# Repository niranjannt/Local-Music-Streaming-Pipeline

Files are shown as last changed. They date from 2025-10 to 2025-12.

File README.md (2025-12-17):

# Local Music Streaming Pipeline (ECE 445L Final Project)

This repository contains the final project for **Embedded Design Laboratory (ECE 445L)** at **UT Austin**, developed by Niranjan Telkikar, Ashton Knecht, Thompson Truong, and Nathan DeLaRosa. The project implements a music-streaming pipeline using local WAV files, combining frontend/backend software with embedded hardware.

## Project Overview

Our system streams music from a web interface to an **ESP32-Devkit-V1** and outputs audio through a **12-bit SPI DAC** connected to a headphone jack. The pipeline includes both **analog and digital filters** controlled in real-time by circular potentiometers, allowing adjustment of treble, mid, bass, and digital effects such as flanger, distortion, and reverb.

### Pipeline Flow

1. **Web Interface**: Streams WAV files via Java Serial library to the ESP32 through a USB-UART converter.  
2. **ESP32**: Receives serial data and sends it to the SPI DAC (mono channel). It also handles digital filter adjustments.  
3. **DAC**: Outputs analog audio to headphones.  
4. **TM4C123GH6PM**: Reads potentiometer inputs for analog filters and adjusts MOSFET gain circuits for treble, mid, and bass channels in real-time.  
5. **Visualizer**: Displays right-bass changes in real-time using ADC input from the TM4C.

---

## Team Contributions

- **Ashton Knecht**:  
  - Designed and soldered the PCB with ESP32-Devkit-V1.  
  - Implemented MOSFET gain circuits for analog filters.  
  - Carefully routed PCB to minimize trace length.

- **Thompson Truong**:  
  - Designed the enclosure and circular potentiometers for analog and digital filter control.  
  - Developed ESP-IDF code for digital filters on the ESP32 and analog filters on the TM4C.

- **Nathan DeLaRosa**:  
  - Implemented audio playback and backend/frontend for the web interface.  
  - Wrote ESP-IDF code for streaming audio.

- **Niranjan Telkikar**:  
  - Wrote and tested the **mono DAC_Out function** for the ESP32 (Arduino IDE/ESP-IDF).  
  - Developed a basic visualizer for real-time bass monitoring.  
  - Assisted with hardware debugging and ESP-IDF integration.

---

## Hardware Components

- ESP32-Devkit-V1  
- TM4C123GH6PM microcontroller  
- 12-bit SPI DAC (mono)  
- MOSFET-based analog gain circuits  
- Circular potentiometers for analog and digital filters  
- Headphone jack for output audio

---

## Software Components

- Arduino IDE / ESP-IDF framework for microcontroller programming  
- Java Serial library for web-to-ESP32 streaming  
- Frontend/backend web interface for music streaming  
- Real-time visualizer reading ADC inputs from TM4C

---

## Usage

1. Connect the ESP32 and TM4C to your computer via USB.  
2. Launch the web interface to stream WAV files.  
3. Adjust analog and digital filters using the circular potentiometers.  
4. Observe audio output through headphones and visualizer display.

---

## [Download a demo video of the project here!](Embedded-Lab-Final-Project-Demo.mp4)

## Acknowledgements

This project was completed as part of **ECE 445L: Embedded Design Laboratory** at **UT Austin**.

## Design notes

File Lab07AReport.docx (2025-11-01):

Name: __Nathan DeLaRosa, Ashton Knecht, Thompson Truong, Niranjan Telkikar

EID: __nad2333, atk836, TT27224, NNT479_____

Semester: Fall 2025

Course: ECE445L

All team members have reviewed and approved team skills contract (https://users.ece.utexas.edu/~valvano/EE445L/ebook/Chapter3_HumanInterfaces.htm) (Yes/No):

https://docs.google.com/document/d/1b0H_l2s_C3Buwb_I0p0ZEJCIzjKjUqObAgL3oR6PWzI/edit?usp=sharing

Deliverable 1: I have pushed my updated Requirements document to GitHub (Yes/No):

Yes

Deliverable 2: I have pushed my KiCad preliminary schematic to GitHub (Yes/No):

Yes

Deliverable 3: I have pushed my updated BOM to GitHub (Yes/No):

Yes

Deliverable 4: List the needed supply voltages and estimated current for each voltage (show how these were determined).

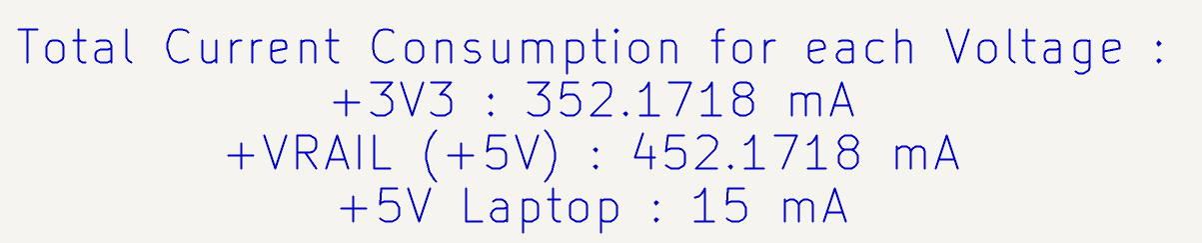
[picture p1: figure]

How estimated currents were determined (On the Schematic)

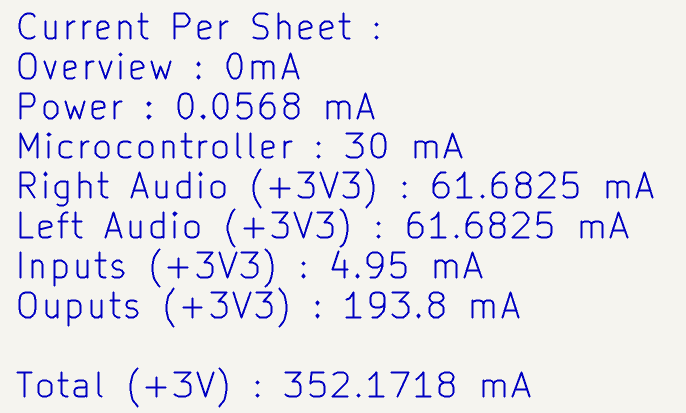
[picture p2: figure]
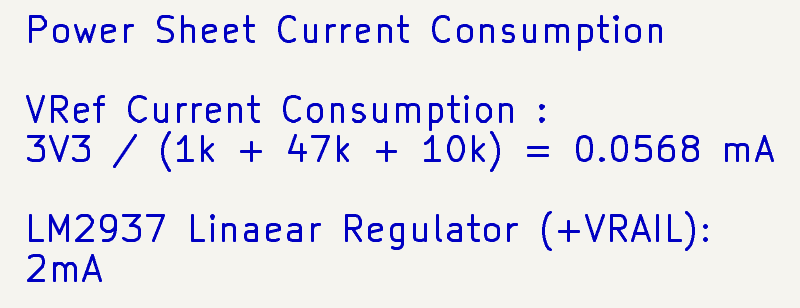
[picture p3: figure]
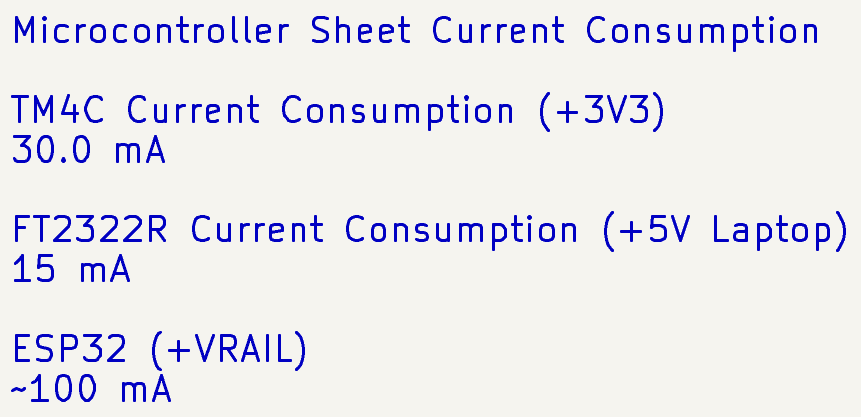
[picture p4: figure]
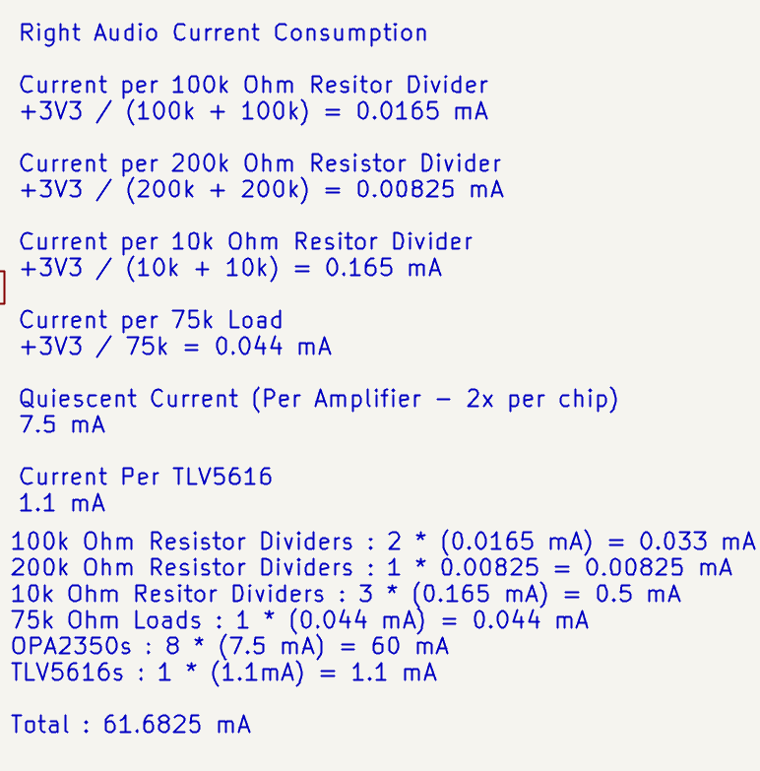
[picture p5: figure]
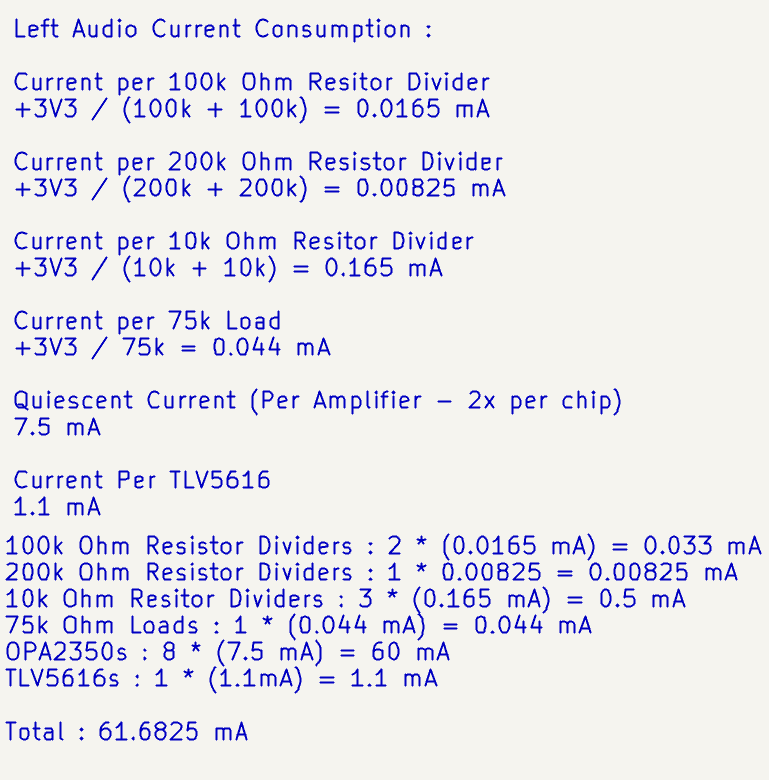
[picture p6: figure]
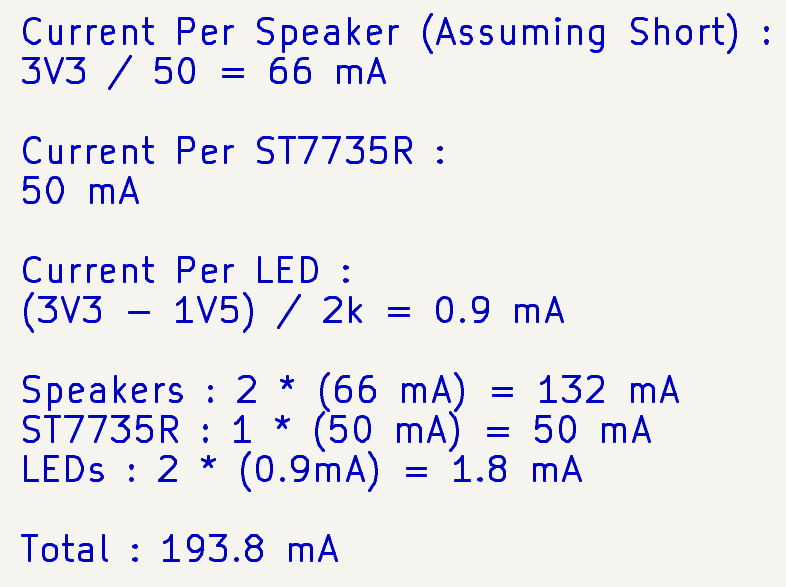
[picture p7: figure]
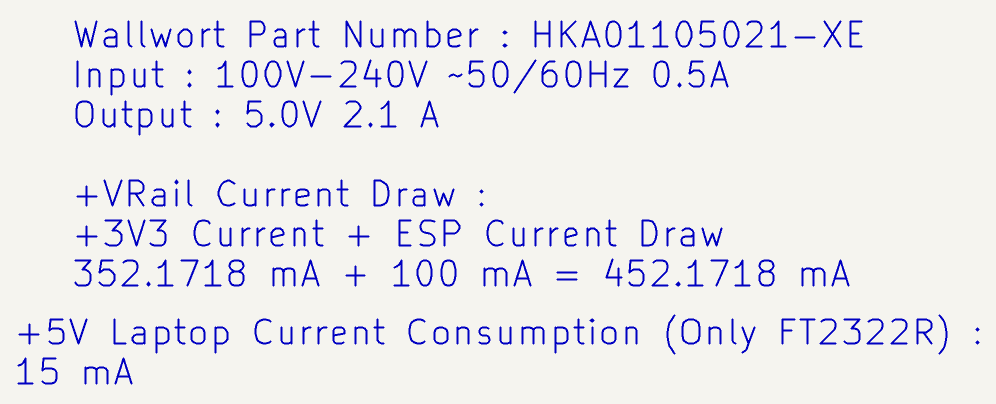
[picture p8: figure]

Deliverable 5: I have pushed my low-level header, code, and unit test files to GitHub (Yes/No):

Yes

Deliverable 6: Include results of unit testing.

Testing of bass channel with increasing frequency

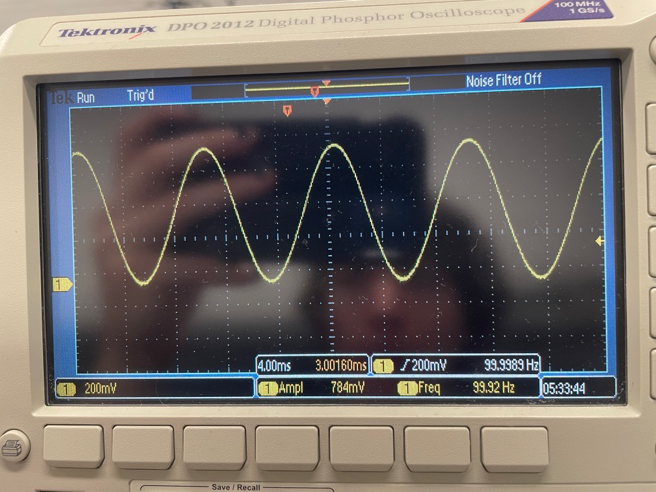
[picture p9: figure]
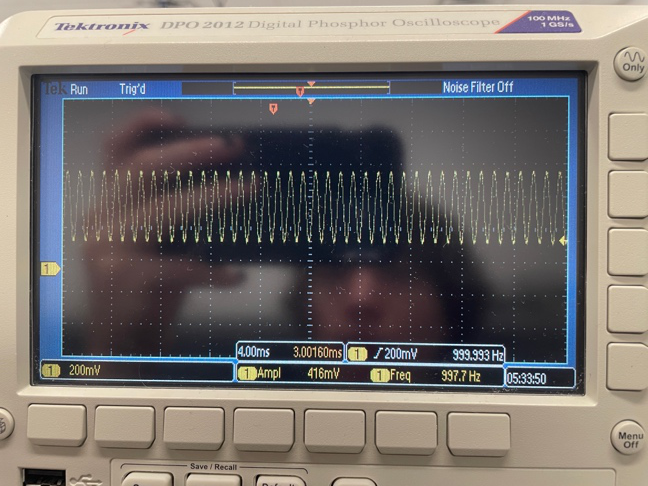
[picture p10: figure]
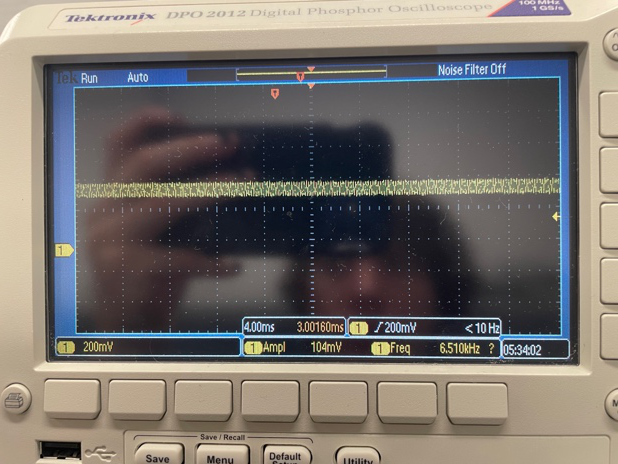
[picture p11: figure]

Testing of mid channel with increasing frequency

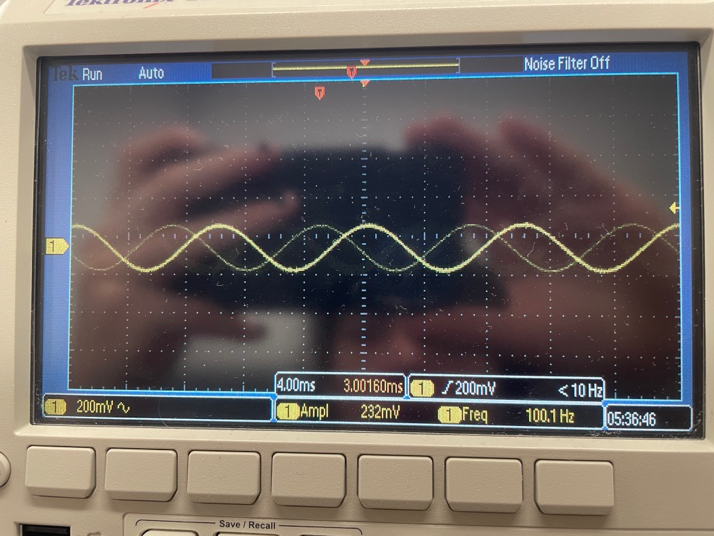
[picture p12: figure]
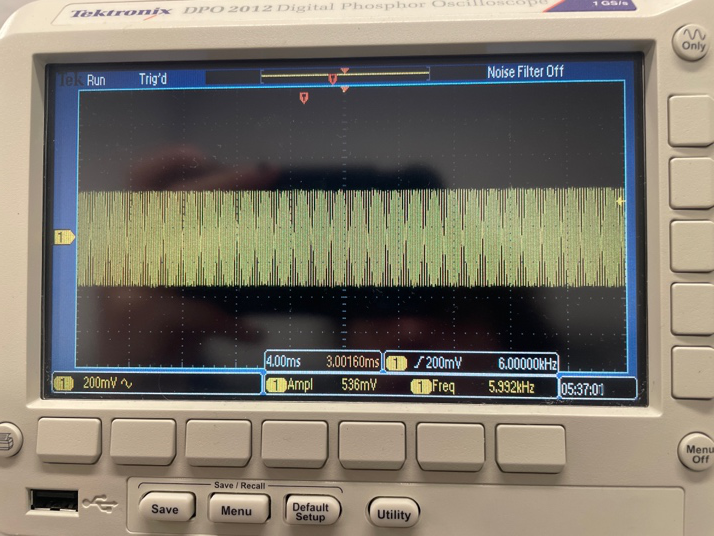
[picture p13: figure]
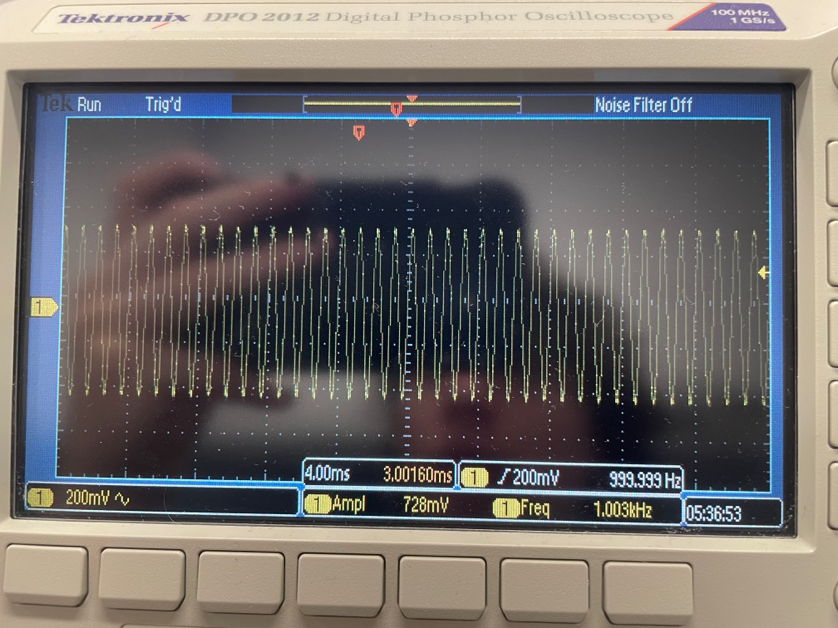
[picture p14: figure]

Testing of the treble channel with increasing frequency

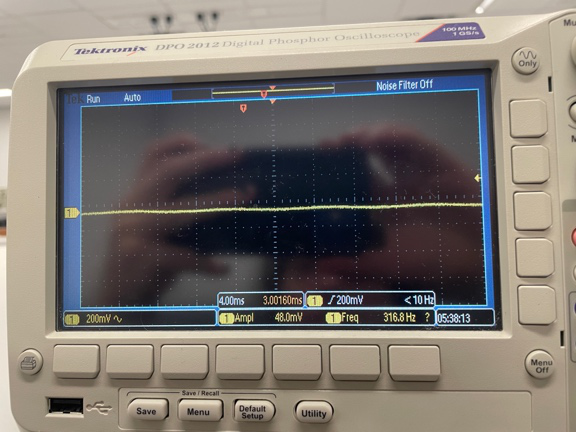
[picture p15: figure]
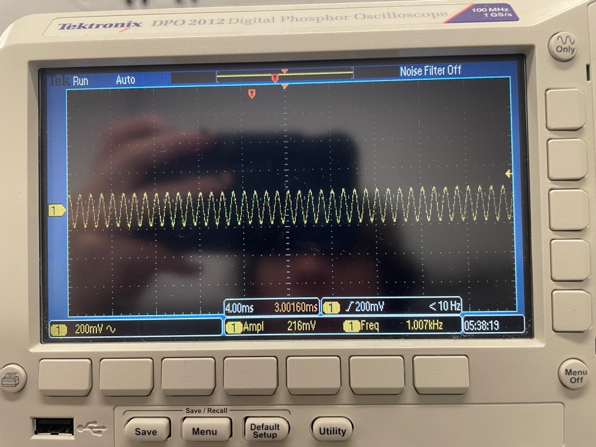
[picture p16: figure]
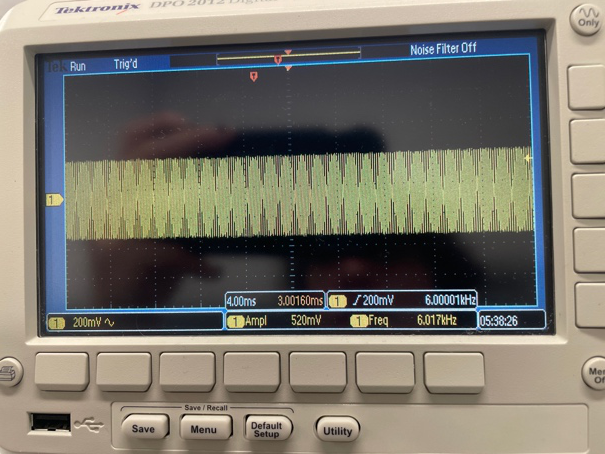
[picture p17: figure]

Testing with summed channels with increasing frequency (Intentionally attenuated)

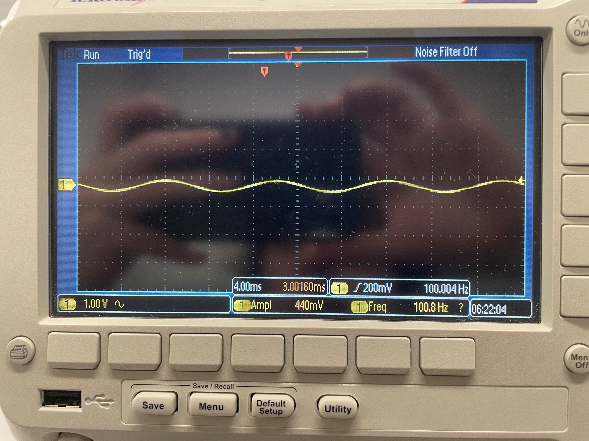
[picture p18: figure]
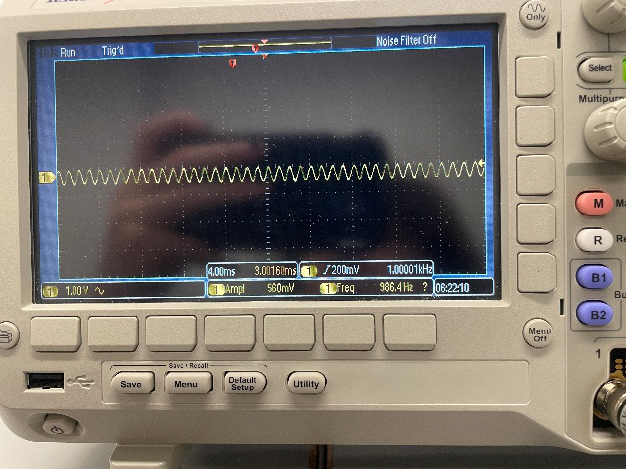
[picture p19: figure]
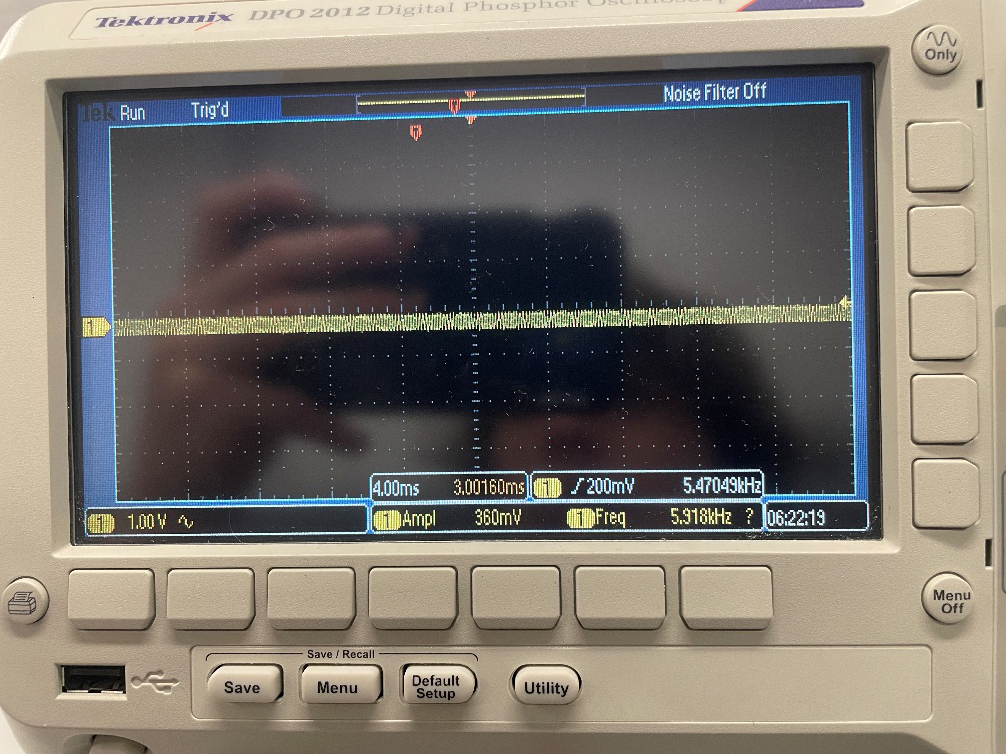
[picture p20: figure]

Testing 1 and 2 channel output from DAC

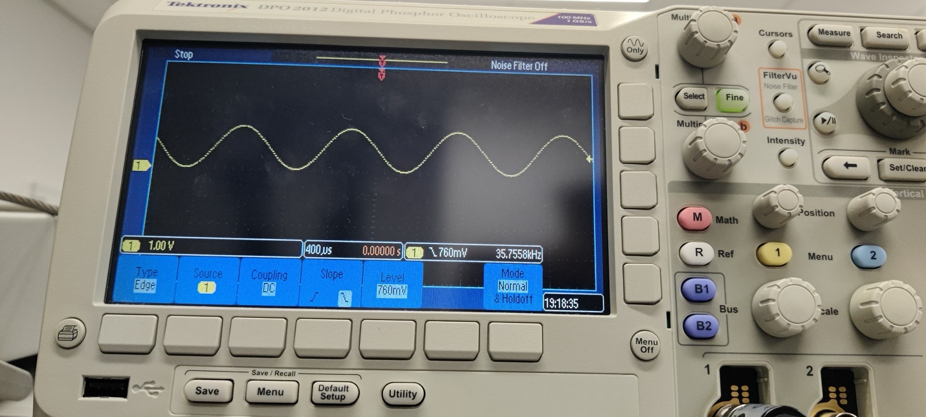
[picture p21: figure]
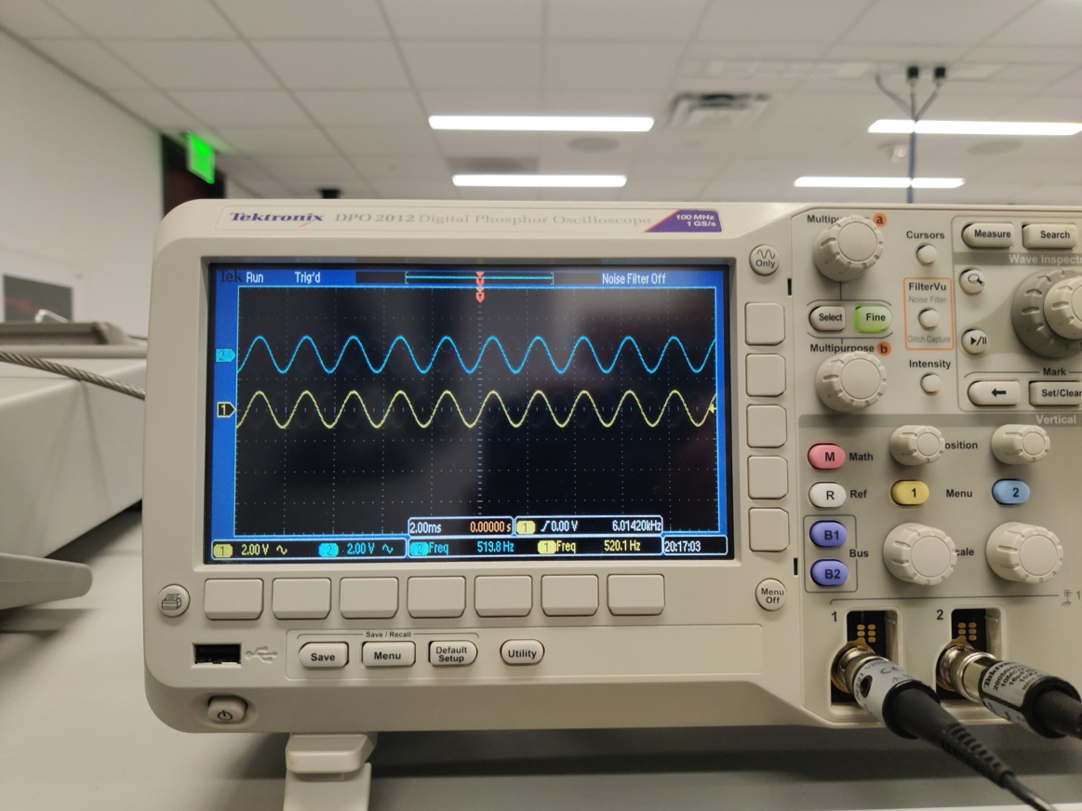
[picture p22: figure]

Testing of getting audio format from WAV file

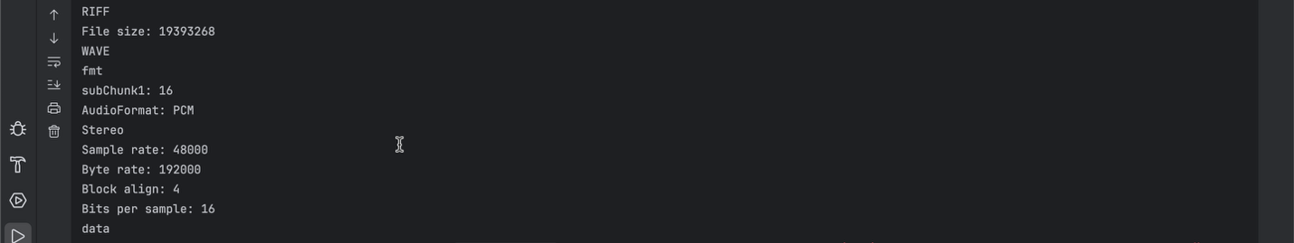
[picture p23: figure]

Deliverable 7 (5pt EC): Show dated proof of TIW Training (due at the time of Lab7A report)

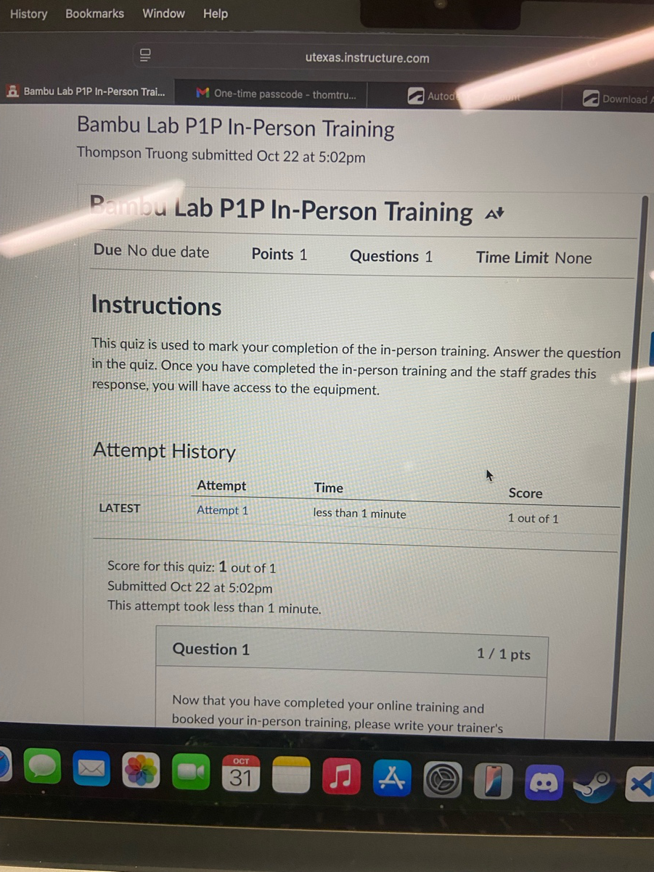
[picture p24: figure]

Deliverable 8 (10pt EC): single chip (points given in Lab 10 if the single chip works)

We have the tm4c chip in the schematic/layout but are planning to remove it for board space.

Analysis and Discussion Questions:

1. List the debugging techniques you used to do unit testing? How intrusive were they?

To make sure we were getting correct data when parsing the WAV file, we used simple print statements to make sure they are coherent. Although printing is typically very intrusive, the statements wouldn’t interrupt any time-sensitive process.

To verify data was being sent over correctly from the laptop to the ESP, we printed data from the serial port. This was very intrusive and gave the illusion of garbage values since the processor couldn’t keep up with the rate at which the serial port wanted to print. Slowing down the print showed correct values.

We used the oscilloscope to test DAC output and the output from the analog circuit, which was non-intrusive.

2. What are the differences between unit testing, integration testing, and functional testing?

Unit testing tests the function of a single part of the system. Unit testing typically isolates a single module to ensure its functionality.

Integration testing tests how different parts of the system interact with each other, such as if the software and hardware are sending each other the correct signals, data being sent through UART, and data moving correctly through the data flow.

Functional testing tests the functionality of the whole system, and simulates of a user would interact with the system.

Lab 7A report ECE445L

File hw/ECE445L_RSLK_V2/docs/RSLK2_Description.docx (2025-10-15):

RSLK-2.02 July 2024

Major components

- Either TM4C123 or MSPM0G3507 LaunchPad
- Romi chassis, 2 motors, 2 tachometers
- 3 analog connectors for GP2Y0A21YK0F or GP2Y0A41SK0F
- 4 bump sensors on front
- TOF TF-Luna UART
- ESP8266
- SSD1306 OLED
- Solderless breadboard as a spoiler

Components to go on spoiler.

- LCD (SPI)
- LEDs
- Anything I2C


Pololu Parts needed

1 - Romi Chassis Kit 3500 to 3509

4 - KW11-2 Bump switch 1404

2 - Romi motors 3675

Construction plan

LaunchPad from TI

Parts from Pololu

Parts from Mouser

Parts from Amazon

JLCPCB with assembly of surface mount parts

Hand solder through hole parts

Power configurations with TM4C123 LaunchPad

When debugging with USB cable connected

LaunchPad jumper inserted

LaunchPad switch to DEBUG

LaunchPad LP3.3V jumper removed

LaunchPad LP 5V jumper removed

6 Ni-MH batteries inserted

7.2V power switch on or off as needed (motors, tach, ESP, OLED, IR, TFluna)

When running stand alone (USB not connected or USB switch in DEVICE)

LaunchPad jumper inserted (debugger needs power even if not debugging)

LaunchPad LP 3.3V jumper removed

LaunchPad LP 5V jumper removed

6 Ni-MH batteries inserted

7.2V power switch on

When debugging with USB cable connected just sensors and ESP8266, no tach, no motors

LaunchPad jumper inserted

LaunchPad switch to DEBUG

LaunchPad LP 3.3V jumper inserted

LaunchPad LP 5V jumper inserted

NO Ni-MH batteries

7.2V power switch on or off does not matter because no batteries


// Bump switches

// TM4C MSPM0

// PA5 PA27 Left, Bump 0,

// PF0 PB15 Center Left, Bump 1,

// PB3 PA28 Center Right, Bump 2

// PC4 PA31 Right, Bump 3

// Motor

// TM4C MSPM0

// PF2 PB4 Motor_PWML, ML+, IN3, PWM M1PWM6

// PF3 PB1 Motor_PWMR, MR+, IN1, PWM M1PWM7

// PA3 PB0 Motor_DIR_L,ML-, IN4, GPIO 0 means forward, 1 means back

// PA2 PB16 Motor_DIR_R,MR-, IN2, GPIO 0 means forward, 1 means back

// tachometer

// TM4C MSPM0

// PB7 PB8 ELA T0CCP1

// PB2 PB12 ERA T3CCP0

// ERB and ELB not connected

// SSD1306 I2C OLED

// TM4C MSPM0

// PA6 PB2 SCL I2C clock

// PA7 PB3 SDA I2C data

// IR analog distance sensors

// TM4C MSPM0

// PE4 PA26 Right Ain9

// PE5 PB24 Center Ain8

// PE1 PA24 Left Ain2

// TF Luna TOF distance sensor

// TM4C MSPM0

// PB1 PA8 TxD microcontroller sensor RxD pin 2

// PB0 PA9 RxD microcontroller sensor TxD pin 3

// LaunchPad pins

// PF4 S2 negative logic switch

// PF0 S1 negative logic switch (shared with Bump 1)

/* Vcc should be connected to RSLK 3.3V (not debugger)

/------------------------------\

| chip 1 8 |

| Ant 2 7 |

| enna processor 3 6 |

| 4 5 |

Set #define for UART2 (PD) and Reset PB5

ESP8266 TM4C123 MSPM0 (UART selected by jumper)

1 URxD PD7 PB17 UART out of TM4C123, 115200 baud

2 GPIO0 +3.3V for normal operation (ground to flash)

3 GPIO2 PB4 PB9

4 GND Gnd Gnd GND (70mA)

5 UTxD PD6 PB18 UART out of ESP8266, 115200 baud

6 Ch_PD chip select, 10k resistor to 3.3V

7 Reset PB5 PA25 Software can issue output low to cause hardware reset

8 Vcc regulated 3.3V supply with at least 70mA

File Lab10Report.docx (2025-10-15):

Name: __Replace with your name(s)____

EID: __Replace with your EID(s)_____

Semester: Fall 2025

Course: ECE445L

A) Objectives:

1. In a few sentences, describe the purpose of the lab and the features of your alarm clock.

B) Hardware Design Deliverables:

1. N/A

C) Software Design Deliverables:

1. I have pushed my project to GitHub for grading (Yes/No):
2. Deliverable 1: System design diagram of the modules created.

D) General Deliverables:

1. Deliverable 2: Software Tests
2. Deliverable 3: Hardware Tests
3. Deliverable 4: Power consumption
4. Deliverable 5 (10pt EC): Characterization of the system

E) Analysis and Discussion Questions:

1. N/A

Lab 10 report ECE445L

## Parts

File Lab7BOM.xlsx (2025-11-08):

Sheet: BOM_NEW_2
Bill of Materials |  |  | 2025-11-07 |  |  |  |  |  | "not free" means you have to buy it |  | "free sample" means you have to order it
ECE445L Spring 2025 |  |  | EE445L pays for the PCB |  |  |  |  |  | "Cabinet means in one of the six black cabinets in professsor's office (bring a print out of your SCH")
 |  |  |  |  |  |  |  |  | "Professor" means ask your professor quantity and style will vary (bring a print out of your SCH circuit)
Qty Note | REF DES Note (http://projects.ece.utexas.edu/valvano/wiki/doku.php?id=pcbartist:schematics) |  |  |  |  |  |  |  | "Box means in box in your professor's office (bring a print out of your SCH circuit)
Quantity | REF DES | Type | Value | Description | Footprint | Tolerance | Power Raiting | Type/Dielectric | Manufacturer | Mfg. P/N | Distributor | P/N | Unit cost | Cost | Where to get it? | Inventory
19 | C1, C3, C9, C10, C11, C12, C13, C15, C21, C22, C23, C24, C25, C27,C28, C29, C30, C31, C32, C33, C34 | CAP | 0.1u | CAP CER 0.1UF 50V X7R 0603 | 0603 | 10% | 50V | X7R | Samsung Electro-Mechanics | CL10B104KB8NFNC | Mouser | 187-CL10B104KB8NFNC | 0.013 | 0.247 | Mouser | https://www.samsungsem.com/resources/file/global/support/product_catalog/MLCC.pdf
3 | C2, C14, C26 | CAP | 10u | CAP CER 10UF 10V X7R 0805 | 0805 | 10% | 10V | X7R | Samsung Electro-Mechanics | CL21B106KPQNNNE | Mouser | 187-CL21B106KPQNNNE | 0.023 | 0.069 | Mouser | https://mm.digikey.com/Volume0/opasdata/d220001/medias/docus/993/CL21B106KPQNNNE_Spec.pdf
4 | C4, C6, C16, C18 | CAP | 1.2n | CAP CER 1200PF 50V C0G/NP0 0603 | 0603 | 5% | 50V | C0G/NP0 | Murata | GRM1885C1H122JA01D | Mouser | 81-GRM1885C1H122JA01 | 0.027 | 0.108 | Mouser | https://search.murata.co.jp/Ceramy/image/img/A01X/G101/ENG/GRM1885C1H122JA01-01.pdf
4 | C5, C7, C17, C19 | CAP | 30n | CAP CER 3000PF 50V C0G/NP0 0603 | 0603 | 5% | 50V | C0G/NP0 | Murata | GCM1885C1H302JA16D | Mouser | 81-GCM1885C1H302JA6D | 0.032 | 0.128 |  | https://mm.digikey.com/Volume0/opasdata/d220001/medias/docus/4832/RMC_Style_DS.pdf
2 | C8, C20 | CAP | 0.01u | CAP CER 10000PF 50V C0G/NP0 0603 | 0603 | 5% | 50V | C0G/NP0 | Murata | GRM1885C1H103JA01J | Mouser | 81-GRM1885C1H103JA1J | 0.051 | 0.102 | Mouser | https://search.murata.co.jp/Ceramy/image/img/A01X/G101/ENG/GRM1885C1H103JA01-01.pdf
2 | C9, C21 | CAP | 3.6n | CAP CER 3600PF 50V C0G/NP0 0603 | 0603 | 5% | 50V | C0G/NP0 | Murata | GRM1885C1H362JA01D | Mouser | 81-GRM1885C1H362JA1D | 0.04 | 0.08 | Mouser | https://search.murata.co.jp/Ceramy/image/img/A01X/G101/ENG/GRM1885C1H362JA01-01A.pdf
3 | D1, D2, D5 | Diode | 1.6V | LED RED DIFFUSED T-1 3/4 T/H | TH | n/a | 20mA | LED | Broadcom Limited | HLMP-D150 | Digikey | 516-1323-ND | $0.40 | 0 | Checkout Window | https://users.ece.utexas.edu/%7Evalvano/Datasheets/LEDHLMP-D150.pdf
2 | D3, D4 | Diode | 1.2V | DIODE STANDARD 75V 200MA DO204AH | TH | n/a | 200mA | Standard | Onsemi | 1N914 | Mouser | 512-1N914 | $0.04 | 0 | Checkout Window | https://users.ece.utexas.edu/%7Evalvano/Datasheets/1N914.pdf
1 | J1 | CONN | n/a | USB-C CHARGE ONLY RECEPTACLE,6 P | TH | n/a | 3A | n/a | TE Connectivity Linx | 2479774-1 | Mouser | 571-2479774-1 | $0.61 | 0.61 | Mouser | https://www.te.com/commerce/DocumentDelivery/DDEController?Action=showdoc
1 | J2 | CONN | 5POS | CONN HEADER VERT 36000POS 2.54MM | TH | n/a | n/a | n/a | Amphenol ICC (FCI) | 77311-418-00LF | DigiKey | 609-77311-418-00LFCT-ND | $0.10 | 0 | Checkout | https://cdn.amphenol-cs.com/media/wysiwyg/files/documentation/datasheet/boardwiretoboard/bwb_bergstik.pdf
1 | J3 | CONN | n/a | CONN JACK STEREO 3.5MM TH R/A | TH | n/a | 16V | n/a | Kycon, Inc. | STX-3000 | Mouser | 806-STX-3000 | $0.79 | 0.79 | Mouser | https://www.kycon.com/Pub_Eng_Draw/STX-3000.pdf
16 | Q1, Q2, Q3, Q4, Q5, Q6, Q7, Q8, Q9, Q10, Q11, Q12, Q13, Q14, Q15, Q16 | FET | n/a | N-Channel 60 V 500mA (Ta) 300mW (Ta) Surface Mount SOT-23-3 | SOT-23-3 | n/a | 500mA | n-type | Onsemi | MMBF-170 | Mouser | 512-MMBF170 | $0.16 | 2.528 | Mouser | https://www.onsemi.com/pdf/datasheet/mmbf170-d.pdf
2 | R1, R2 | RES | 5K1 | RES SMD 5.1K OHM 1% 1/10W 0603 | 0603 | 1% | 1/10W | Thin Film | YAGEO | RT0603FRD075K1L | Mouser | 603-RT0603FRD075K1L | 0.031 | 0.062 | Mouser | https://www.mouser.com/datasheet/3/508/1/PYu-RT_1-to-0.01_RoHS_L_15.pdf
1 | R3 | RES | 1k | RES 1K OHM 0.5% 1/10W 0603 | 0603 | 0.50% | 1/10W | Thin Film | KOA Speer Electronics, Inc. | RN73R1JTTD1001D25 | Mouser | 660-RN73R1JTD1001D25 | 0.055 | 0.055 | Mouser | https://www.koaspeer.com/pdfs/RN73R.pdf
1 | R4 | RES | 47k | RES 47K OHM 1% 1/10W 0603 | 0603 | 1% | 1/10W | Thick Film | YAGEO | AC0603FR-1047KL | Mouser | 603-AC0603FR-1047KL | 0.06 | 0.06 | Mouser | https://www.yageogroup.com/content/datasheet/asset/file/PYU-AC_51_ROHS_L
19 | R5, R9, R10, R12, R20, R21, R31, R33, R35, R36, R42, R43, R46, R53, R54, R62, R64, R65, R67 | RES | 10k | RES 10K OHM 1% 1/8W 0603 | 0603 | 1% | 1/8W | Thin Film | Stackpole Electronics Inc | RNCP0603FTD10K0 | Mouser | 708-RNCP0603FTD10K0 | 0.009 | 0.171 | Mouser | https://www.seielect.com/catalog/SEI-RNCP.pdf
5 | R6, R7, R8, R27, R29 | RES | 0R | RES 0 OHM JUMPER 0603 | 0603 | n/a | 1/16W | Thick Film | Kamaya | RMC1/16JPTP | Mouser | 791-RMC1/16JPTP | 0.027 | 0.135 | Mouser | https://www.mouser.com/catalog/specsheets/Kamaya_RMC_series_8_2022.pdf
18 | R11, R13, R22, R23, R24, R32, R44, R45, R56, R57, R63, R103, R104, R105, R109, R110, R111 | RES | 2k | 2 kOhms ±1% 0.125W, 1/8W Chip Resistor 0603 (1608 Metric) Anti-Sulfur Thin Film | 0603 | 1% | 1/8W | Thin Film | Stackpole Electronics Inc | RNCP0603FTD2K00 | Mouser | 708-RNCP0603FTD2K00 | 0.01 | 0.18 | Mouser | https://www.seielect.com/catalog/SEI-RNCP.pdf
4 | R14, R25, R47, R58 | RES | 184k | RES 184K OHM 0.5% 1/10W 0603 | 0603 | 0.50% | 1/10W | Thin Film | Yageo | RT0603DRE07184KL | Mouser | 603-RT0603DRE07184KL | 0.018 | 0.072 | Mouser | https://www.yageogroup.com/browse/products?search=pyu-rt_1-to-0.01_rohs_l.pdf
4 | R15, R26, R48, R59 | RES | 68.8k | RES SMD 68.1KOHM 0.1% 1/10W 0603 | 0603 | 0.10% | 1/10W | Thin Film | Panasonic | ERA-3AEB6812V | Mouser | 667-ERA-3AEB6812V | 0.054 | 0.216 | Mouser | https://industrial.panasonic.com/cdbs/www-data/pdf/RDM0000/AOA0000C307.pdf
8 | R16, R17, R28, R37, R49, R50, R60, R68 | RES | 40k | RES 40K OHM 0.1% 1/10W 0603 | 0603 | 0.10% | 1/10W | Thin Film | YAGEO | RT0603BRD0740KL | Mouser | 603-RT0603BRD0740KL | 0.049 | 0.392 | Mouser | https://www.mouser.com/datasheet/3/508/1/PYu-RT_1-to-0.01_RoHS_L_15.pdf
6 | R18, R19, R30, R51, R52, R61 | RES | 30k | RES SMD 30K OHM 1% 1/10W 0603 | 0603 | 1% | 1/10W | Thin Film | YAGEO | RT0603FRE0730KL | Mouser | 603-RT0603FRE0730KL | 0.015 | 0.09 | Mouser | https://www.mouser.com/datasheet/3/508/1/PYu-RT_1-to-0.01_RoHS_L_15.pdf
2 | R34, R66 | RES | 7.5k | RES 7.5K OHM 1% 1/8W 0603 | 0603 | 1% | 1/8W | Thick Film | Stackpole Electronics Inc | RNCP0603FTD7K50 | Mouser | 708-RNCP0603FTD7K50 | 0.011 | 0.022 | Mouser | https://www.mouser.com/datasheet/3/1099/1/SEI-RNCP.pdf
2 | R38, R69 | RES | 3.3k | RES 3.3K OHM 5% 1/10W 0603 | 0603 | 5% | 1/10W | Thick Film | Stackpole Electronics Inc | RMCF0603JT3K30 | Mouser | 708-RMCF0603JT3K30 | 0.007 | 0.014 | Mouser | https://www.mouser.com/datasheet/3/1099/1/SEI_RMCF_RMCP.pdf
4 | R39, R40, R70, R71 | RES | 200k | RES 200K OHM 0.5% 1/10W 0603 | 0603 | 0.50% | 1/10W | Thick Film | YAGEO | RC0603DR-07200KL | Mouser | 603-RC0603DR-07200KL | 0.015 | 0.06 | Mouser | https://www.yageogroup.com/content/datasheet/asset/file/PYU-RC_GROUP_51_ROHS_L
2 | R51, R72 | RES | 50k | RES SMD 49.9KOHM 0.5% 1/10W 0603 | 0603 | 0.50% | 1/10W | Thin Film | YAGEO | RT0603DRD0749K9L | Mouser | 603-RT0603DRD0749K9L | 0.05 | 0.1 | Mouser | https://www.mouser.com/datasheet/3/508/1/PYu-RT_1-to-0.01_RoHS_L_15.pdf
7 | R73, R75, R77, R79, R81, R84, R88 | RES | 100k | RES SMD 100K OHM 0.5% 1/6W 0603 | 0603 | 0.50% | 1/6W | Thin FIlm | Stackpole Electronics Inc | RNCF0603DTE100K | Mouser | 708-RNCF0603DTE100K | 0.02 | 0.14 | Mouser | https://www.seielect.com/catalog/SEI-RNCF.pdf
8 | R74, R76, R78, R80, R85, R89, R101, R107 | RES | 100R | RES 100 OHM 0.5% 1/4W 0603 | 0603 | 0.50% | 1/4W | Thin Film | Vishay | MCT0603PD1000DP500 | Mouser | 594-MCT0603PD1000DP5 | 0.094 | 0.752 | Mouser | https://www.vishay.com/docs/28916/mcxhp.pdf
8 | R83, R86, R87, R90, R91, R92, R93, R94 | POT | 10k | POT 10K OHM 1/20W PLASTIC LINEAR | TH | n/a | 1/20W | Linear | TT Electrtonics/BI | P120PK-Y25BR10K | Mouser | 858-P120PKY25BR10K | 1.017 | 8.136 | Mouser | https://mm.digikey.com/Volume0/opasdata/d220001/medias/docus/569/P120_Series_DS.pdf
3 | R95, R98, R99 | RES | 1.5k | RES 1.5K OHM 1% 1/10W 0603 | 0603 | 1% | 1/10W | Thin Film | YAGEO | RT0603FRE101K5L | Mouser | 603-RT0603FRE101K5L | 0.016 | 0.048 | Mouser | https://www.yageogroup.com/browse/products?search=pyu-rt_1-to-0.01_rohs_l.pdf
2 | R96, R97 | RES | 50R | RES SMD 51 OHM 5% 1/4W 0805 | 0603 | 5% | 1/4W | Thick FIlm | KOA Speer Electronics, Inc. | RK73B2ATTDD510J | Mouser | 660-RK73B2ATTDD510J | 0.026 | 0.052 | Mouser | https://www.koaspeer.com/pdfs/RK73B.pdf
2 | R100, R106 | RES | 176R | RES 176 OHM 0.5% 1/10W 0603 | 0603 | 0.50% | 1/8W | Thin Film | KOA Speer Electronics, Inc. | RN73H1JTTD1760D25 | Mouser | 660-RN73H1JTD1760D25 | 0.09 | 0.18 | Mouser | https://www.mouser.com/catalog/specsheets/KOA_Speer_RN73H_8_21_24.pdf
2 | R102, R108 | RES | 75R | RES SMD 75 OHM 0.1% 1/6W 0603 | 603 | 0.1% | 1/6W | Thin Film | TE Connectivity / Holsworthy | RP73PF1J75RBTDF | Mouser | 279-RP73PF1J75RBTDF | 0.215 | 0.43 | Mouser | https://www.te.com/commerce/DocumentDelivery/DDEController?Action=showdoc
1 | SW1 | SW | n/a | SWITCH TOGGLE SPST 3A 125V | TH | n/a | 3A/125V | n/a | Adam Tech | SW-T3-1A-A-A3-S1 | Mouser | 737-SW-T3-1A-A-A3-S1 | $0.98 | 0.98 | Mouser | https://www.mouser.com/datasheet/3/6015/1/sw-t3-1a-a-a3-s1-data-sheet.pdf
7 | SW2, SW3, SW4, SW5, SW6, SW7, SW8 | SW | n/a | SWITCH TACTILE SPST-NO 0.05A 24V | TH | n/a | 5ma | n/a | Omron Electronics Inc-EMC Div | B3F-1000 | Digikey | SW400-ND | $0.00 | 0 | Checkout | https://users.ece.utexas.edu/%7Evalvano/Datasheets/B3F-1059.pdf
1 | U1 | IC | n/a | IC REG LINEAR 3.3V 500MA TO220-3 | TO220-3 | n/a | 500mA | LDO | TI | LM2937ET-3.3/NOPB | Mouser | 926-LM2937ET-3.3NOPB | $1.45 | 0 | Cabinet | https://www.ti.com/lit/ds/symlink/lm2937.pdf
1 | U2 | IC | n/a | LM4041CILPR shunt diode reference | TO92-3 | n/a | n/a | n/a | TI | LM4041CILPR | TI | LM4041CILPR | $0.90 | 0 | Cabinet | https://www.ti.com/general/docs/suppproductinfo.tsp?distId=10
1 | U3 | CPU | n/a | IC RF TXRX+MCU BLE 48QFN | 48QFN | n/a | n/a | n/a | Espressif Systems | ESP32-D0WD-V3 | DigiKey | 1904-ESP32-D0WD-V3 | $1.68 | 0 | Already Owned | https://documentation.espressif.com/esp32_datasheet_en.pdf
1 | U4 | IC | n/a | FT232R FTDI Interface Arduino Platform Evaluation Expansion Board |  | n/a | n/a | n/a | SparkFun Electronics | 12935 | Digikey | 1568-12935-ND | N/A | 0 | McDurmot | https://mm.digikey.com/Volume0/opasdata/d220001/medias/docus/2289/FTDI_SmartBasic_Hookup_Guide.pdf
8 | U5, U6, U7, U8, U10, U11, U12, U13 | IC | n/a | OPA2350 dual op amp | 8-DIP | n/a | n/a | n/a | TI | OPA2350PA | TI | OPA2350PA | $3.91 | 0 | Checkout Window | https://www.ti.com/lit/ds/symlink/opa350.pdf?HQS=dis-dk-null-digikeymode-dsf-pf-null-wwe&ts=1761536704713
2 | U9, U14 | IC | n/a | TLV5616 12-bit DAC | 8DIP | n/a | n/a | n/a | TI | TLV5616 | TI | TLV5616CP | $11.06 | 0 | Cabinet | https://www.ti.com/general/docs/suppproductinfo.tsp?distId=10
1 | U15 | LCD | n/a | DISPL GRAPHIC 1.8 CLR TFT SHIELD | n/a | n/a | n/a | n/a | Adafruit Industries LLC | ST7735R | Digikey | 1528-1352-ND | $34.95 | 0 | Inventory | https://cdn-shop.adafruit.com/datasheets/ST7735R_V0.2.pdf
 |  |  |  |  |  |  |  |  |  |  |  |  |  | $17.01

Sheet: BOM_NEW
Bill of Materials |  |  | 2025-01-07 |  |  |  |  |  | "not free" means you have to buy it |  | "free sample" means you have to order it
ECE445L Spring 2025 |  |  | EE445L pays for the PCB |  |  |  |  |  | "Cabinet means in one of the six black cabinets in professsor's office (bring a print out of your SCH")
 |  |  |  |  |  |  |  |  | "Professor" means ask your professor quantity and style will vary (bring a print out of your SCH circuit)
Qty Note | REF DES Note (http://projects.ece.utexas.edu/valvano/wiki/doku.php?id=pcbartist:schematics) |  |  |  |  |  |  |  | "Box means in box in your professor's office (bring a print out of your SCH circuit)
Quantity | REF DES | Type | Value | Description | Footprint | Tolerance | Power Raiting | Type/Dielectric | Manufacturer | Mfg. P/N | Distributor | P/N | Unit cost | Cost | Where to get it? | Inventory
18 | C1, C3, C5, C8, C9, C10, C21, C22, C23, C24, C26, C33, C34, C35, C36, C38, C39, C40 | CAP | 0.1u | CAP CER 0.1UF 50V X7R 0603 | 0603 | 10% | 50V | X7R | Samsung Electro-Mechanics | CL10B104KB8NFNC | Mouser | 187-CL10B104KB8NFNC | 0.013 | 0.234 | Mouser | https://www.samsungsem.com/resources/file/global/support/product_catalog/MLCC.pdf
3 | C2, C25, C37 | CAP | 10u | CAP CER 10UF 10V X7R 0805 | 0805 | 10% | 10V | X7R | Samsung Electro-Mechanics | CL21B106KPQNNNE | Mouser | 187-CL21B106KPQNNNE | 0.023 | 0.069 | Mouser | https://mm.digikey.com/Volume0/opasdata/d220001/medias/docus/993/CL21B106KPQNNNE_Spec.pdf
2 | C4, C11 | CAP | 0.01u | CAP CER 10000PF 50V C0G/NP0 0603 | 0603 | 5% | 50V | C0G/NP0 | Murata | GRM1885C1H103JA01J | Mouser | 81-GRM1885C1H103JA1J | 0.051 | 0.102 | Mouser | https://search.murata.co.jp/Ceramy/image/img/A01X/G101/ENG/GRM1885C1H103JA01-01.pdf
2 | C6, C14 | CAP | 1.0u | CAP CER 1UF 10V X7R 0603 | 0603 | 10% | 25V | X7R | Taiyo Yuden | MSAST168SB7105KTNA01 | Mouser | 963-MSAST168SB7105KT | 0.036 | 0.072 | Mouser | https://mm.digikey.com/Volume0/opasdata/d220001/medias/docus/4819/TMK107B7105KA-T_SS.pdf
1 | C7 | CAP | 2.2u | CAP TANT 2.2UF 10% 25V 1206 | 1206 | 10% | 25V | Tant | KYOCERA AVX | F931E225KAA | Mouser | 647-F931E225KAA | 2.08 | 2.08 | Mouser | https://datasheets.kyocera-avx.com/F93.pdf
2 | C12, C13 | CAP | 10p | CAP CER 10PF 50V C0G/NP0 0603 | 0603 | 1% | 50V | C0G/NP0 | Walsin Technology Corporation | 0603N100F500CT | Mouser | 791-0603N100F500CT | 0.025 | 0.05 | Mouser | https://www.passivecomponent.com/wp-content/uploads/datasheet/WTC_MLCC_General_Purpose.pdf
4 | C15, C17, C27, C29 | CAP | 1.2n | CAP CER 1200PF 50V C0G/NP0 0603 | 0603 | 5% | 50V | C0G/NP0 | Murata | GRM1885C1H122JA01D | Mouser | 81-GRM1885C1H122JA01 | 0.027 | 0.108 | Mouser | https://search.murata.co.jp/Ceramy/image/img/A01X/G101/ENG/GRM1885C1H122JA01-01.pdf
4 | C16, C18, C28, C30 | CAP | 30n | CAP CER 3000PF 50V C0G/NP0 0603 | 0603 | 5% | 50V | C0G/NP0 | Murata | GCM1885C1H302JA16D | Mouser | 81-GCM1885C1H302JA6D | 0.032 | 0.128 |  | https://mm.digikey.com/Volume0/opasdata/d220001/medias/docus/4832/RMC_Style_DS.pdf
2 | C19, C31 | CAP | 3.6n | CAP CER 3600PF 50V C0G/NP0 0603 | 0603 | 5% | 50V | C0G/NP0 | Murata | GRM1885C1H362JA01D | Mouser | 81-GRM1885C1H362JA1D | 0.04 | 0.08 | Mouser | https://search.murata.co.jp/Ceramy/image/img/A01X/G101/ENG/GRM1885C1H362JA01-01A.pdf
2 | D1, D2 | Diode | 1.6V | LED RED DIFFUSED T-1 3/4 T/H | TH | n/a | 20mA | LED | Broadcom Limited | HLMP-D150 | Digikey | 516-1323-ND | $0.40 | 0.804 | Checkout Window | https://users.ece.utexas.edu/%7Evalvano/Datasheets/LEDHLMP-D150.pdf
2 | D3, D4 | Diode | 1.2V | DIODE STANDARD 75V 200MA DO204AH | TH | n/a | 200mA | Standard | Onsemi | 1N914 | Mouser | 512-1N914 | $0.04 | 0.08 | Checkout Window | https://users.ece.utexas.edu/%7Evalvano/Datasheets/1N914.pdf
1 | J1 | CONN | n/a | USB-C CHARGE ONLY RECEPTACLE,6 P | TH | n/a | 3A | n/a | TE Connectivity Linx | 2479774-1 | Mouser | 571-2479774-1 | $0.61 | 0.61 | Mouser | https://www.te.com/commerce/DocumentDelivery/DDEController?Action=showdoc
1 | J2 | CONN | n/a | CONN JACK STEREO 3.5MM TH R/A | TH | n/a | 16V | n/a | Kycon, Inc. | STX-3000 | Mouser | 806-STX-3000 | $0.79 | 0.79 | Mouser | https://www.kycon.com/Pub_Eng_Draw/STX-3000.pdf
1 | J3 | CONN | 5POS | CONN HEADER VERT 36000POS 2.54MM | TH | n/a | n/a | n/a | Amphenol ICC (FCI) | 77311-418-00LF | DigiKey | 609-77311-418-00LFCT-ND | $0.10 | 0.1 | Checkout | https://cdn.amphenol-cs.com/media/wysiwyg/files/documentation/datasheet/boardwiretoboard/bwb_bergstik.pdf
16 | Q1, Q2, Q3, Q4, Q5, Q6, Q7, Q8, Q9, Q10, Q11, Q12, Q13, Q14, Q15, Q16 | FET | n/a | TRANS NPN 40V 0.6A SOT23-3 | SOT23-3 | n/a | n/a | npn | Onsemi | MMBT2222ALT1G | Mouser | 863-MMBT2222ALT1G | $0.09 | 1.408 | Mouser | https://www.mouser.com/datasheet/3/101/1/MMBT2222LT1-D.PDF
2 | R1, R2 | RES | 5K1 | RES SMD 5.1K OHM 1% 1/10W 0603 | 0603 | 1% | 1/10W | Thin Film | YAGEO | RT0603FRD075K1L | Mouser | 603-RT0603FRD075K1L | 0.031 | 0.062 | Mouser | https://www.mouser.com/datasheet/3/508/1/PYu-RT_1-to-0.01_RoHS_L_15.pdf
1 | R3 | RES | 1k | RES 1K OHM 0.5% 1/10W 0603 | 0603 | 0.50% | 1/10W | Thin Film | KOA Speer Electronics, Inc. | RN73R1JTTD1001D25 | Mouser | 660-RN73R1JTD1001D25 | 0.055 | 0.055 | Mouser | https://www.koaspeer.com/pdfs/RN73R.pdf
1 | R4 | RES | 47k | RES 47K OHM 1% 1/10W 0603 | 0603 | 1% | 1/10W | Thick Film | YAGEO | AC0603FR-1047KL | Mouser | 603-AC0603FR-1047KL | 0.06 | 0.06 | Mouser | https://www.yageogroup.com/content/datasheet/asset/file/PYU-AC_51_ROHS_L
32 | R5, R7, R8, R9, R14, R15, R16, R17, R21, R22, R24, R26, R27, R39, R40, R41, R46, R47, R48, R49, R53, R54, R55, R57, R58, R70, R71, R72, R73, R74, R75, R76 | RES | 10k | RES 10K OHM 1% 1/8W 0603 | 0603 | 1% | 1/8W | Thin Film | Stackpole Electronics Inc | RNCP0603FTD10K0 | Mouser | 708-RNCP0603FTD10K0 | 0.009 | 0.288 | Mouser | https://www.seielect.com/catalog/SEI-RNCP.pdf
1 | R6 | RES | 1M | RES 1M OHM 5% 1/10W 0603 | 0603 | 5% | 1/10W | Thick Film | YAGEO | RC0603JR-071MP | Mouser | 603-RC0603JR-071MP | 0.01 | 0.01 | Mouser | https://www.yageogroup.com/content/datasheet/asset/file/PYU-RC_51_ROHS_P
20 | R10, R11, R18, R19, R32, R33, R34, R35, R36, R38, R42, R43, R50 , R51, R63, R64, R65, R66, R67, R69 | RES | 100k | RES SMD 100K OHM 0.5% 1/6W 0603 | 0603 | 0.50% | 1/6W | Thin FIlm | Stackpole Electronics Inc | RNCF0603DTE100K | Mouser | 708-RNCF0603DTE100K | 0.02 | 0.4 | Mouser | https://www.seielect.com/catalog/SEI-RNCF.pdf
6 | R12, R13, R20, R44, R45, R52 | RES | 20k | RES 20K OHM 1% 1/8W 0603 | 0603 | 1% | 1/8W | Thin Film | Stackpole Electronics Inc | RNCP0603FTD20K0 | Mouser | 708-RNCP0603FTD20K0 | 0.011 | 0.066 | Mouser | https://www.seielect.com/catalog/SEI-RNCP.pdf
1 | R23 | RES | 0R | RES 0 OHM JUMPER 0603 | 0603 | n/a | 1/16W | Thick Film | Kamaya | RMC1/16JPTP | Mouser | 791-RMC1/16JPTP | 0.027 | 0.027 | Mouser | https://www.mouser.com/catalog/specsheets/Kamaya_RMC_series_8_2022.pdf
2 | R25, R56 | RES | 7.5k | RES 7.5K OHM 1% 1/8W 0603 | 0603 | 1% | 1/8W | Thick Film | Stackpole Electronics Inc | RNCP0603FTD7K50 | Mouser | 708-RNCP0603FTD7K50 | 0.011 | 0.022 | Mouser | https://www.mouser.com/datasheet/3/1099/1/SEI-RNCP.pdf
2 | R28, R59 | RES | 40k | RES 40K OHM 0.1% 1/10W 0603 | 0603 | 0.10% | 1/10W | Thin Film | YAGEO | RT0603BRD0740KL | Mouser | 603-RT0603BRD0740KL | 0.049 | 0.098 | Mouser | https://www.mouser.com/datasheet/3/508/1/PYu-RT_1-to-0.01_RoHS_L_15.pdf
2 | R29, R60 | RES | 3.3k | RES 3.3K OHM 5% 1/10W 0603 | 0603 | 5% | 1/10W | Thick Film | Stackpole Electronics Inc | RMCF0603JT3K30 | Mouser | 708-RMCF0603JT3K30 | 0.007 | 0.014 | Mouser | https://www.mouser.com/datasheet/3/1099/1/SEI_RMCF_RMCP.pdf
4 | R30, R31, R61, R62 | RES | 200k | RES 200K OHM 0.5% 1/10W 0603 | 0603 | 0.50% | 1/10W | Thick Film | YAGEO | RC0603DR-07200KL | Mouser | 603-RC0603DR-07200KL | 0.015 | 0.06 | Mouser | https://www.yageogroup.com/content/datasheet/asset/file/PYU-RC_GROUP_51_ROHS_L
2 | R37, R68 | RES | 75k | RES SMD 75K OHM 1% 1/10W 0603 | 0603 | 1% | 1/10W | Thick Film | YAGEO | AF0603FR-0775KL | Mouser | 603-AF0603FR-0775KL | 0.013 | 0.026 | Mouser | https://www.yageogroup.com/content/Resource%20Library/Datasheet/PYU-AF_51_ROHS_L.pdf
8 | R77, R78, R79, R80, R81, R82, R83, R84 | POT | 10k | POT 10K OHM 1/20W PLASTIC LINEAR | TH | n/a | 1/20W | Linear | TT Electrtonics/BI | P120PK-Y25BR10K | Mouser | 858-P120PKY25BR10K | 1.017 | 8.136 | Mouser | https://mm.digikey.com/Volume0/opasdata/d220001/medias/docus/569/P120_Series_DS.pdf
2 | R85, R88 | RES | 2k | 2 kOhms ±1% 0.125W, 1/8W Chip Resistor 0603 (1608 Metric) Anti-Sulfur Thin Film | 0603 | 1% | 1/8W | Thin Film | Stackpole Electronics Inc | RNCP0603FTD2K00 | Mouser | 708-RNCP0603FTD2K00 | 0.01 | 0.02 | Mouser | https://www.seielect.com/catalog/SEI-RNCP.pdf
2 | R86, R87 | RES | 50R | RES SMD 51 OHM 5% 1/4W 0805 | 0603 | 5% | 1/4W | Thick FIlm | KOA Speer Electronics, Inc. | RK73B2ATTDD510J | Mouser | 660-RK73B2ATTDD510J | 0.026 | 0.052 | Mouser | https://www.koaspeer.com/pdfs/RK73B.pdf
1 | SW1 | SW | n/a | SWITCH TOGGLE SPST 3A 125V | TH | n/a | 3A/125V | n/a | Adam Tech | SW-T3-1A-A-A3-S1 | Mouser | 737-SW-T3-1A-A-A3-S1 | $0.98 | 0.98 | Mouser | https://www.mouser.com/datasheet/3/6015/1/sw-t3-1a-a-a3-s1-data-sheet.pdf
7 | SW2, SW3, SW4, SW5, SW6, SW7, SW8 | SW | n/a | SWITCH TACTILE SPST-NO 0.05A 24V | TH | n/a | 5ma | n/a | Omron Electronics Inc-EMC Div | B3F-1000 | Digikey | SW400-ND | $0.00 | $0.00 | Checkout | https://users.ece.utexas.edu/%7Evalvano/Datasheets/B3F-1059.pdf
1 | U1 | IC | n/a | IC REG LINEAR 3.3V 500MA TO220-3 | TO220-3 | n/a | 500mA | LDO | TI | LM2937ET-3.3/NOPB | Mouser | 926-LM2937ET-3.3NOPB | $1.45 | $0.00 | Cabinet | https://www.ti.com/lit/ds/symlink/lm2937.pdf
1 | U2 | IC | n/a | LM4041CILPR shunt diode reference | TO92-3 | n/a | n/a | n/a | TI | LM4041CILPR | TI | LM4041CILPR | $0.90 | $0.00 | Cabinet | https://www.ti.com/general/docs/suppproductinfo.tsp?distId=10
1 | U3 | CPU | n/a | IC RF TXRX+MCU BLE 48QFN | 48QFN | n/a | n/a | n/a | Espressif Systems | ESP32-D0WD-V3 | DigiKey | 1904-ESP32-D0WD-V3 | $1.68 | $0.00 | Already Owned | https://documentation.espressif.com/esp32_datasheet_en.pdf
1 | U4 | IC | n/a | FT232R FTDI Interface Arduino Platform Evaluation Expansion Board |  | n/a | n/a | n/a | SparkFun Electronics | 12935 | Digikey | 1568-12935-ND | N/A | $0.00 | McDurmot | https://mm.digikey.com/Volume0/opasdata/d220001/medias/docus/2289/FTDI_SmartBasic_Hookup_Guide.pdf
1 | U5 | CPU | n/a | TM4C123GH6PM 64-pin LQFP |  | n/a | n/a | n/a | TI | TM4C123GH6PMI | Mouser | 595-TM4C123GH6PMI | $11.55 | $0.00 | Cabinet | https://www.ti.com/lit/ds/symlink/tm4c123gh6pm.pdf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
8 | U6, U7, U8, U9, U11, U12, U13, U14 | IC | n/a | OPA2350 dual op amp | 8-DIP | n/a | n/a | n/a | TI | OPA2350PA | TI | OPA2350PA | $3.91 | $0.00 | Checkout Window | https://www.ti.com/lit/ds/symlink/opa350.pdf?HQS=dis-dk-null-digikeymode-dsf-pf-null-wwe&ts=1761536704713
2 | U10, U15 | IC | n/a | TLV5616 12-bit DAC | 8DIP | n/a | n/a | n/a | TI | TLV5616 | TI | TLV5616CP | $11.06 | $0.00 | Cabinet | https://www.ti.com/general/docs/suppproductinfo.tsp?distId=10
1 | U16 | LCD | n/a | DISPL GRAPHIC 1.8 CLR TFT SHIELD | n/a | n/a | n/a | n/a | Adafruit Industries LLC | ST7735R | Digikey | 1528-1352-ND | $34.95 | $0.00 | Inventory | https://cdn-shop.adafruit.com/datasheets/ST7735R_V0.2.pdf
1 | Y1 | CRY | 16.000MHZ | CRYSTAL 16.0000MHZ 18PF SMD | SMD | n/a | n/a | n/a | Abracon LLC | ABM3-16.000MHZ-B2-T | Digikey | 535-9103-1-ND | 0.831 | $0.00 | McDurmot | https://abracon.com/Resonators/ABM3.pdf
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

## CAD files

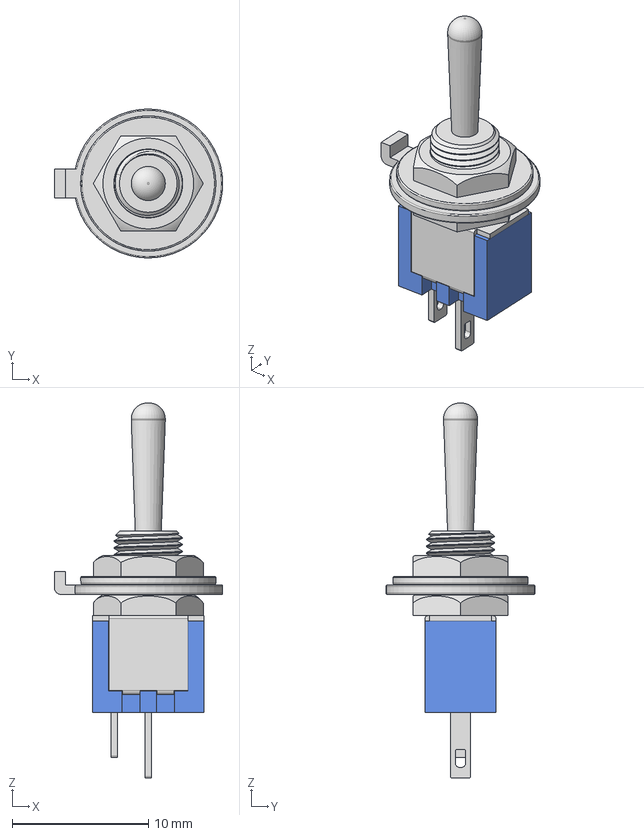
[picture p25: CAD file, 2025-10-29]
hw/ECE445L_Lab7/Part Libraries/models/SW-T3-1A-A-A3-S1.stp
12.4 x 10.9 x 27.5 mm

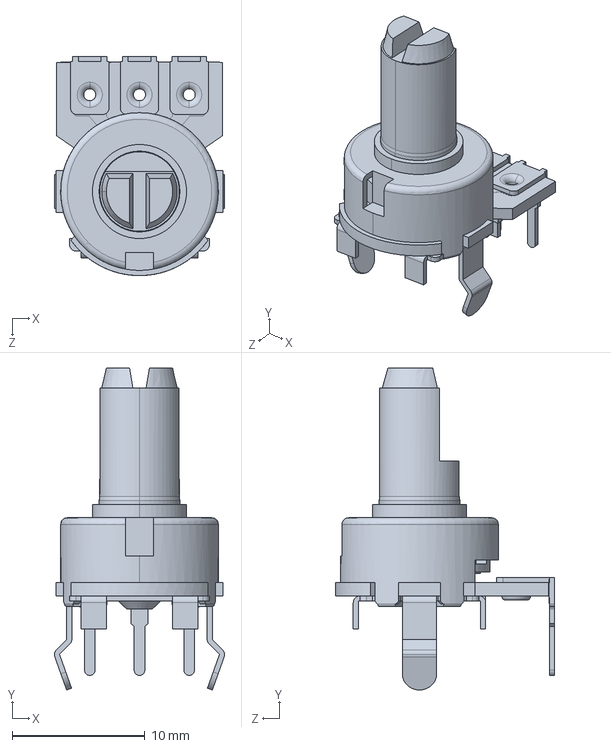
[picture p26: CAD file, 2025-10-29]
hw/ECE445L_Lab7/Part Libraries/models/P120PK-Y25BR10K.stp
12.8 x 24.3 x 16.6 mm

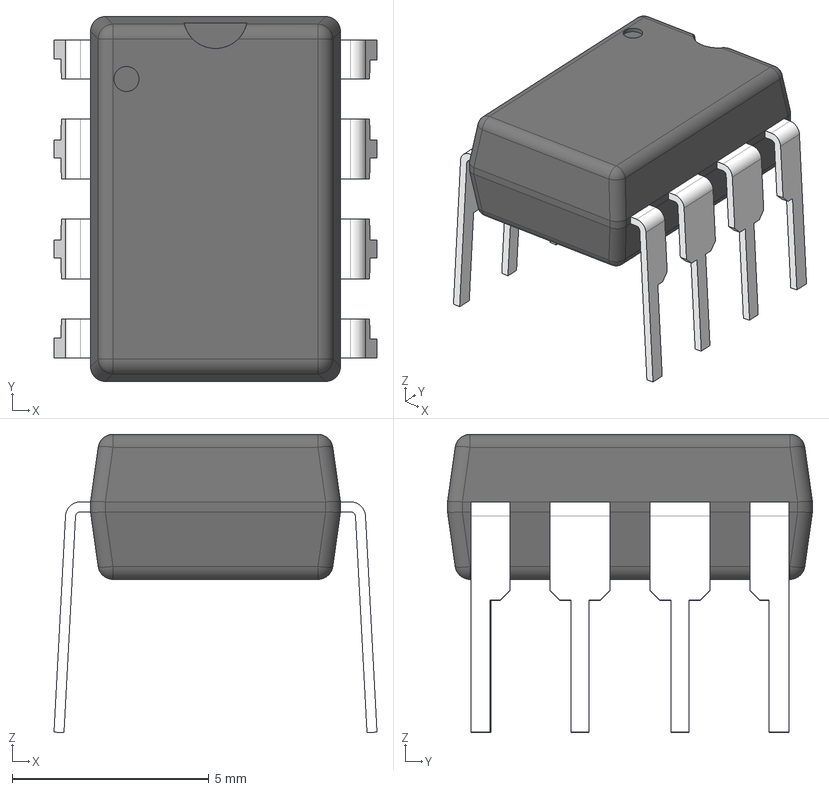
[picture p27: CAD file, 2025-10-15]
hw/ECE445L_Lab7/Part Libraries/models/ti_TLV5618AIP.stp
8.20 x 9.27 x 7.58 mm
BODY_P0008A
LEAD_P0008A x 4
LD_LHALF_P0008A x 2
LD_RHALF_P0008A x 2

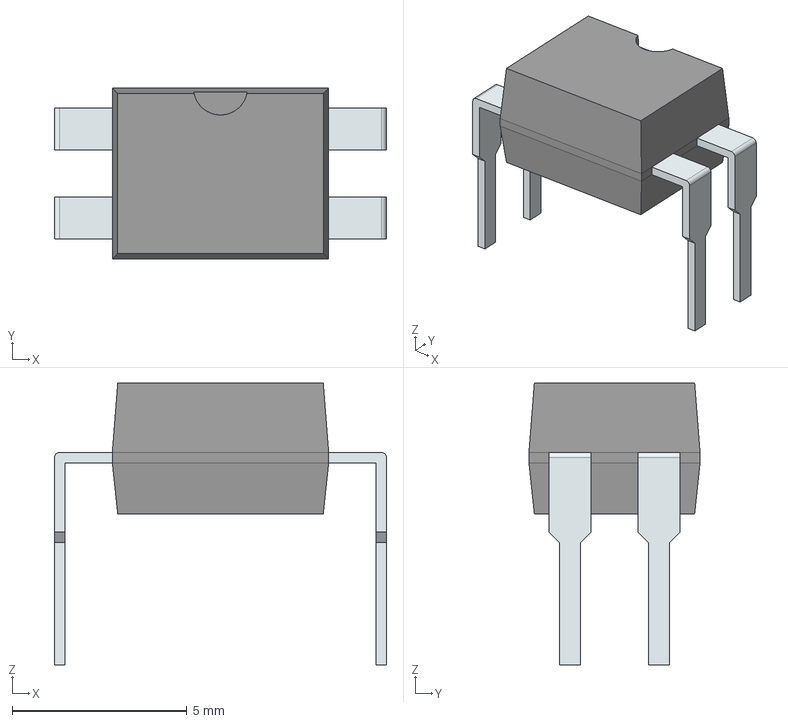
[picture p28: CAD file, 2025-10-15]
hw/ECE445L_Lab7/Part Libraries/models/vishay_IRLD024PBF.stp
9.51 x 4.90 x 8.07 mm
PinsArrayLR

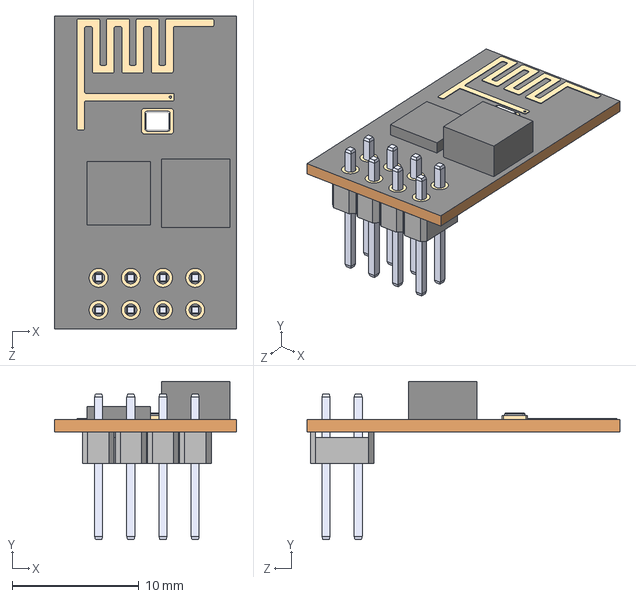
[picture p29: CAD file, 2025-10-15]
hw/ECE445L_Lab7/Part Libraries/models/ai_thinker_ESP8266-01.step
14.4 x 12.5 x 24.7 mm

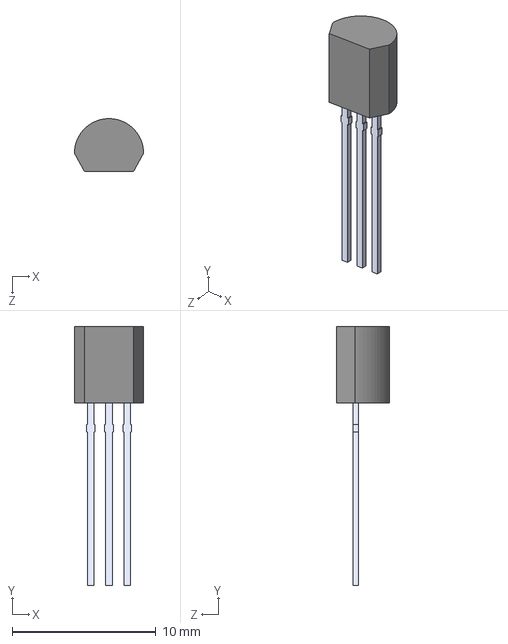
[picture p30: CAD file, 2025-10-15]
hw/ECE445L_Lab7/Part Libraries/models/ti_LM4041CILPR.step
4.82 x 18.0 x 3.68 mm

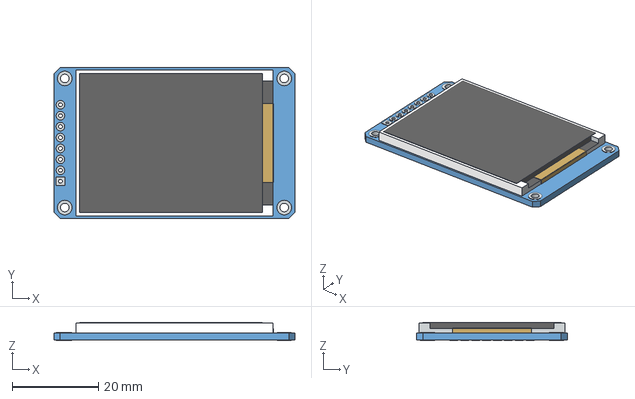
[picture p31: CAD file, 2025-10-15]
hw/ECE445L_Lab7/Part Libraries/models/adafruit_st7735r.stp
56.0 x 35.0 x 4.25 mm

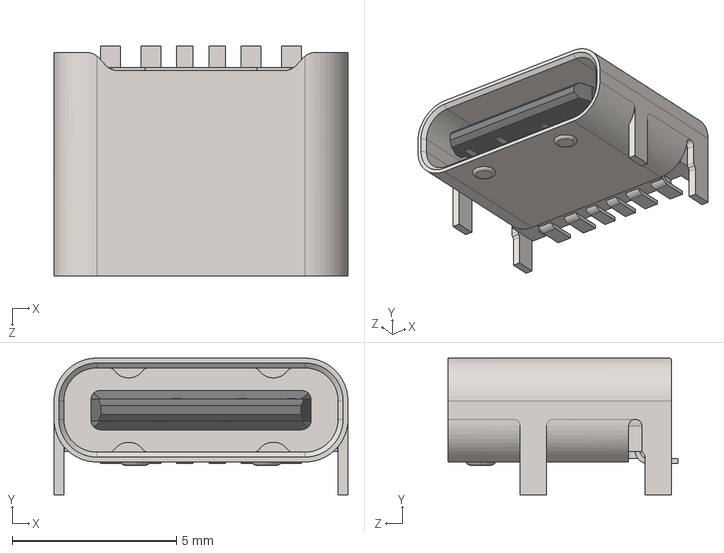
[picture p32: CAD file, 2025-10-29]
hw/ECE445L_Lab7/Part Libraries/models/2479774-1.stp
8.94 x 4.16 x 7.00 mm

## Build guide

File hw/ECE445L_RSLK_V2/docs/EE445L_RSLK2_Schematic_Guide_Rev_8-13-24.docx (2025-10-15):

PORT | SIGNAL | NOTES
Port-A[2] | Right Motor direction, IN2, MR-
Port-A[3] | Left Motor Direction, IN4, ML-
Port-A[4] | GPIO
Port-A[5] | Left Bump 0
Port-A[6] | SCL I2C clock | SSD1306 I2C OLED
Port-A[7] | SDA I2C data

PORT | SIGNAL | NOTES
Port-B[0] | U1Rx MCU sensor TxD pin 3 | Luna TOF distance sensor
Port-B[1] | U1Tx MCU sensor RxD pin 2
Port-B[2] | ERA (insert J18) T3CCP0 Timer3 | Motor Tachometer
Port-B[3] | Center Right, Bump 2
Port-B[4] | 8266_GPIO_2 Status pin for MQTT | To the TM4C
Port-B[5] | ESP8266 Reset
Port-B[6] | GPIO
Port-B[7] | ELA (insert J17) T0CCP1 Timer0B | Motor Tachometer

PORT | SIGNAL | NOTES
Port-C[4] | Right, Bump 3
Port-C[5] | GPIO
Port-C[6] | GPIO | ST7735_DC
Port-C[7] | GPIO | ST7735_RST

PORT | SIGNAL | NOTES
Port-D[0] | GPIO or SSI1/3 for ST7735 or DAC | SSI1_SCK
Port-D[1] | GPIO or SSI1/3 for ST7735 or DAC | SSI1_FS
Port-D[2] | GPIO or SSI1/3 for ST7735 or DAC | SSI1_MISO
Port-D[3] | GPIO or SSI1/3 for ST7735 or DAC | SSI1_MOSI
Port-D[6] | U2Rx (J14), ESP8266=out,TM4C123=in | 115200 Baud
Port-D[7] | U2Tx (J10), TM4C123=out,ESP8266=in

PORT | SIGNAL | NOTES
Port-E[0] | GPIO or AIN
Port-E[1] | Left Ain2 | IR analog distance sensors
Port-E[2] | GPIO or AIN
Port-E[3] | GPIO or AIN
Port-E[4] | Right Ain9 | IR analog distance sensors
Port-E[5] | Center Ain8

PORT | SIGNAL NAME | NOTES
Port-F[0] | Center Left, Bump 1 | Also LAUNCHPAD_SW2
Port-F[1] | GPIO, PWM, T0CCP1 | Also RED_LED
Port-F[2] | Motor_PWML, ML+, IN3, PWM M1PWM6 | Also BLUE_LED
Port-F[3] | Motor_PWMR, MR+, IN1, PWM M1PWM7 | Also GREEN_LED
Port-F[4] | GPIO | Also LAUNCHPAD_SW1

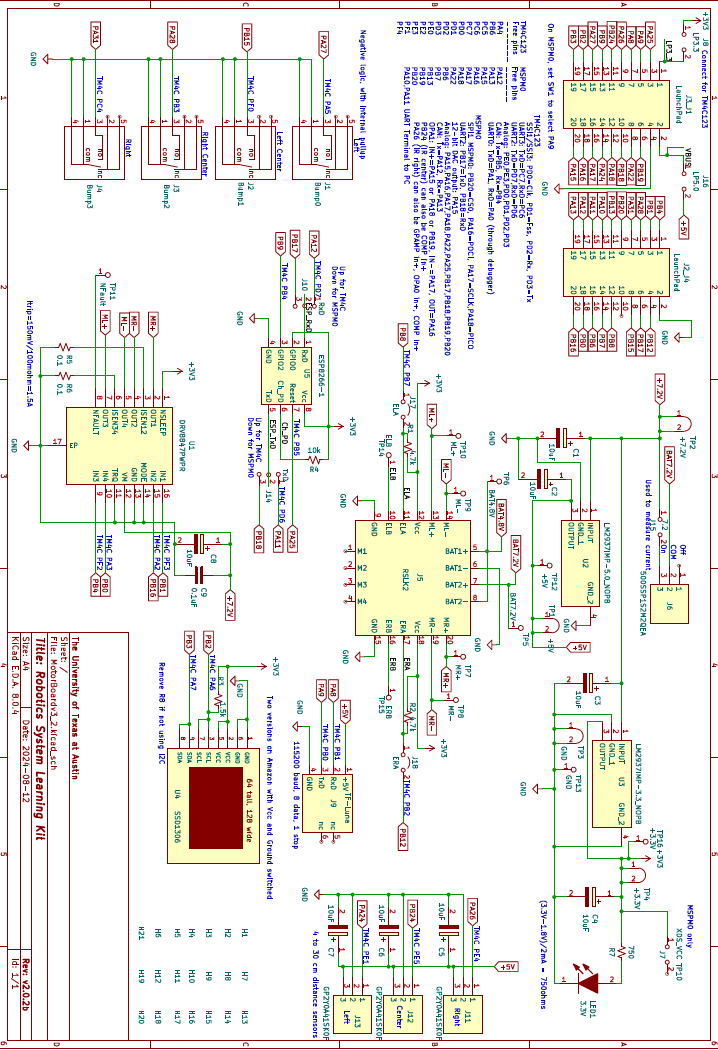
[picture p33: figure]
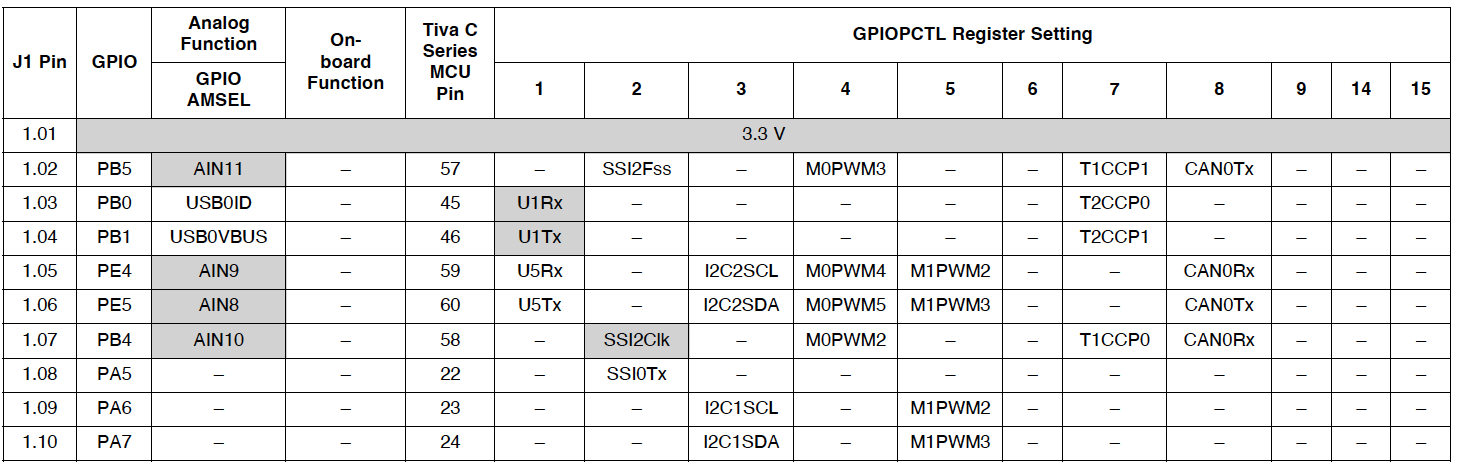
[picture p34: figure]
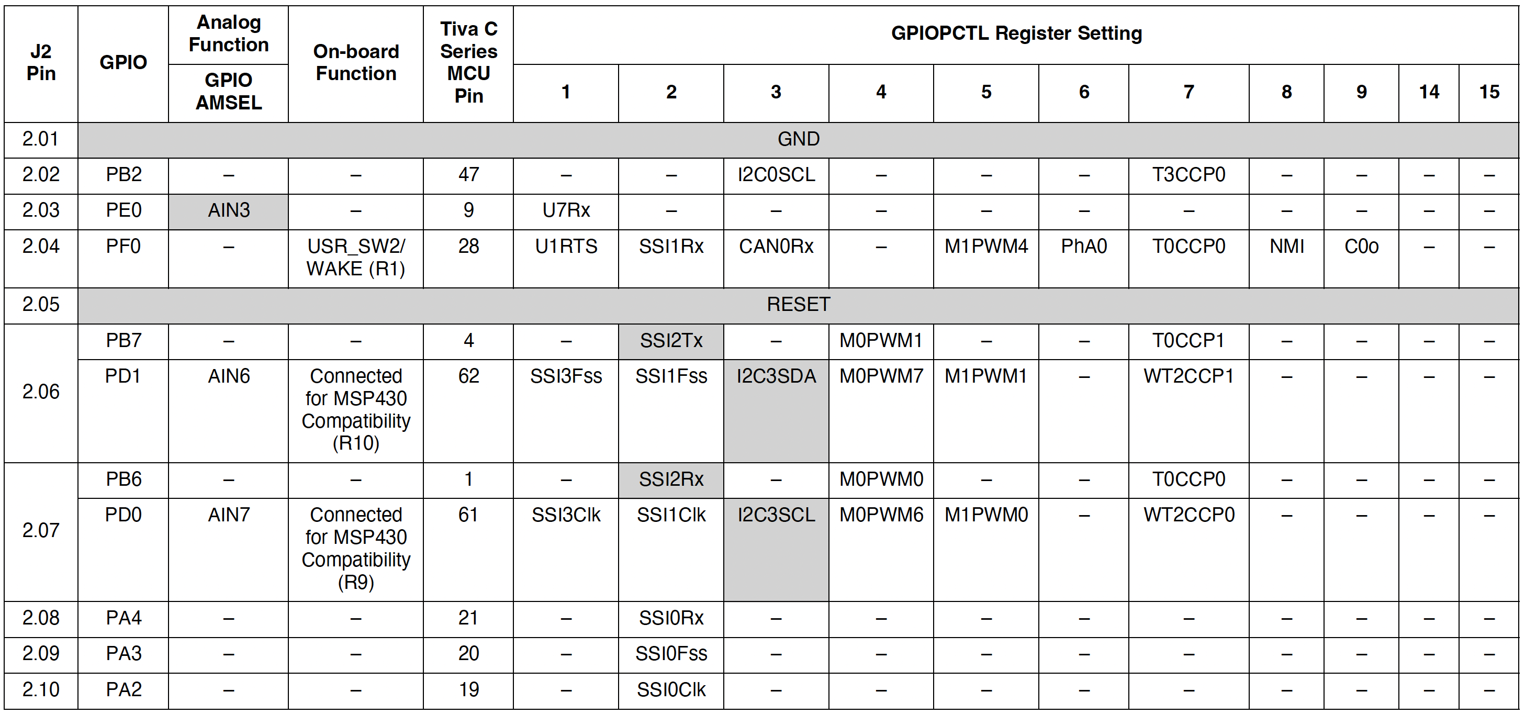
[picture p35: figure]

J3 Pin | GPIO | Analog Function | On-board Function | Tiva C Series MCU Pin | GPIOPCTL Register Setting
| | GPIO AMSEL | | | 1 | 2 | 3 | 4 | 5 | 6 | 7 | 8 | 9 | 14 | 15
3.01 | 5.0 V
3.02 | GND
3.03 | PD0 | AIN7 | – | 61 | SSI3Clk | SSI1Clk | I2C3SCL | M0PWM6 | M1PWM0 | – | WT2CCP0 | – | – | – | –
| PB6 | – | Connected for MSP430 Compatibilit y (R9) | 1 | – | SSI2Rx | – | M0PWM0 | | – | T0CCP0 | – | – | – | –
3.04 | PD1 | AIN6 | – | 92 | SSI3Fss | SSI1Fss | I2C3SDA | M0PWM7 | M1PWM1 | – | WT2CCP1 | – | – | – | –
| PB7 | – | Connected for MSP430 Compatibilit y (R10) | 4 | – | SSI2Tx | – | M0PWM1 | – | – | T0CCP1 | – | – | – | –
3.05 | PD2 | AIN5 | | 63 | SSI3Rx | SSI1Rx | – | M0FAULT0 | – | – | WT3CCP0 | USB0EPE N
3.06 | PD3 | AIN4 | – | 64 | SSI3Tx | SSI1Tx | – | – | – | – | WT3CCP1 | USB0PFLT | – | – | –
3.07 | PE1 | AIN2 | – | 8 | U7Tx | – | – | – | – | – | | – | – | – | –
3.08 | PE2 | AIN1 | – | 7 | – | – | – | – | – | – | – | – | – | – | –
3.09 | PE3 | AIN0 | – | 6 | – | – | – | – | – | – | – | – | – | – | –
3.10 | PF1 | – | – | 29 | U1CTS | SSI1Tx | – | – | M1PWM5 | – | T0CCP1 | – | C1o | TRD1 | –

J4 Pin | GPIO | Analog Function | On- board Function | Tiva C Series MCU Pin | GPIOPCTL Register Setting
| | GPIO AMSEL | | | 1 | 2 | 3 | 4 | 5 | 6 | 7 | 8 | 9 | 14 | 15
4.01 | PF2 | – | Blue LED (R11) | 30 | – | SSI1Clk | – | M0FAULT0 | M1PWM6 | – | T1CCP0 | – | – | – | TRD0
4.02 | PF3 | – | Green LED (R12) | 31 | – | SSI1Fss | CAN0Tx | – | M1PWM7 | – | T1CCP1 | – | – | – | TRCLK
4.03 | PB3 | – | – | 48 | – | – | I2C0SDA | – | – | – | T3CCP1 | – | – | – | –
4.04 | PC4 | C1– | – | 16 | U4Rx | U1Rx | – | M0PWM6 | – | IDX1 | WT0CCP0 | U1RTS | – | – | –
4.05 | PC5 | C1+ | – | 15 | U4Tx | U1Tx | – | M0PWM7 | – | PhA1 | WT0CCP1 | U1CTS | – | – | –
4.06 | PC6 | C0+ | – | 14 | U3Rx | – | – | – | – | PhB1 | WT1CCP0 | USB0EPE N | – | – | –
4.07 | PC7 | C0– | – | 13 | U3Tx | – | – | – | – | – | WT1CCP1 | USB0PFLT | – | – | –
4.08 | PD6 | – | – | 53 | U2Rx | – | – | – | – | PhA0 | WT5CCP0 | – | – | – | –
4.09 | PD7 | – | – | 10 | U2Tx | – | – | – | – | PhB0 | WT5CCP1 | NMI | – | – | –
4.10 | PF4 | – | USR_SW 1 (R13) | 5 | – | – | – | – | M1FAULT0 | IDX0 | T2CCP0 | USB0EPE N | – | – | –

McDermott & Valvano

ECE445L – Fall 2024 RSLK Schematic Guide: Rev 8-13-2024 Page

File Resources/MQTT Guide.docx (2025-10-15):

# Background

Wi-Fi is the name given to devices that communicate wirelessly employing the IEEE 802.11 standard. They typically operate in the 2.4 GHz Industrial-Scientific-Medical (ISM) unlicensed band that is shared with ZigBee (IEEE 802.15.4) and Bluetooth (IEEE 802.15.1) communications. The IEEE 802.11 standard describes how information is represented via radio frequency signals, i.e., the physical or PHY layer, and how communications are formatted and controlled, i.e., the media access control or MAC layer. Communication requirements beyond the PHY and MAC, e.g., flow control, error recovery, and routing, are handled at higher levels of the internet stack.

# Key Aspects of MQTT

MQTT (which originally stood for nothing (https://www.oasis-open.org/committees/download.php/49028/OASIS_MQTT_TC_minutes_25042013.pdf), but was backronymed to mean Message Queuing Telemetry Transport) is message passing mechanism that uses a centralized broker (server) to receive published data and send the data to any number of subscribers as shown below.

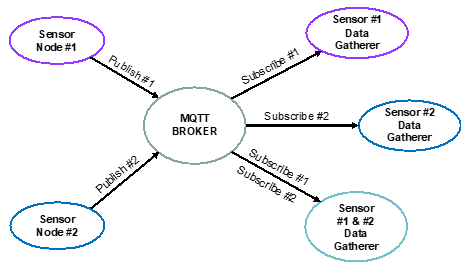
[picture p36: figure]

Figure 1: MQTT Publish-Subscribe Model

MQTT is a lightweight messaging protocol designed for low-bandwidth, high-latency, and unreliable networks. Developed in 1999 by IBM, MQTT is now a widely used open standard. MQTT is useful as it:

- Organizes data at the protocol level
- Coordinates actions between IOT devices
- Allows easy centralization of data to user-facing dashboards
- Sends connected clients only the data they need
- Can ensure a Quality Of Service (QOS) of data sent by clients
- Allows all clients to publish (broadcast) and subscribe (receive).
- Does not have the overhead of have addresses for clients like in email systems; since messages are not sent directly to clients, the client can be simplified.

Some key points about MQTT are:

- Clients become subscribers to “topic(s)” to get messages published to the broker about the “topic”
- Messages are published to a broker about a particular “topic”. In this Lab all topics MUST begin with your EID. A topic example is rg7677/b2w/hour where rg7677 is the student EID and b2w is a subtopic indicating that the message is from the LaunchPad board to the Web Application and the hour is a sub-subtopic that is current hour on the board.
- The job of an MQTT broker is to collect and sort messages based on the “topic”, so that the broker can distribute messages to subscribers of the “topic”.
- There is no direct connection between a publisher and subscriber.
- MQTT brokers do NOT normally store messages. All messages are sent via TCP which guarantees delivery (vs UDP).
- The publisher dictates the data format. The subscriber must know the format to decipher the data.

MQTT topology and the Publish/Subscribe Model:

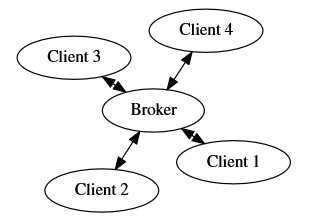
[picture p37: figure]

Figure 2 MQTT Client-Broker topology

MQTT includes ONLY broker to client/client to broker communications. MQTT networks have one broker which facilitates communication between many clients.

MQTT uses a Publish/Subscribe Model. In this model, data movement is controlled by topics. Clients decide what data they receive by deciding what topics they subscribe to. Clients can influence where data is sent by choosing what topic they attach to the data they publish. The messages sent and received always consist of a topic & data.

Although the broker is responsible for relaying data, it has no discretion to decide where data goes. The broker will relay a published message from any client to all clients that are subscribed to the topic of the message.

# Topic Naming scheme:

An MQTT topic is a hierarchical string identifier that categorizes messages being published/subscribed to within the MQTT system. Topics are represented as strings and are organized hierarchically using forward slashes (‘/’). For example, a topic could be

"sensors/temperature/EER/floor1/embeddedlab."

or

"EER/floor1/embeddedlab/temperature"

How topics are defined are up to you. As long as they follow the typical hierarchical format.

# Example of MQTT Communication

Here is an example of a typical MQTT communication between clients and how

the broker routes it.

1. An MQTT client publishes a message to a specific topic on the MQTT broker.
2. The MQTT broker receives the published message and examines the topic.
3. The broker checks its subscription database to determine which MQTT client have subscribed to that topic.
4. The broker forwards the message to all subscribed clients
5. Subscribed MQTT clients receive the message and can take action based on its content.

Now lets imagine a scenario where we have a IoT setup in the EER. We have three sensors which are their very own internet conected devices located in the EER. We have a temperature sensor in the 445L lab room, a thermostat located in the 319K room (let’s imagine the thermostat controls the A.C for the entirety of floor 1), and a faculty member has a mobile app that allows him to control the thermostat or see the readings from the sensors.

Here we have three clients:

- 445L Temperature Sensor
  - Can read temperature in the 445L room
- 319K Lab Thermostat
  - Connected via wire to the A.C, can control the A.C for the entirety of floor 1.
  - Has its own temperature sensor that allows it to read the temperature in the room it is in (the 319K lab in this case)
  - Has a temperature the thermostat can be set too. If the temperature
- in any of the rooms dip/rise above this temperature. The A.C is enabled to heat/cool
  - Has a mode for the A.C. The A.C can either be off, set to cool, or set to heat.
  - Can interface with external temperature sensors (such as the 445L temperature sensor)
  - This closely resembles popular IoT thermostats such as the Nest or Ecobee
- Mobile App
  - Allows you to control the thermostat (mode, set temperature)
  - Read the temperature readings across all temperature sensors

All of these clients are connected to one central server (The MQTT Broker) to facilitate communication. This server could be for examples McDermott MQTT server in his office, or a public/cloud based MQTT Server.

Figure 3 Client-Broker setup of the Example

Now lets try to analyze what information each client provides, and what information each client would want from another client.

- 445L Temperature Sensor
  - Reads the 445l lab room temperature, publishes it.
- 319K Lab Thermostat
  - Reads the temperature in the 319K room, can act on this reading (enable the A.C for floor 1). Can also publish it (for the mobile app)
  - Is interested in the temperature in the 445L room, can act on this reading (enable the A.C for floor 1)
  - Has a temperature that can be set to enable cooling/heat (acting on this data) It can publish this temperature (for the mobile app), and it can also have this changed externally (from the mobile app)
  - Has a A.C mode (off/cool/heat). It acts on this mode (enable the A.C for cool/hot if the outside temperature changes). It can publish this data (so the mobile app knows the current A.C mode), it can also have this changed externally (from the mobile app)
- Mobile App
  - Can set the A.C mode from the mobile app. Changes to this can be made from app or thermostat
  - Can set the thermostat temperature. Changes can be made from app or thermostat.
  - Can read all temperature sensor readings.

From this lets define the following topics, and these publishers and subscribers

- /EER/floor1/445Lab/temperature
  - Publishers:
    - 445L Temperature Sensor
  - Subscribers:
    - 319K Thermostat
    - Mobile App
- /EER/floor1/319KLab/temperature
  - Publishers:
    - 319K Thermostat
  - Subscribers:
    - Mobile App
- /EER/floor1/thermostat/set_temp
  - Publishers:
    - 319K Thermostat
    - Mobile App
  - Subscribers:
    - 319K Thermostat
    - Mobile App
- /EER/floor1/thermostat/mode
  - Publishers:
    - 319K Thermostat
    - Mobile App
  - Subscribers:
    - 319K Thermostat
    - Mobile App

# The scenario where 445L Lab Temp Changes

If the 445L lab room temperature changes. The sensor publishes to its topic.

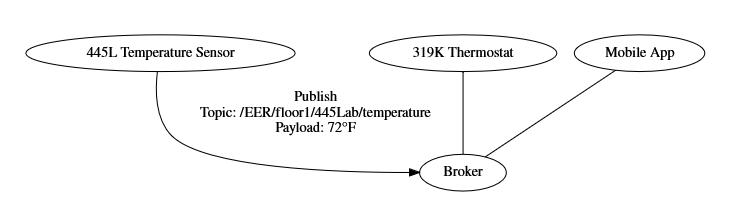
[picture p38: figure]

Figure 4: 445L Temperature Sensor publishes change

The thermostat and mobile app are subscribers, thus the broker forwards the message.

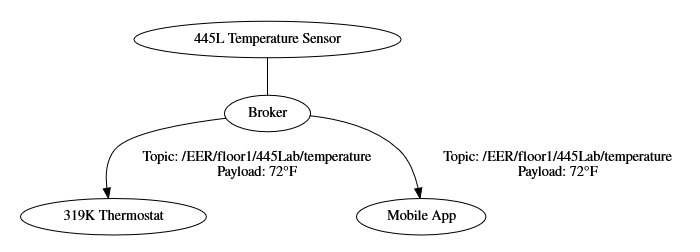
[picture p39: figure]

Figure 5: Subscribers are notified

# How to approach Lab 4

From the perspective of the lab we have a single broker and two clients:

- Your Alarm Clock
- The web dashboard

From the perspective of the free broker service however, it has your alarm clock and web dashboard as a client. As well as the alarm clock and web dashboard of everyone else in the class (and anyone else using the service). So when you define your topics make sure the topic string is unique. For example if everyone used the same topic, lets say “alarm/current_time”, you would be able to change the time of everyone’s alarm clock. So to make unique topic names, your topic should start with your eid, ex. “eid123/alarm/current_time”.

Here is how we reccomend approaching this lab to avoid stress and headaches. First things first, don’t try integrating lab3 right away, instead get topics working. Using the starter code, do the following:

1. ESP Bring up, the ESP8266 should be able to connect to a network and to the broker. This should be done in prep. Come to your TA’s if you were unable to do this.
2. Define your topics, and the subscriber/publisher relationships.
3. Have both of you open the web dashboard. Have one person subscribe to a topic, and have the other publish to the topic. The subscriber should be able to receive a message when this happens.
4. Modify your TM4C starter code so you can communicate with the ESP. The TM4C communicates with the ESP over UART. You can observe what is being sent to the ESP via USB-Serial between your PC and the TM4C using a serial terminal.
5. Test, can you publish to a topic from the TM4C, do you see this change reflected on the web dashboard?
6. Test, can you publish to a topic from the web dashboard, do you see this change reflected on the TM4C?
7. Now that you can publish/subscribe to topics. Now integrate your Lab 3 Code.

If you need any help, please email us or come to our office hours.

# Useful MQTT tutorials and projects:

- http://www.steves-internet-guide.com/mqtt-works/
- http://www.steves-internet-guide.com/download/mqtt-study-guide/
- http://www.steves-internet-guide.com/mqtt-protocol-messages-overview/
- http://www.steves-internet-guide.com/into-mqtt-python-client/
- http://www.steves-internet-guide.com/mqtt-websockets/
- http://www.steves-internet-guide.com/using-javascript-mqtt-client-websockets/
- http://www.steves-internet-guide.com/mosquitto-broker/
- http://www.steves-internet-guide.com/install-mosquitto-broker/
- http://www.steves-internet-guide.com/mqtt-broker-testing/
- http://www.steves-internet-guide.com/monitoring-mqtt-brokers/

2 MQTT Primer

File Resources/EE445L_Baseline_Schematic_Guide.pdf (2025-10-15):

# EE445L – Fall 2021

Lab Baseline Schematic Guide: Rev 10-1-2021 | Page 1

### McDermott & Valvano

This semester we have decided to standardize the I/O Pin assignment to make remote debugging a little

### bit easier for the TAs. The standardized Signal and Port assignments are listed below:

PORT | SIGNAL NAME | TM4C PORT ASSIGNMENT | NOTES
Port-A[2] | ST7735_SCK | SSI0_SCK | SSI interface to the ST7735 LCD
Port-A[3] | ST7735_TFT_CS | SSI0_SS
Port-A[4] | ST7735_MISO | SSI0_MISO
Port-A[5] | ST7735_MOSI | SSI0_MOSI
Port-A[6] | ST7735_DC | GPIO
Port-A[7] | ST7735_RST | GPIO
PORT | SIGNAL NAME | TM4C PORT ASSIGNMENT | NOTES
Port-B[0] | ST7735_CARD_CS | GPIO | ST7735 SDCARD Chip Select
Port-B[1] | PB1 | GPIO | Used for simple speaker
Port-B[2] | PB2 | GPIO/I2C0_SCK | Primarily GPIO, can be used for I2C
Port-B[3] | PB3 | GPIO/I2C0_SDA
Port-B[4] | TACH2 | T1_CCP0 | Tach Input for Lab-10
Port-B[5] | PB5 | GPIO/AIN_11 | GPIO or Analog input
Port-B[6] | PWM | M0_PWM0 | PWM control for Lab-10
Port-B[7] | PB7 | GPIO/PWM1
PORT | SIGNAL NAME | TM4C PORT ASSIGNMENT | NOTES
Port-C[4] | UP | GPIO | Used for switches in Lab 3
Port-C[5] | RIGHT | GPIO
Port-C[6] | LEFT | GPIO
Port-C[7] | DOWN | GPIO
PORT | SIGNAL NAME | TM4C PORT ASSIGNMENT | NOTES
Port-D[0] | SSI1_SCK | SSI1_SCK | SCK to TLV5616 DAC
Port-D[1] | SSI1_FS | SSI1_FS | SS/FS to TLV5616 DAC
Port-D[2] | PD2 | AIN_5 | Used to monitor DAC_OUT
Port-D[3] | SSI1_MOSI | SSI1_MOSI | MOSI to TLV5616 DAC
Port-D[6] | PD6 | GPIO | Can be used as alternate UART Port
Port-D[7] | PD7 | GPIO
PORT | SIGNAL NAME | TM4C PORT ASSIGNMENT | NOTES
Port-E[0] | 8266_GPIO_2 | GPIO | Status signal 8266 WiFi
Port-E[1] | RSTB_8266 | GPIO | Reset signal to 8266 WiFi
Port-E[2] | AIN_1 | AIN1 | Used for Audio Input Lab-9
Port-E[3] | GPIO | GPIO
Port-E[4] | 8266_TX 8266_RX | U5_RX U5_TX | UART TXD/RXD to 8266 WiFi Port-E[5]
PORT | SIGNAL NAME | TM4C PORT ASSIGNMENT | NOTES
Port-F[0] | LAUNCHPAD_SW2 | RESERVED for Launchpad | Mode Switch
Port-F[1] | RED_LED | | Red LED on LaunchPad
Port-F[2] | BLUE_LED | | Blue LED on LaunchPad
Port-F[3] | GREEN_LED | | Green LED on LaunchPad
Port-F[4] | LAUNCHPAD_SW1 | | Mode Switch
The baseline schematic printout is shown on the next two pages. Use this as the starting point for Eagle

### Schematics

Lab Baseline Schematic Guide: Rev 10-1-2021 | Page 2

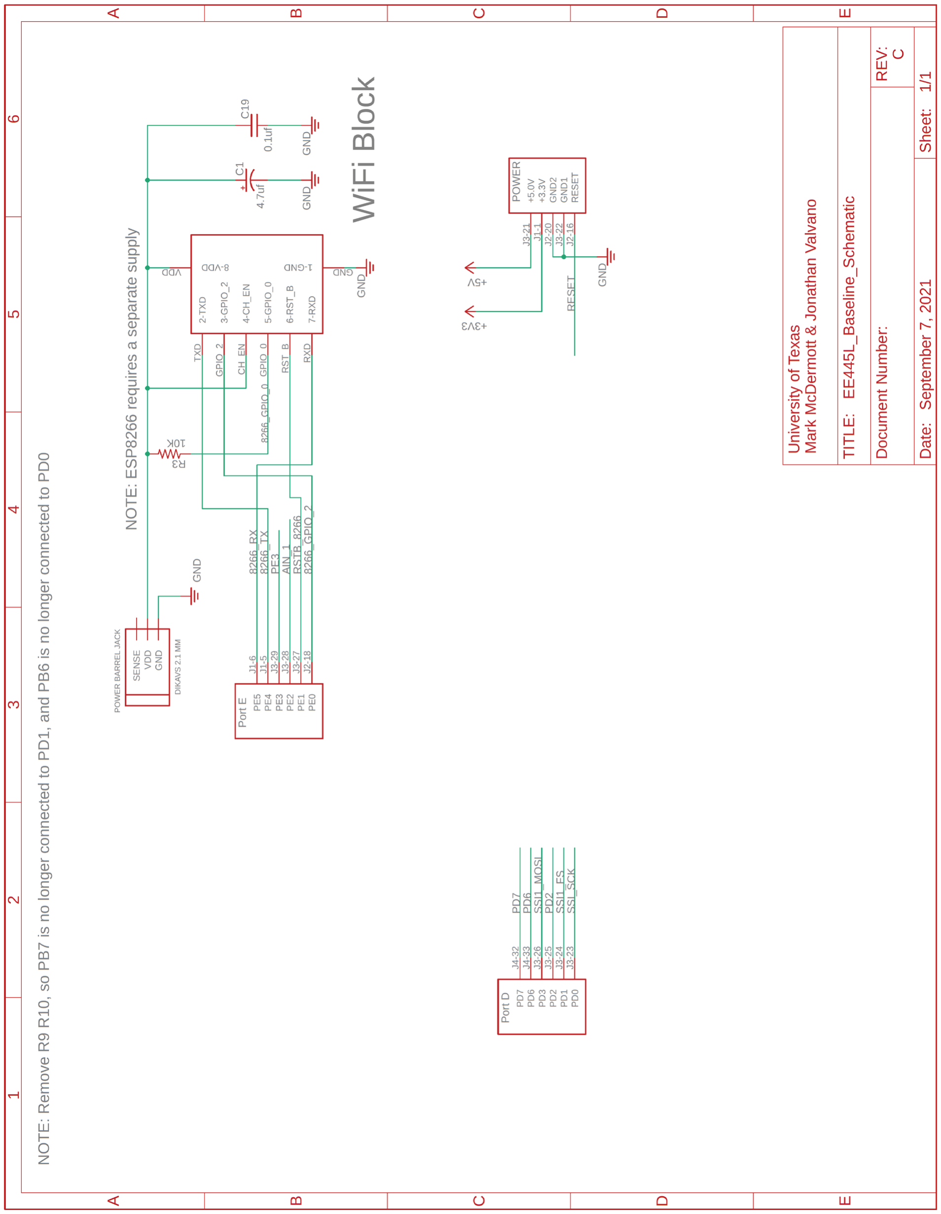
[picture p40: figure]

Lab Baseline Schematic Guide: Rev 10-1-2021 | Page 3

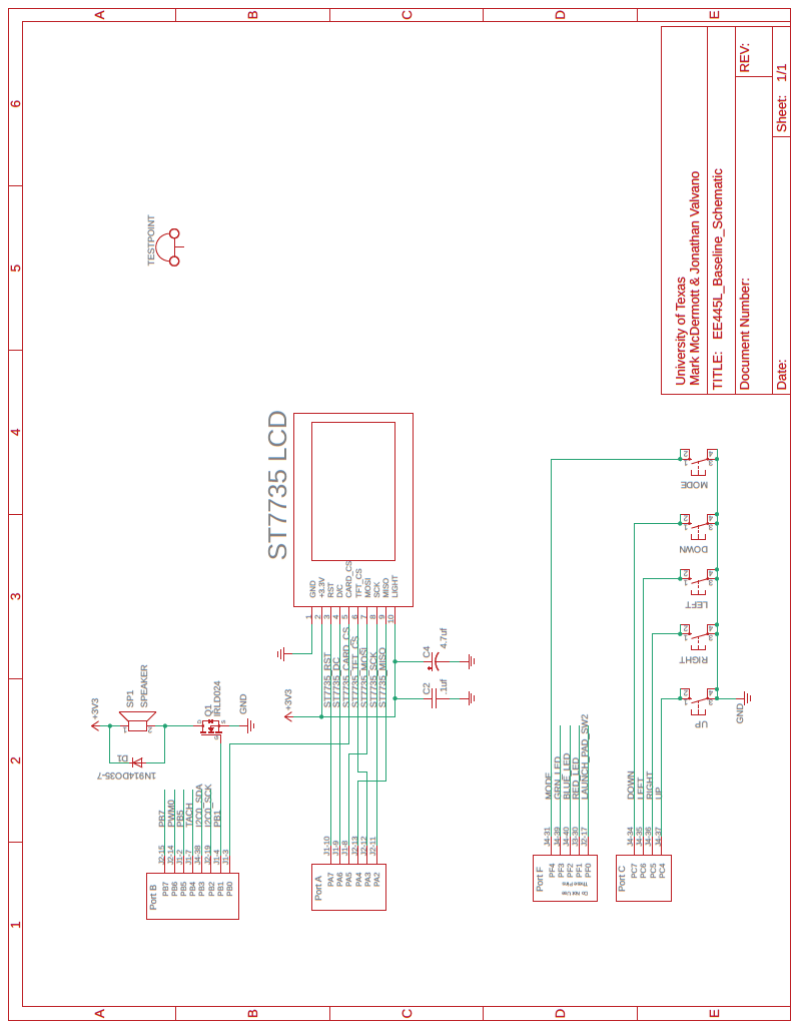
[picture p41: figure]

Lab Baseline Schematic Guide: Rev 10-1-2021 | Page 4

### PORT Initialization

Do not use this code without confirming that it does what you need it to do.

// ---------------------------------------------------------------------------//
// File name: Unified_Port_Init.c
//
// Author: | Mark McDermott
// Orig gen date: July 12, 2020
// Last update: August 17, 2020
//
// Description: This is the unified Port initialization routine 445L Labs
//
// Usage: | Call Lab_Brd_Port_Init () if you want to initialize all ports (preferred)
// | Call the individual port inits as needed.
//
// ---------------------------------------------------------------------------

#include "inc/tm4c123gh6pm.h"

#include "inc/Lab_Brd_Port_Init.h"

// --------------------------- | Port_Init | ------------------------------

void Lab_Brd_Port_Init(void){
Port_A_Init();
Port_B_Init();
Port_C_Init();
Port_D_Init();
Port_E_Init();
Port_F_Init();
}

// ----------------------------------------------------------------------------
// ---------------- | PORT A Initialization | --------------------------------
// ----------------------------------------------------------------------------//
// Port A drives the ST7735 LCD
//
// Backlight (pin 10) connected to +3.3 V
// MISO | (pin 9) connected to PA4
// SCK | (pin 8) connected to PA2 (SSI0Clk)
// MOSI | (pin 7) connected to PA5 (SSI0Tx)
// TFT_CS | (pin 6) connected to PA3 (SSI0Fss)
// CARD_CS | (pin 5) connected to PB0 (GPIO)
// Data/CMD (pin 4) connected to PA6 (GPIO)
// RESET | (pin 3) connected to PA7 (GPIO)
// VCC | (pin 2) connected to +3.3 V
// Gnd | (pin 1) connected to ground
//

void Port_A_Init(void){

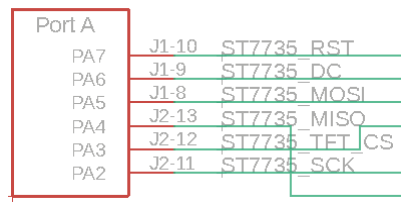
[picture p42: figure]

SYSCTL_RCGCSSI_R | |= 0x01; | // Activate SSI0
SYSCTL_RCGCGPIO_R | |= 0x01; | // Activate port A
while((SYSCTL_PRGPIO_R & 0x01)==0){}; | // allow time for clock to start
GPIO_PORTA_DIR_R | |= 0xC8; | // make PA3,6,7 out
GPIO_PORTA_AFSEL_R | &= ~0xC8; | // disable alt funct on PA3,6,7

Lab Baseline Schematic Guide: Rev 10-1-2021 | Page 5
GPIO_PORTA_DEN_R | |= 0xC8; | // enable digital I/O on PA3,6,7

// configure PA3,6,7 as GPIO
GPIO_PORTA_PCTL_R | = (GPIO_PORTA_PCTL_R
| & 0x00FF0FFF)
| + 0x00000000;
GPIO_PORTA_AMSEL_R | &= ~0xC8; | // disable analog functionality on PA3,6,7

// initialize SSI0
GPIO_PORTA_AFSEL_R | |= 0x2C; | // enable alt funct on PA2,3,5
GPIO_PORTA_DEN_R | |= 0x2C; | // enable digital I/O on PA2,3,5

// configure PA2,3,5 as SSI
GPIO_PORTA_PCTL_R | = (GPIO_PORTA_PCTL_R
| & 0xFF0F00FF)
| + 0x00202200;
GPIO_PORTA_AMSEL_R | &= ~0x2C; | // disable analog functionality on PA2,3,5
SSI0_CR1_R | &= ~SSI_CR1_SSE; | // disable SSI
SSI0_CR1_R | &= ~SSI_CR1_MS; | // master mode

// configure for system clock/PLL baud clock source
SSI0_CC_R | = (SSI0_CC_R&~SSI_CC_CS_M)
| + SSI_CC_CS_SYSPLL;

// clock divider for 8 MHz SSIClk (80 MHz PLL/24) // SysClk/(CPSDVSR*(1+SCR))
// 80/(10*(1+0)) = 8 MHz (slower than 4 MHz)
SSI0_CPSR_R | = (SSI0_CPSR_R
&~SSI_CPSR_CPSDVSR_M)
| + 10; | // must be even number

// SCR = 0 (8 Mbps data rate)
// SPH = 0
// SPO = 0
SSI0_CR0_R | &= ~(SSI_CR0_SCR_M
| | SSI_CR0_SPH
| | SSI_CR0_SPO);

// FRF = Freescale format
SSI0_CR0_R | = (SSI0_CR0_R
| &~SSI_CR0_FRF_M)
| + SSI_CR0_FRF_MOTO;

// DSS = 8-bit data
SSI0_CR0_R | = (SSI0_CR0_R
| &~SSI_CR0_DSS_M)
| + SSI_CR0_DSS_8;
// enable SSI
SSI0_CR1_R | |= SSI_CR1_SSE;

}

Lab Baseline Schematic Guide: Rev 10-1-2021 | Page 6

// ----------------------------------------------------------------------------
// ---------------- | PORT B Initialization | --------------------------------
// ----------------------------------------------------------------------------
//
// PB7 = GPIO/M0PWM1
// PB6 = PWM Output to Motor (M0PWM0)
// PB5 = GPIO/AIN11
// PB4 = Timer Capture input (TACH) // PB3 = GPIO/I2C_SDA
// PB2 = GPIO/I2C0_SCL
// PB1 = GPIO
// PB0 = ST7735 Card CS

void Port_B_Init(void){

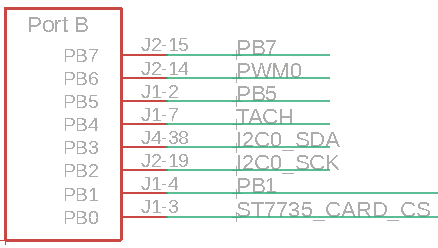
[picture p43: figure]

SYSCTL_RCGCPWM_R | |= 0x01; | // activate PWM0
SYSCTL_RCGCGPIO_R | |= 0x02; | // activate port B
while((SYSCTL_PRGPIO_R & 0x02) == 0){}; | // Wait

// --------------- Initialize PB7 as M0PWM1 -----------------------

GPIO_PORTB_AFSEL_R | |= 0x80; | // enable alt funct on PB7
GPIO_PORTB_PCTL_R | &= ~0xF0000000; | // configure PB7 as M0PWM1
GPIO_PORTB_PCTL_R | |= 0x40000000;
GPIO_PORTB_AMSEL_R | &= ~0x80; | // disable analog functionality on PB7
GPIO_PORTB_DEN_R | |= 0x80; | // enable digital I/O on PB7

// --------------- Initialize PB6 as M0PWM0 -----------------------
GPIO_PORTB_AFSEL_R | |= 0x40; | // enable alt funct on PB6
GPIO_PORTB_PCTL_R | &= ~0x0F000000; | // configure PB6 as PWM0
GPIO_PORTB_PCTL_R | |= 0x04000000;
GPIO_PORTB_AMSEL_R | &= ~0x40; | // disable analog functionality on PB6
GPIO_PORTB_DEN_R | |= 0x40; | // enable digital I/O on PB6

// --------------- Initialize PB5 as AIN11 -----------------------
GPIO_PORTB_DIR_R | &= ~0x20; | // make PB5 input
GPIO_PORTB_AFSEL_R | |= 0x20; | // enable alternate function on PB5
GPIO_PORTB_DEN_R | &= ~0x20; | // disable digital I/O on PB5
GPIO_PORTB_AMSEL_R | |= 0x20; | // enable analog functionality on PB5

// ----------------- Initialize PB4 as Timer Capture input (T1CCP0) ---------
GPIO_PORTB_DIR_R | &= ~0x10; | // make PB4 input
GPIO_PORTB_AFSEL_R | |= 0x10; | // enable alt funct on PB4
GPIO_PORTB_DEN_R | |= 0x10; | // enable digital I/O on PB4
| | // configure PB4 (T1CCP0)
GPIO_PORTB_PCTL_R | = (GPIO_PORTB_PCTL_R
| & 0xFFF0FFFF)
| + 0x00070000;
GPIO_PORTB_AMSEL_R | &= ~0x10; | // disable analog functionality on PB4

// ----------------- Initialize PB3-0 as GPIO ---------
GPIO_PORTB_PCTL_R | &= ~0x0000FFFF; | // GPIO
GPIO_PORTB_DIR_R | |= 0x0F; | // make PB3-0 out
GPIO_PORTB_AFSEL_R | &= ~0x0F; | // regular port function
GPIO_PORTB_DEN_R | |= 0x0F; | // enable digital I/O on PB3-0
GPIO_PORTB_AMSEL_R | &= ~0x0F; | // disable analog functionality on PB3-0
}

Lab Baseline Schematic Guide: Rev 10-1-2021 | Page 7

// ----------------------------------------------------------------------------
// ---------------- | PORT C Initialization | --------------------------------
// ----------------------------------------------------------------------------
//
// PC4 = UP switch
// PC5 = RIGHT switch
// PC6 = LEFT switch
// PC7 = DOWN switch
//

void Port_C_Init(void){

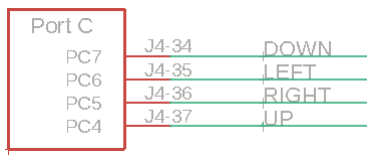
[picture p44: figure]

SYSCTL_RCGCGPIO_R | |= 0x04; | // Activate clock for Port C
while((SYSCTL_PRGPIO_R & 0x04) != 0x04){}; // Allow time for clock to start
GPIO_PORTC_PCTL_R | &= ~0xFFFF0000; | // regular GPIO
GPIO_PORTC_AMSEL_R | &= ~0xF0; | // disable analog function
GPIO_PORTC_DIR_R | &= ~0xF0; | // inputs on PC7-PC4
GPIO_PORTC_AFSEL_R | &= ~0xF0; | // regular port function
GPIO_PORTC_DEN_R | |= 0xF0; | // enable digital port
}

Lab Baseline Schematic Guide: Rev 10-1-2021 | Page 8

// ----------------------------------------------------------------------------
// ---------------- | PORT D Initialization | --------------------------------
// ----------------------------------------------------------------------------
//
// PD7 = GPIO/U2TX
// PD6 = GPIO/U2RX
// PD5 = Reserved for LaunchPad // PD4 = Reserved for Launchpad // PD3 = SSI1_MOSI (to TLV5616) // PD2 = AIN5
// PD1 = SSI1_FS/CS (to TLV5616) // PD0 = SSI1_SCK (to TLV5616)

void Port_D_Init(void){

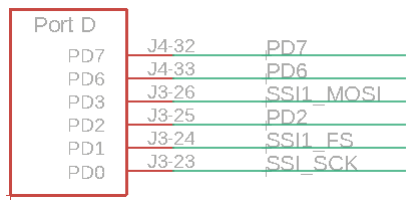
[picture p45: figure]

SYSCTL_RCGCGPIO_R | |= 0x08; | // activate port D
while((SYSCTL_PRGPIO_R & 0x08)==0){}; | // allow time for clock to stabilize

// --------------- Initialize PB7 as U2TX, PB6 as U2RX -----------------------

GPIO_PORTD_LOCK_R | = 0x4C4F434B; | // unlock REQUIRED for PD7
GPIO_PORTD_CR_R | |= 0xC0; | // commit PD6, PD7
GPIO_PORTD_AMSEL_R | &= ~0xC0; | // disable analog functionality on PD6, PD7
GPIO_PORTD_AFSEL_R | |= 0xC0; | // enable alternate function on PD6, PD7
GPIO_PORTD_DEN_R | |= 0xC0; | // enable digital on PD6, PD7 (PD6 is U2RX, PD7 is
U2TX)
GPIO_PORTD_PCTL_R =(GPIO_PORTD_PCTL_R
& 0x00FFFFFF)
| 0x11000000; // configure PD6, PD7 as UART

// --------------- Initialize PD2 as AIN5 ----------------------------------

GPIO_PORTD_DIR_R | &= ~0x04; | // make PD2 input
GPIO_PORTD_AFSEL_R | |= 0x04; | // enable alternate function on PD2
GPIO_PORTD_DEN_R | &= ~0x04; | // disable digital I/O on PD2
GPIO_PORTD_AMSEL_R | |= 0x04; | // enable analog functionality on PD2
// --------------- Initialize PD3,1,0 as SSI1 MOSI, FS & SCK ----------------
GPIO_PORTD_AMSEL_R | &= ~0x0B; | // disable analog functionality on PD
GPIO_PORTD_AFSEL_R | |= 0x0B; | // enable alt funct on PD3,1,0
GPIO_PORTD_DEN_R | |= 0x0B; | // enable digital I/O on PD3,1,0
GPIO_PORTD_PCTL_R | = (GPIO_PORTD_PCTL_R
& 0xFFFF0F00)
+ 0x00002022;
}

Lab Baseline Schematic Guide: Rev 10-1-2021 | Page 9

// ----------------------------------------------------------------------------
// ---------------- | PORT E Initialization | --------------------------------
// ----------------------------------------------------------------------------
//
// PE5 = 8266_RX (U5TX)
// PE4 = 8266_TX (U5RX)
// PE3 = GPIO
// PE2 = AIN_1 (Audio Input) // PE1 = 8266_8266
// PE0 = 8266_ GPIO_2

void Port_E_Init(void){

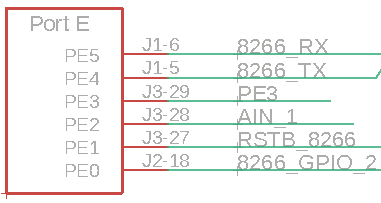
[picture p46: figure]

SYSCTL_RCGCGPIO_R | |= 0x10; | // activate port E
while((SYSCTL_PRGPIO_R & 0x10)==0){};

// --------------- Initialize PE5 as U5TX, PE4 as U5RX -----------------------

GPIO_PORTE_AFSEL_R | |= 0x30; | // enable alt funct on PE5-4
GPIO_PORTE_DEN_R | |= 0x30; | // enable digital I/O on PE5-4
| | // configure PE5-4 as UART
GPIO_PORTE_PCTL_R | = (GPIO_PORTE_PCTL_R
| & 0xFF00FFFF)
| + 0x00110000;
GPIO_PORTE_AMSEL_R | &= ~0x30; | // disable analog functionality on PE
// --------------- Initialize PE3,1,0 as GPIO ---------------------------------
GPIO_PORTE_DIR_R | |= 0x0A; | // output digital I/O on PE3,1
GPIO_PORTE_DIR_R | &= ~0x01; | // input digital I/O on PE0
GPIO_PORTE_AMSEL_R | &= ~0x0B; | // disable analog functionality on PE3,1,0
GPIO_PORTE_AFSEL_R | &= ~0x0B; | // disable alt funct on PE3,1,0
GPIO_PORTE_DEN_R | |= 0x0B; | // enable digital I/O on PE3,1,0
GPIO_PORTE_PCTL_R | = (GPIO_PORTE_PCTL_R
| & 0xFFFF0F00);
// --------------- Initialize PE2 as AIN1 ---------------------------------
GPIO_PORTE_DIR_R | &= ~0x04; | // make PE2 input
GPIO_PORTE_AFSEL_R | |= 0x04; | // enable alternate function on PE2
GPIO_PORTE_DEN_R | &= ~0x04; | // disable digital I/O on PE2
GPIO_PORTE_AMSEL_R | |= 0x04; | // enable analog functionality on PE2
}

Lab Baseline Schematic Guide: Rev 10-1-2021 | Page 10

// ----------------------------------------------------------------------------
// ---------------- | PORT F Initialization | --------------------------------
// ----------------------------------------------------------------------------//
// LaunchPad Pin Assignments
// PF4 = SW1
// PF3 = GREEN_LED
// PF2 = BLUE_LED
// PF1 = RED_LED
// PF0 = SW2

void Port_F_Init(void){

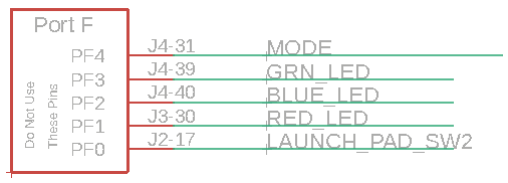
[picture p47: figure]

SYSCTL_RCGCGPIO_R | |= 0x00000020; | // activate clock for Port F
while((SYSCTL_PRGPIO_R & 0x20)==0){}; | // allow time for clock to stabilize
GPIO_PORTF_LOCK_R | = 0x4C4F434B; | // unlock GPIO Port F
GPIO_PORTF_CR_R | = 0x1F; | // allow changes to PF4-0
GPIO_PORTF_AMSEL_R | = 0x00; | // disable analog on PF
GPIO_PORTF_PCTL_R | = 0x00000000; | // PCTL GPIO on PF4-0
GPIO_PORTF_DIR_R | = 0x0E; | // PF4,PF0 in, PF3-1 out
GPIO_PORTF_AFSEL_R | = 0x00; | // disable alt function on PF7-0
GPIO_PORTF_PUR_R | = 0x11; | // enable pull-up on PF0 and PF4
GPIO_PORTF_DEN_R | = 0x1F; | // enable digital I/O on PF4-0
}

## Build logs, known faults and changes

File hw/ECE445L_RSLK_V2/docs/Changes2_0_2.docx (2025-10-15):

Ability to measure 7.2 current easily

Fix positions of spoiler drill holes (move OLED up)

Socket for ESP8266-1
/* Hardware connections

Vcc should be connected to RSLK 3.3V (not debugger)

/------------------------------\

| chip 1 8 |

| Ant 2 7 |

| enna processor 3 6 |

| 4 5 |

\------------------------------/

Set #define for UART2 (PD) and Reset PB5

ESP8266 TM4C123

1 URxD PD7 UART out of TM4C123, 115200 baud

2 GPIO0 +3.3V for normal operation (ground to flash)

3 GPIO2 PB4

4 GND Gnd GND (70mA)

5 UTxD PD6 UART out of ESP8266, 115200 baud

6 Ch_PD chip select, 10k resistor to 3.3V

7 Reset PB5 TM4C123 can issue output low to cause hardware reset

8 Vcc regulated 3.3V supply with at least 70mA

*/

Mostly through-hole parts

4.7k pullup on tachometer

No Diode for 3.3V to LaunchPad, leave jumper

Add +5V to VBUS jumper (allow LaunchPad to power IR distance)

Move test points for motor pins to make it easier to test

Add a power pin for 3.3V (like 5 7.2 gnd)

Test IR distance sensors to check angles, works well with 2 by 4 walls

TFluna build holder, TF-Luna works

ERB/ELB disconnect

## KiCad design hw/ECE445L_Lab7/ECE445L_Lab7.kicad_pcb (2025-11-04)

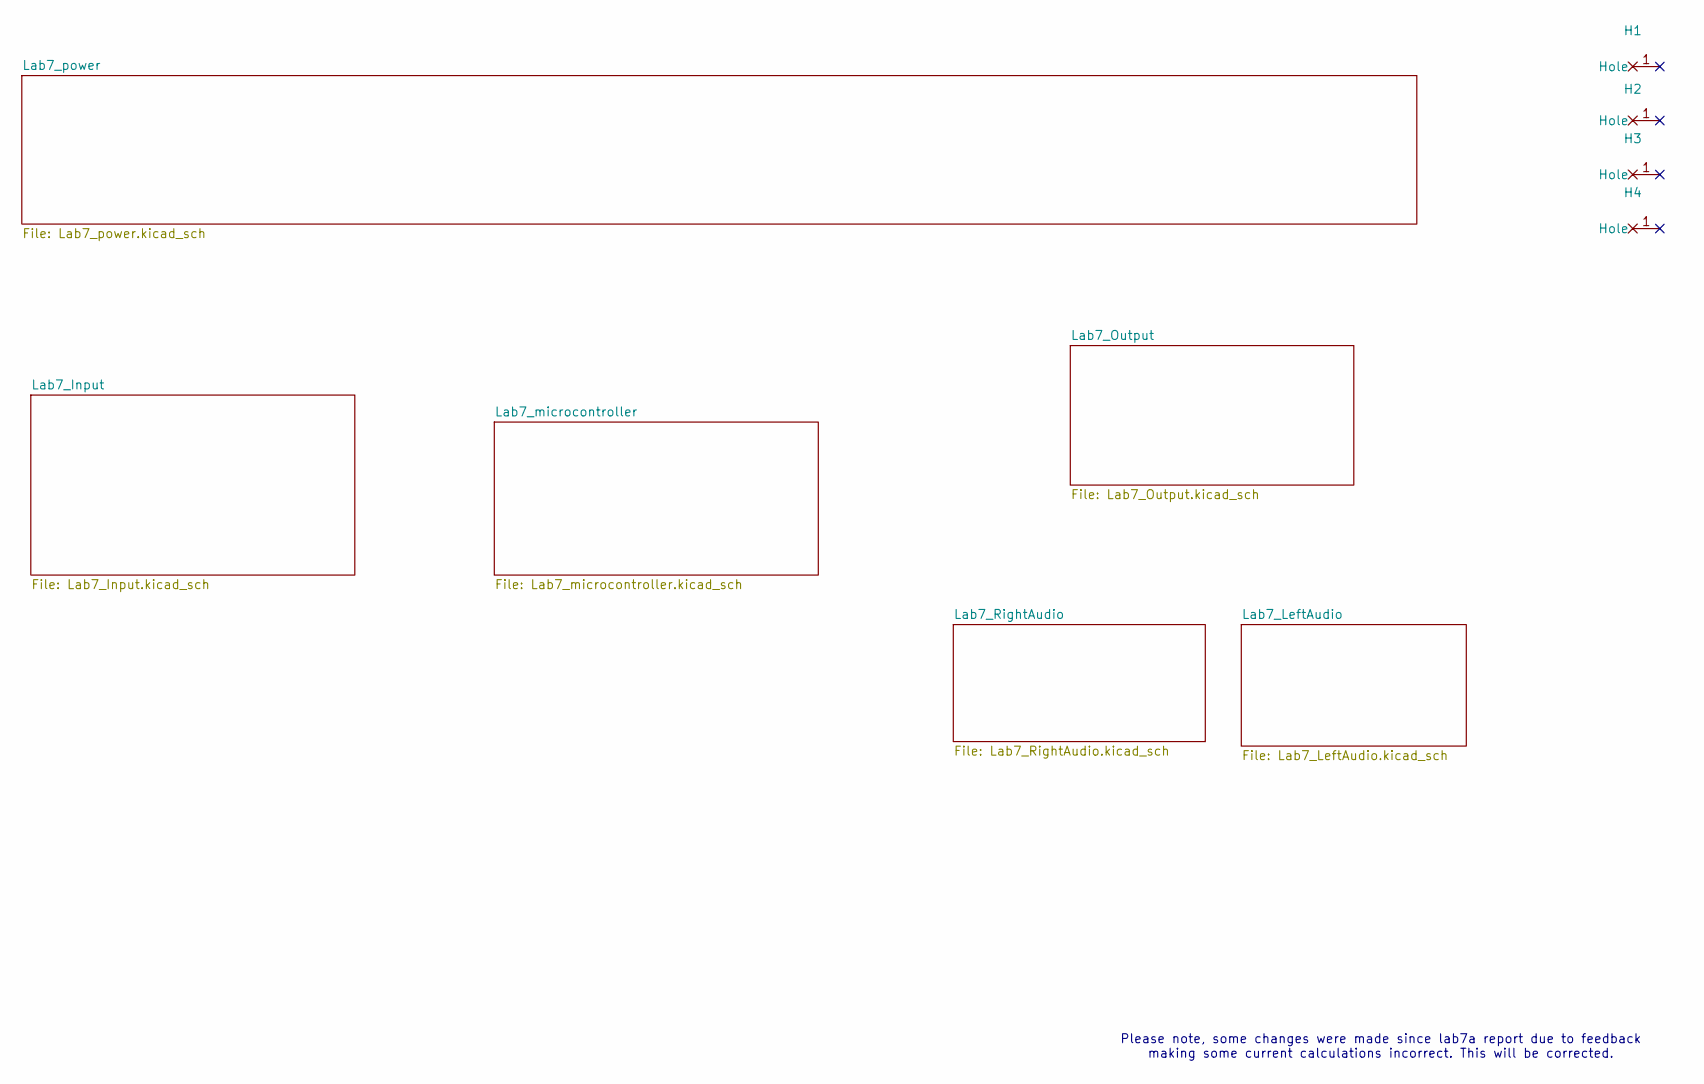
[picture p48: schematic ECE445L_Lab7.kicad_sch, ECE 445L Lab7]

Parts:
H1, H2, H3, H4: MountingHole_4_40

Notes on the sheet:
Please note, some changes were made since lab7a report due to feedback making some current calculations incorrect. This will be corrected.

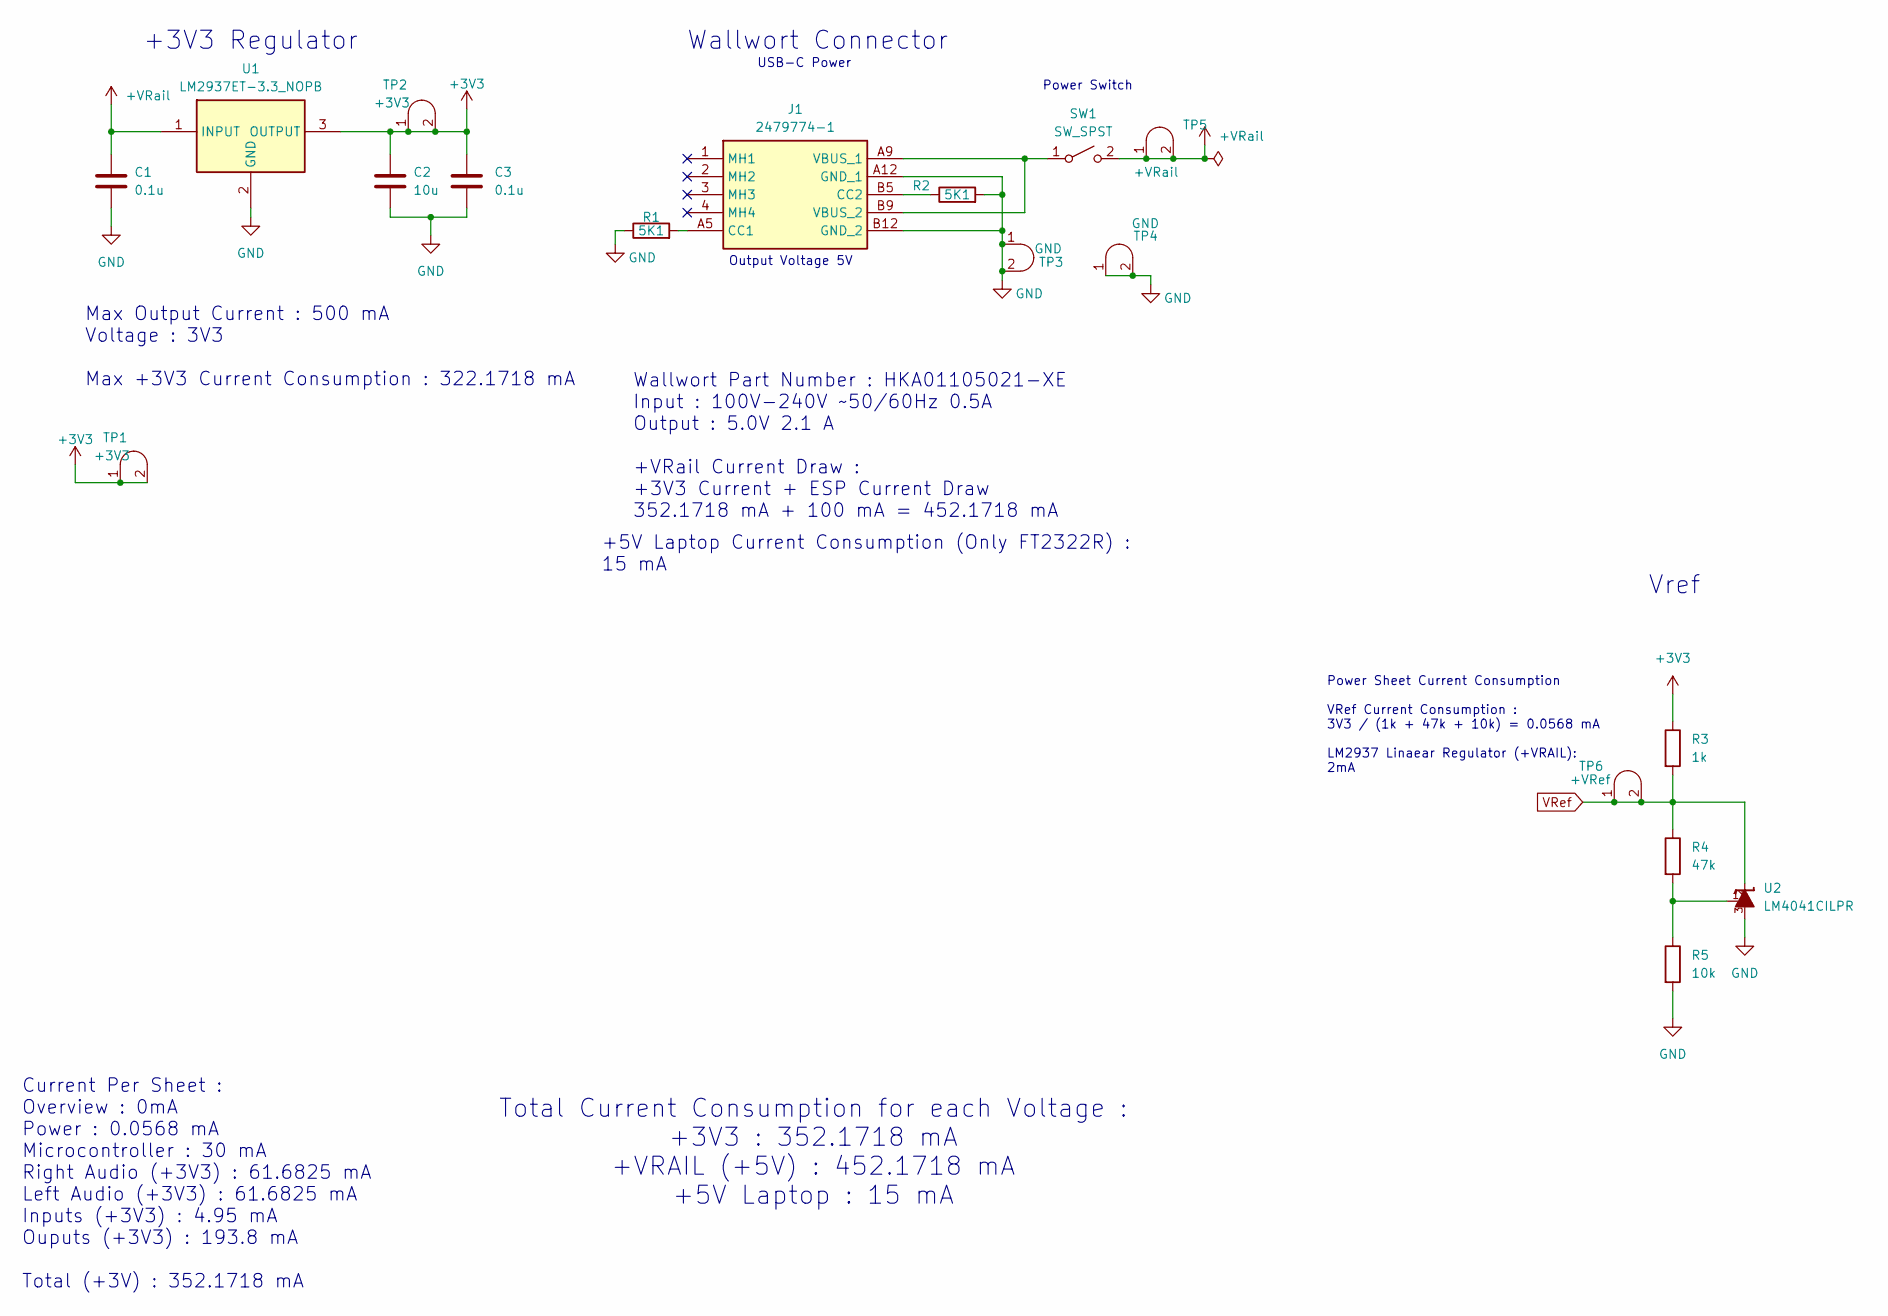
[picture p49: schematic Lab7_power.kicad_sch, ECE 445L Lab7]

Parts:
C1, C3: 0.1u; C_0603_1608Metric_Pad1.08x0.95mm_HandSolder
C2: 10u; C_0805_2012Metric_Pad1.18x1.45mm_HandSolder
J1: 2479774-1; 24797741; Manufacturer_Part_Number 2479774-1; Mouser Part Number 571-2479774-1
R1, R2: 5K1; R_0603_1608Metric_Pad0.98x0.95mm_HandSolder
R3: 1k; R_0603_1608Metric_Pad0.98x0.95mm_HandSolder
R4: 47k; R_0603_1608Metric_Pad0.98x0.95mm_HandSolder
R5: 10k; R_0603_1608Metric_Pad0.98x0.95mm_HandSolder
SW1: SW_SPST; SW-T3-1A-A-A3-S1
TP1, TP2: +3V3; Testpoint_1x02_P2.54mm
TP3, TP4: GND; Testpoint_1x02_P2.54mm
TP5: +VRail; Testpoint_1x02_P2.54mm
TP6: +VRef; Testpoint_1x02_P2.54mm
U1: LM2937ET-3.3_NOPB; TO254P470X1028X1955-3P; Mouser Part Number 926-LM2937ET-3.3NOPB
U2: LM4041CILPR; ti_LM4041CILPR

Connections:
+3V3: C2.1, C3.1, R3.1, TP1.1 (A), TP1.2 (B), TP2.1 (A), TP2.2 (B), U1.3 (OUTPUT); also elsewhere on the board
+VRail: C1.1, SW1.2 (B), TP5.1 (A), TP5.2 (B), U1.1 (INPUT); also elsewhere on the board
GND: C1.2, C2.2, C3.2, J1.A12 (GND_1), J1.B12 (GND_2), R1.1, R2.2, R5.2, TP3.1 (A), TP3.2 (B), TP4.1 (A), TP4.2 (B), U1.2 (GND), U2.3; also elsewhere on the board
unnamed: J1.A5 (CC1), R1.2
unnamed: J1.B5 (CC2), R2.1
unnamed: J1.A9 (VBUS_1), J1.B9 (VBUS_2), SW1.1 (A)
unnamed: R4.2, R5.1, U2.1
VRef: R3.2, R4.1, TP6.1 (A), TP6.2 (B), U2.2; also elsewhere on the board

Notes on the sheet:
Max Output Current : 500 mA Voltage : 3V3 Max +3V3 Current Consumption : 322.1718 mA
Wallwort Part Number : HKA01105021-XE Input : 100V-240V ~50/60Hz 0.5A Output : 5.0V 2.1 A +VRail Current Draw : +3V3 Current + ESP Current Draw 352.1718 mA + 100 mA = 452.1718 mA
Power Sheet Current Consumption VRef Current Consumption : 3V3 / (1k + 47k + 10k) = 0.0568 mA LM2937 Linaear Regulator (+VRAIL): 2mA
+3V3 Regulator
Power Switch
Output Voltage 5V
+5V Laptop Current Consumption (Only FT2322R) : 15 mA
USB-C Power
Current Per Sheet : Overview : 0mA Power : 0.0568 mA Microcontroller : 30 mA Right Audio (+3V3) : 61.6825 mA Left Audio (+3V3) : 61.6825 mA Inputs (+3V3) : 4.95 mA Ouputs (+3V3) : 193.8 mA Total (+3V) : 352.1718 mA
Total Current Consumption for each Voltage : +3V3 : 352.1718 mA +VRAIL (+5V) : 452.1718 mA +5V Laptop : 15 mA
Vref
Wallwort Connector

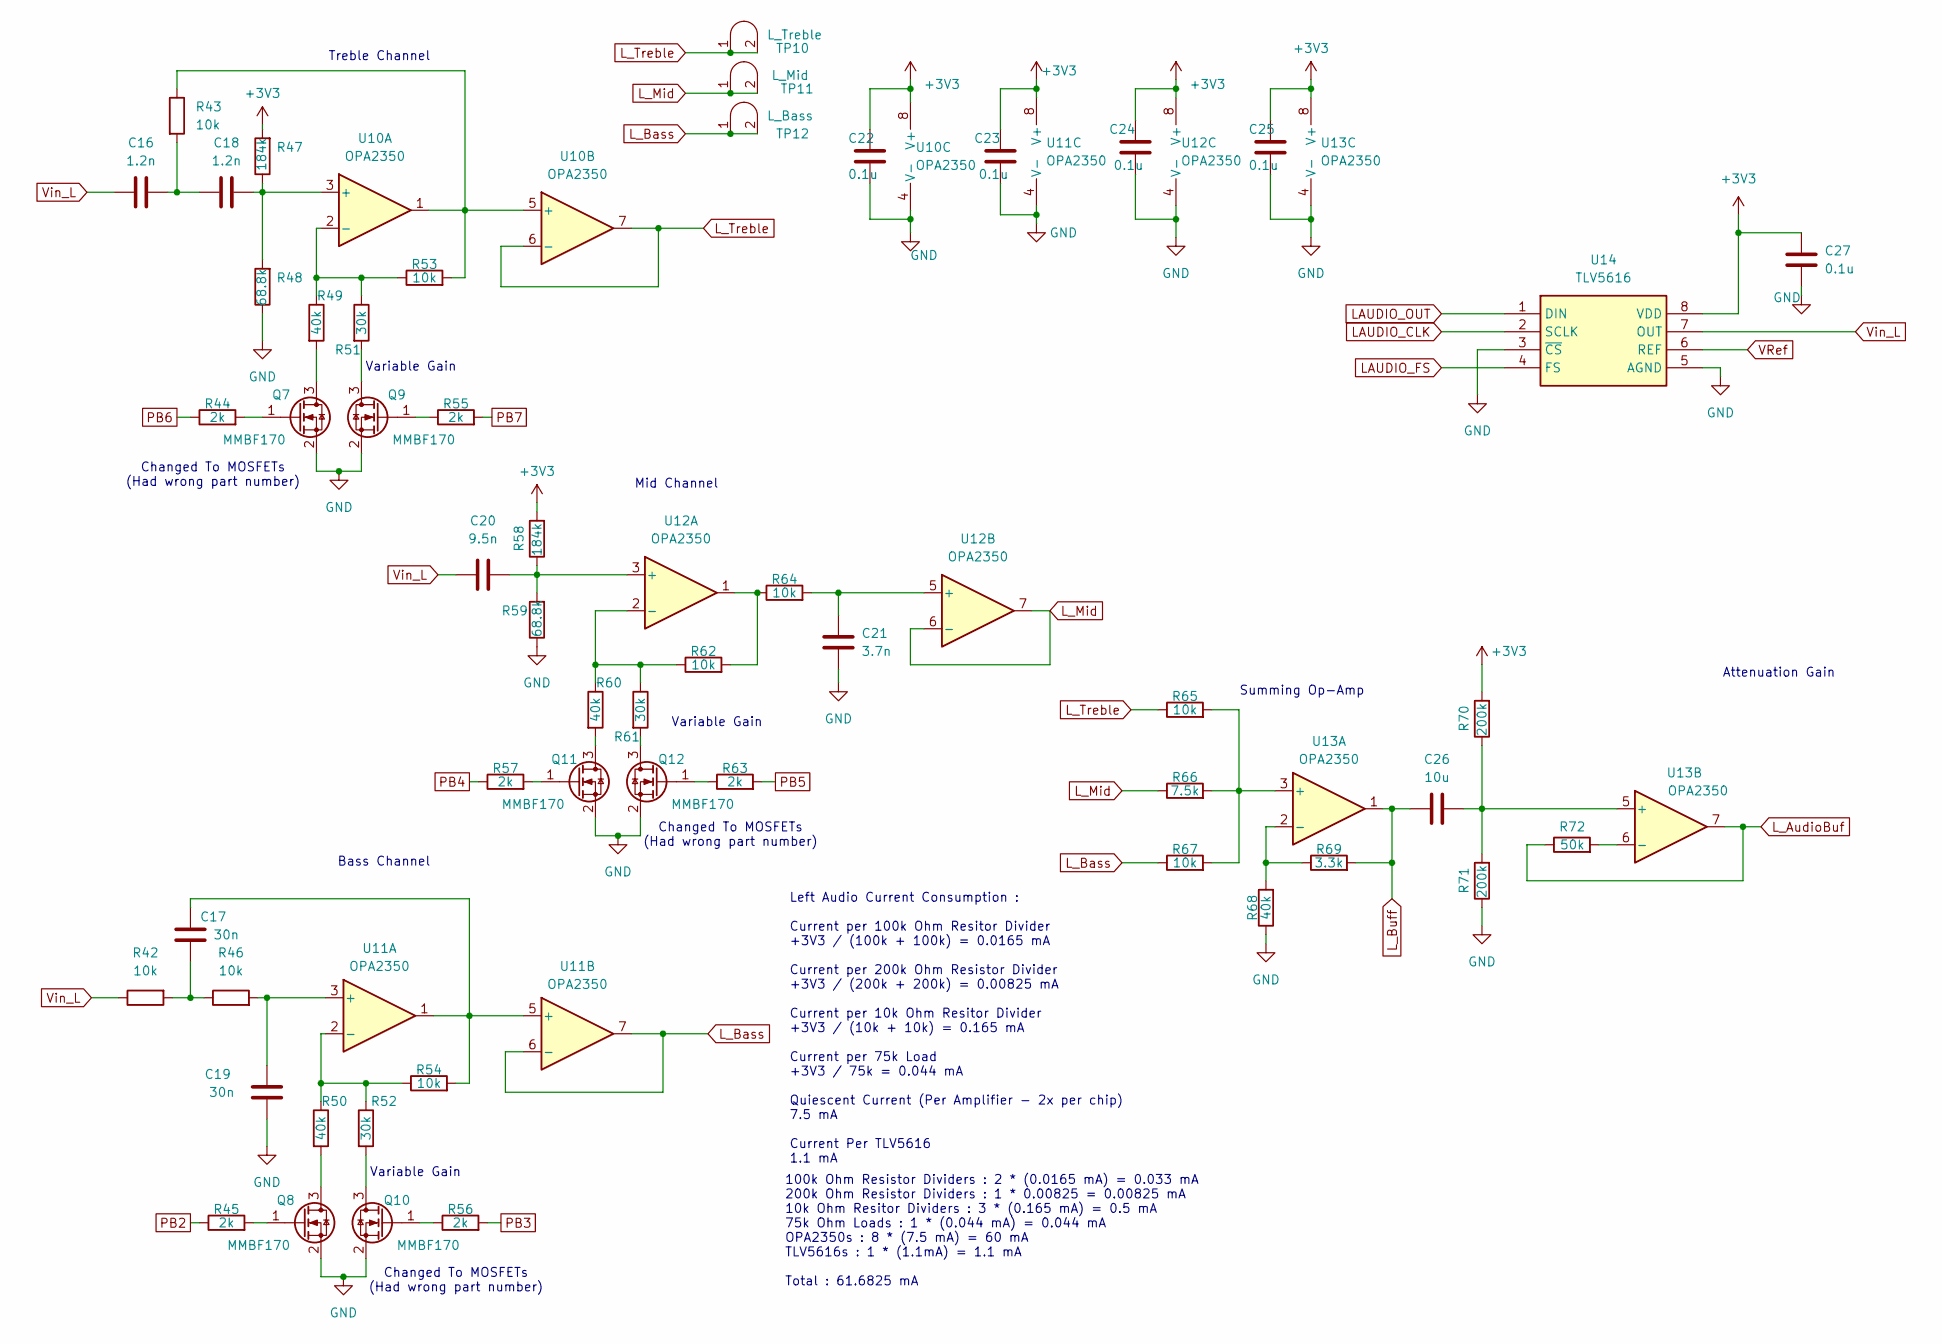
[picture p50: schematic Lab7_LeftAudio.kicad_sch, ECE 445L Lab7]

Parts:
C16, C18: 1.2n; C_0603_1608Metric_Pad1.08x0.95mm_HandSolder
C17, C19: 30n; C_0603_1608Metric_Pad1.08x0.95mm_HandSolder
C20: 9.5n; C_0603_1608Metric_Pad1.08x0.95mm_HandSolder
C21: 3.7n; C_0603_1608Metric_Pad1.08x0.95mm_HandSolder
C22, C23, C24, C25, C27: 0.1u; C_0603_1608Metric_Pad1.08x0.95mm_HandSolder
C26: 10u; C_0805_2012Metric_Pad1.18x1.45mm_HandSolder
Q7, Q8, Q9, Q10, Q11, Q12: MMBF170; SOT-23
R42, R43, R46, R53, R54, R62, R64, R65, R67: 10k; R_0603_1608Metric_Pad0.98x0.95mm_HandSolder
R44, R45, R55, R56, R57, R63: 2k; R_0603_1608Metric_Pad0.98x0.95mm_HandSolder
R47, R58: 184k; R_0603_1608Metric_Pad0.98x0.95mm_HandSolder
R48, R59: 68.8k; R_0603_1608Metric_Pad0.98x0.95mm_HandSolder
R49, R50, R60, R68: 40k; R_0603_1608Metric_Pad0.98x0.95mm_HandSolder
R51, R52, R61: 30k; R_0603_1608Metric_Pad0.98x0.95mm_HandSolder
R66: 7.5k; R_0603_1608Metric_Pad0.98x0.95mm_HandSolder
R69: 3.3k; R_0603_1608Metric_Pad0.98x0.95mm_HandSolder
R70, R71: 200k; R_0603_1608Metric_Pad0.98x0.95mm_HandSolder
R72: 50k; R_0603_1608Metric_Pad0.98x0.95mm_HandSolder
TP10: L_Treble; Testpoint_1x02_P2.54mm
TP11: L_Mid; Testpoint_1x02_P2.54mm
TP12: L_Bass; Testpoint_1x02_P2.54mm
U10, U11, U12, U13: OPA2350; DIP-8_W7.62mm_LongPads
U14: TLV5616; DIP-8_W7.62mm_LongPads

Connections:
+3V3: C22.2, C23.2, C24.2, C25.2, C27.1, R47.2, R58.2, R70.2, U10.8 (V+), U11.8 (V+), U12.8 (V+), U13.8 (V+), U14.8 (VDD); also elsewhere on the board
GND: C19.2, C21.1, C22.1, C23.1, C24.1, C25.1, C27.2, Q7.2 (S), Q8.2 (S), Q9.2 (S), Q10.2 (S), Q11.2 (S), Q12.2 (S), R48.1, R59.1, R68.1, R71.1, U10.4 (V-), U11.4 (V-), U12.4 (V-), U13.4 (V-), U14.3 (~CS), U14.5 (AGND); also elsewhere on the board
LAUDIO_CLK: U14.2 (SCLK); also elsewhere on the board
LAUDIO_FS: U14.4 (FS); also elsewhere on the board
LAUDIO_OUT: U14.1 (DIN); also elsewhere on the board
L_AudioBuf: R72.1, U13.7; also elsewhere on the board
L_Bass: R67.1, TP12.1 (A), TP12.2 (B), U11.6 (-), U11.7
L_Buff: C26.1, R69.2, U13.1
L_Mid: R66.1, TP11.1 (A), TP11.2 (B), U12.6 (-), U12.7
L_Treble: R65.1, TP10.1 (A), TP10.2 (B), U10.6 (-), U10.7
unnamed: C16.2, C18.1, R43.2
unnamed: C17.2, R42.2, R46.1
unnamed: Q7.3 (D), R49.2
unnamed: Q7.1 (G), R44.2
unnamed: Q8.3 (D), R50.2
unnamed: Q8.1 (G), R45.2
unnamed: Q9.3 (D), R51.2
unnamed: Q9.1 (G), R55.1
unnamed: Q10.3 (D), R52.2
unnamed: Q10.1 (G), R56.1
unnamed: Q11.3 (D), R60.2
unnamed: Q11.1 (G), R57.2
unnamed: Q12.3 (D), R61.2
unnamed: Q12.1 (G), R63.1
unnamed: R62.2, R64.1, U12.1
unnamed: C18.2, R47.1, R48.2, U10.3 (+)
unnamed: R49.1, R51.1, R53.1, U10.2 (-)
unnamed: R43.1, R53.2, U10.1, U10.5 (+)
unnamed: C19.1, R46.2, U11.3 (+)
unnamed: R50.1, R52.1, R54.1, U11.2 (-)
unnamed: C17.1, R54.2, U11.1, U11.5 (+)
unnamed: C20.2, R58.1, R59.2, U12.3 (+)
unnamed: R60.1, R61.1, R62.1, U12.2 (-)
unnamed: C21.2, R64.2, U12.5 (+)
unnamed: R65.2, R66.2, R67.2, U13.3 (+)
unnamed: R68.2, R69.1, U13.2 (-)
unnamed: C26.2, R70.1, R71.2, U13.5 (+)
unnamed: R72.2, U13.6 (-)
PB2: R45.1; also elsewhere on the board
PB3: R56.2; also elsewhere on the board
PB4: R57.1; also elsewhere on the board
PB5: R63.2; also elsewhere on the board
PB6: R44.1; also elsewhere on the board
PB7: R55.2; also elsewhere on the board
VRef: U14.6 (REF); also elsewhere on the board
Vin_L: C16.1, C20.1, R42.1, U14.7 (OUT)

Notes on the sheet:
Variable Gain
Treble Channel
Attenuation Gain
100k Ohm Resistor Dividers : 2 * (0.0165 mA) = 0.033 mA 200k Ohm Resistor Dividers : 1 * 0.00825 = 0.00825 mA 10k Ohm Resitor Dividers : 3 * (0.165 mA) = 0.5 mA 75k Ohm Loads : 1 * (0.044 mA) = 0.044 mA OPA2350s : 8 * (7.5 mA) = 60 mA TLV5616s : 1 * (1.1mA) = 1.1 mA Total : 61.6825 mA
Bass Channel
Left Audio Current Consumption : Current per 100k Ohm Resitor Divider +3V3 / (100k + 100k) = 0.0165 mA Current per 200k Ohm Resistor Divider +3V3 / (200k + 200k) = 0.00825 mA Current per 10k Ohm Resitor Divider +3V3 / (10k + 10k) = 0.165 mA Current per 75k Load +3V3 / 75k = 0.044 mA Quiescent Curre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
Mid Channel
Changed To MOSFETs (Had wrong part number)
Summing Op-Amp

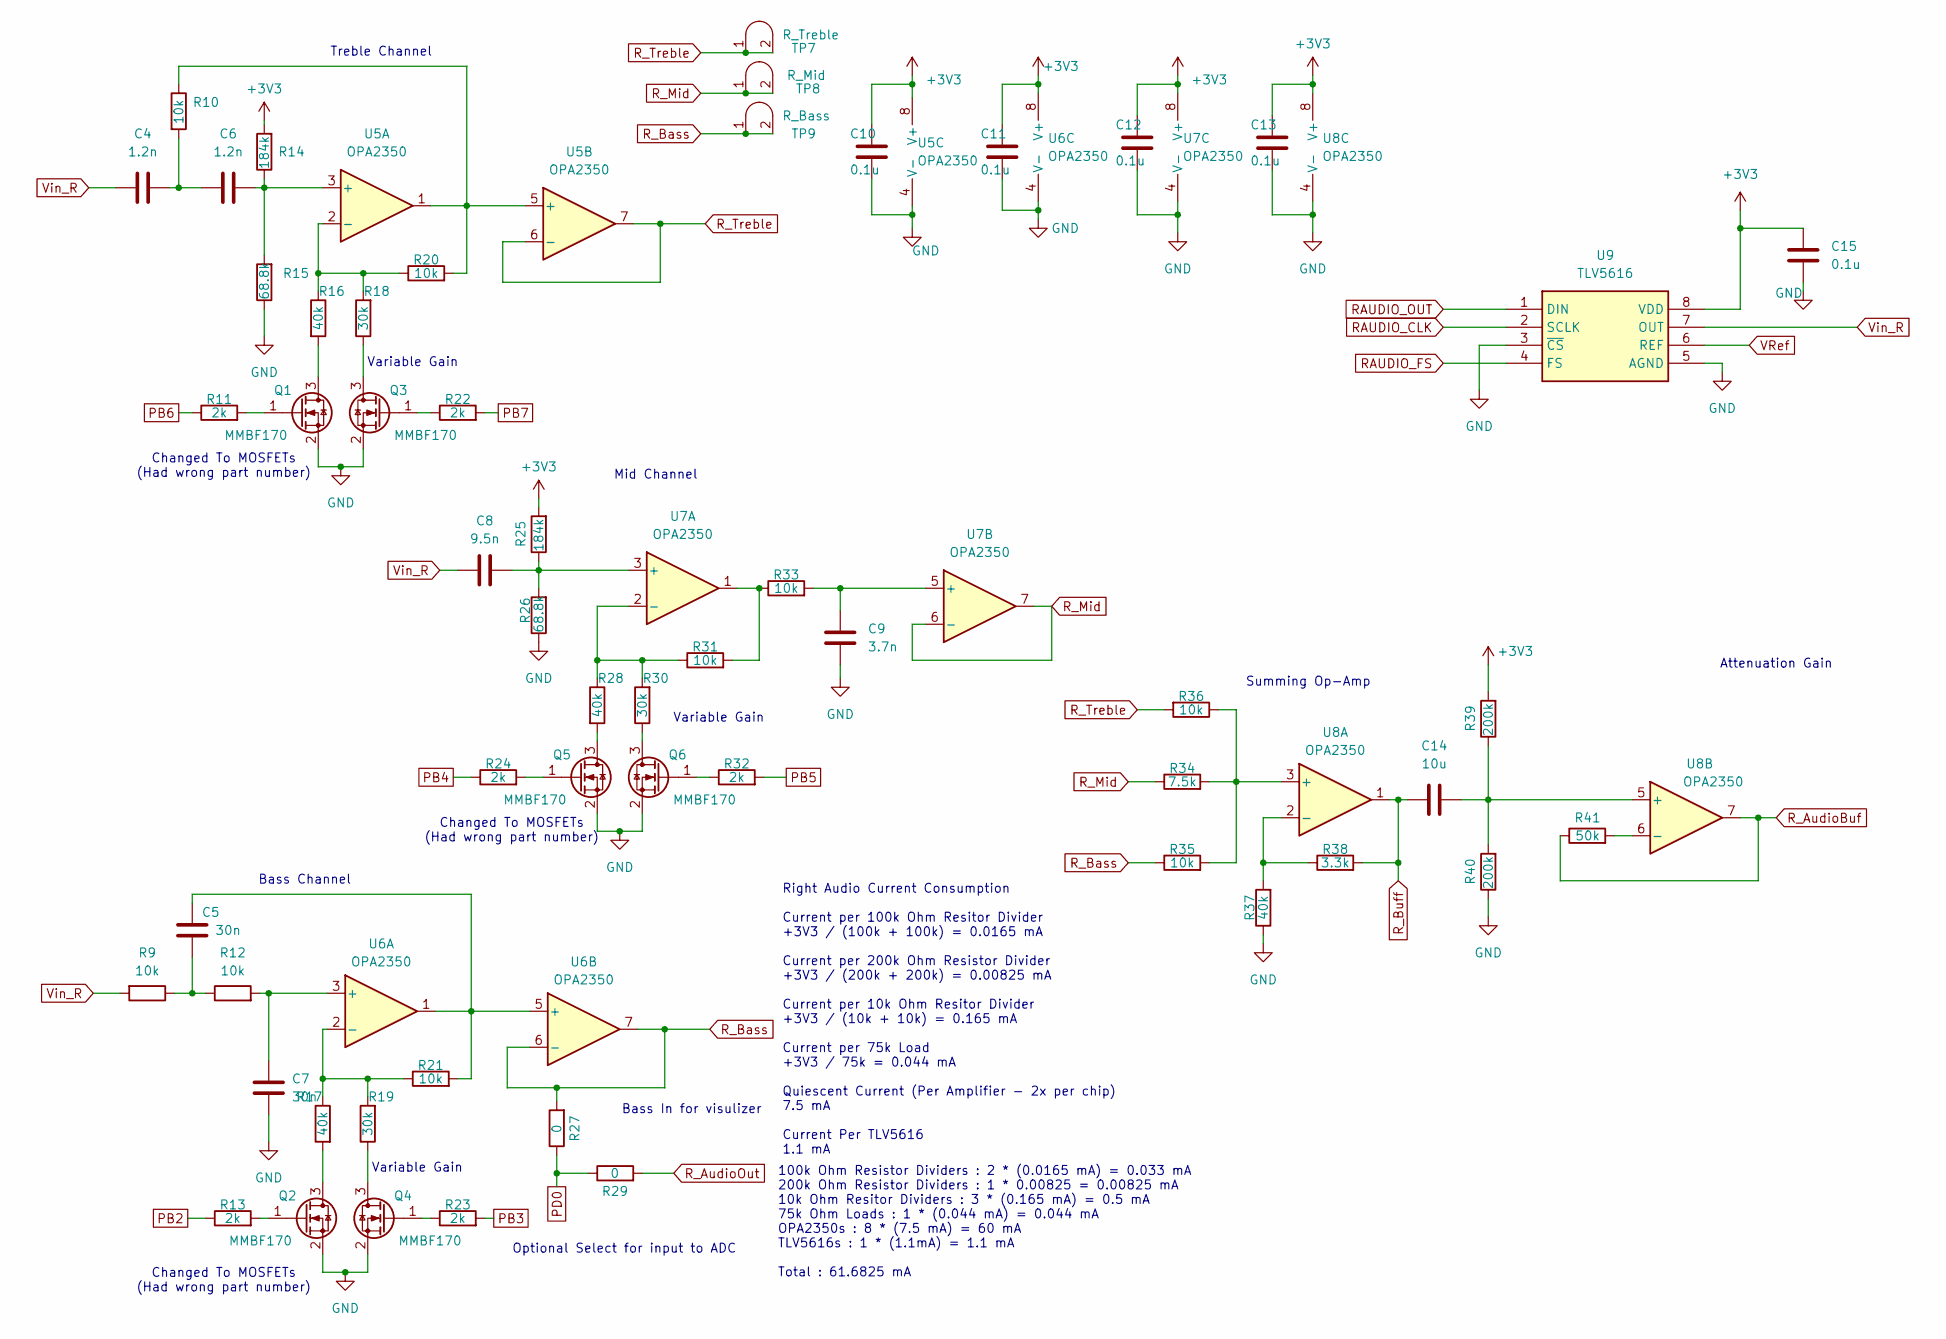
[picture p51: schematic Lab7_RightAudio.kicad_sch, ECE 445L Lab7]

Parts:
C4, C6: 1.2n; C_0603_1608Metric_Pad1.08x0.95mm_HandSolder
C5, C7: 30n; C_0603_1608Metric_Pad1.08x0.95mm_HandSolder
C8: 9.5n; C_0603_1608Metric_Pad1.08x0.95mm_HandSolder
C9: 3.7n; C_0603_1608Metric_Pad1.08x0.95mm_HandSolder
C10, C11, C12, C13, C15: 0.1u; C_0603_1608Metric_Pad1.08x0.95mm_HandSolder
C14: 10u; C_0805_2012Metric_Pad1.18x1.45mm_HandSolder
Q1, Q2, Q3, Q4, Q5, Q6: MMBF170; SOT-23
R9, R10, R12, R20, R21, R31, R33, R35, R36: 10k; R_0603_1608Metric_Pad0.98x0.95mm_HandSolder
R11, R13, R22, R23, R24, R32: 2k; R_0603_1608Metric_Pad0.98x0.95mm_HandSolder
R14, R25: 184k; R_0603_1608Metric_Pad0.98x0.95mm_HandSolder
R15, R26: 68.8k; R_0603_1608Metric_Pad0.98x0.95mm_HandSolder
R16, R17, R28, R37: 40k; R_0603_1608Metric_Pad0.98x0.95mm_HandSolder
R18, R19, R30: 30k; R_0603_1608Metric_Pad0.98x0.95mm_HandSolder
R27, R29: 0; R_0603_1608Metric_Pad0.98x0.95mm_HandSolder
R34: 7.5k; R_0603_1608Metric_Pad0.98x0.95mm_HandSolder
R38: 3.3k; R_0603_1608Metric_Pad0.98x0.95mm_HandSolder
R39, R40: 200k; R_0603_1608Metric_Pad0.98x0.95mm_HandSolder
R41: 50k; R_0603_1608Metric_Pad0.98x0.95mm_HandSolder
TP7: R_Treble; Testpoint_1x02_P2.54mm
TP8: R_Mid; Testpoint_1x02_P2.54mm
TP9: R_Bass; Testpoint_1x02_P2.54mm
U5, U6, U7, U8: OPA2350; DIP-8_W7.62mm_LongPads
U9: TLV5616; DIP-8_W7.62mm_LongPads

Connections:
+3V3: C10.2, C11.2, C12.2, C13.2, C15.1, R14.2, R25.2, R39.2, U5.8 (V+), U6.8 (V+), U7.8 (V+), U8.8 (V+), U9.8 (VDD); also elsewhere on the board
GND: C7.2, C9.1, C10.1, C11.1, C12.1, C13.1, C15.2, Q1.2 (S), Q2.2 (S), Q3.2 (S), Q4.2 (S), Q5.2 (S), Q6.2 (S), R15.1, R26.1, R37.1, R40.1, U5.4 (V-), U6.4 (V-), U7.4 (V-), U8.4 (V-), U9.3 (~CS), U9.5 (AGND); also elsewhere on the board
unnamed: C4.2, C6.1, R10.2
unnamed: C5.2, R9.1, R12.1
unnamed: Q1.3 (D), R16.2
unnamed: Q1.1 (G), R11.2
unnamed: Q2.3 (D), R17.2
unnamed: Q2.1 (G), R13.2
unnamed: Q3.3 (D), R18.1
unnamed: Q3.1 (G), R22.1
unnamed: Q4.3 (D), R19.1
unnamed: Q4.1 (G), R23.1
unnamed: Q5.3 (D), R28.2
unnamed: Q5.1 (G), R24.2
unnamed: Q6.3 (D), R30.1
unnamed: Q6.1 (G), R32.1
unnamed: R31.2, R33.1, U7.1
unnamed: C6.2, R14.1, R15.2, U5.3 (+)
unnamed: R16.1, R18.2, R20.1, U5.2 (-)
unnamed: R10.1, R20.2, U5.1, U5.5 (+)
unnamed: C7.1, R12.2, U6.3 (+)
unnamed: R17.1, R19.2, R21.1, U6.2 (-)
unnamed: C5.1, R21.2, U6.1, U6.5 (+)
unnamed: C8.2, R25.1, R26.2, U7.3 (+)
unnamed: R28.1, R30.2, R31.1, U7.2 (-)
unnamed: C9.2, R33.2, U7.5 (+)
unnamed: R34.2, R35.2, R36.1, U8.3 (+)
unnamed: R37.2, R38.1, U8.2 (-)
unnamed: C14.2, R39.1, R40.2, U8.5 (+)
unnamed: R41.2, U8.6 (-)
PB2: R13.1; also elsewhere on the board
PB3: R23.2; also elsewhere on the board
PB4: R24.1; also elsewhere on the board
PB5: R32.2; also elsewhere on the board
PB6: R11.1; also elsewhere on the board
PB7: R22.2; also elsewhere on the board
PD0: R27.1, R29.1; also elsewhere on the board
RAUDIO_CLK: U9.2 (SCLK); also elsewhere on the board
RAUDIO_FS: U9.4 (FS); also elsewhere on the board
RAUDIO_OUT: U9.1 (DIN); also elsewhere on the board
R_AudioBuf: R41.1, U8.7; also elsewhere on the board
R_AudioOut: R29.2; also elsewhere on the board
R_Bass: R27.2, R35.1, TP9.1 (A), TP9.2 (B), U6.6 (-), U6.7
R_Buff: C14.1, R38.2, U8.1
R_Mid: R34.1, TP8.1 (A), TP8.2 (B), U7.6 (-), U7.7
R_Treble: R36.2, TP7.1 (A), TP7.2 (B), U5.6 (-), U5.7
VRef: U9.6 (REF); also elsewhere on the board
Vin_R: C4.1, C8.1, R9.2, U9.7 (OUT)

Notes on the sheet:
Variable Gain
Changed To MOSFETs (Had wrong part number)
100k Ohm Resistor Dividers : 2 * (0.0165 mA) = 0.033 mA 200k Ohm Resistor Dividers : 1 * 0.00825 = 0.00825 mA 10k Ohm Resitor Dividers : 3 * (0.165 mA) = 0.5 mA 75k Ohm Loads : 1 * (0.044 mA) = 0.044 mA OPA2350s : 8 * (7.5 mA) = 60 mA TLV5616s : 1 * (1.1mA) = 1.1 mA Total : 61.6825 mA
Mid Channel
Right Audio Current Consumption Current per 100k Ohm Resitor Divider +3V3 / (100k + 100k) = 0.0165 mA Current per 200k Ohm Resistor Divider +3V3 / (200k + 200k) = 0.00825 mA Current per 10k Ohm Resitor Divider +3V3 / (10k + 10k) = 0.165 mA Current per 75k Load +3V3 / 75k = 0.044 mA Quiescent Curren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
Treble Channel
Summing Op-Amp
Bass Channel
Optional Select for input to ADC
Attenuation Gain
Bass In for visulizer

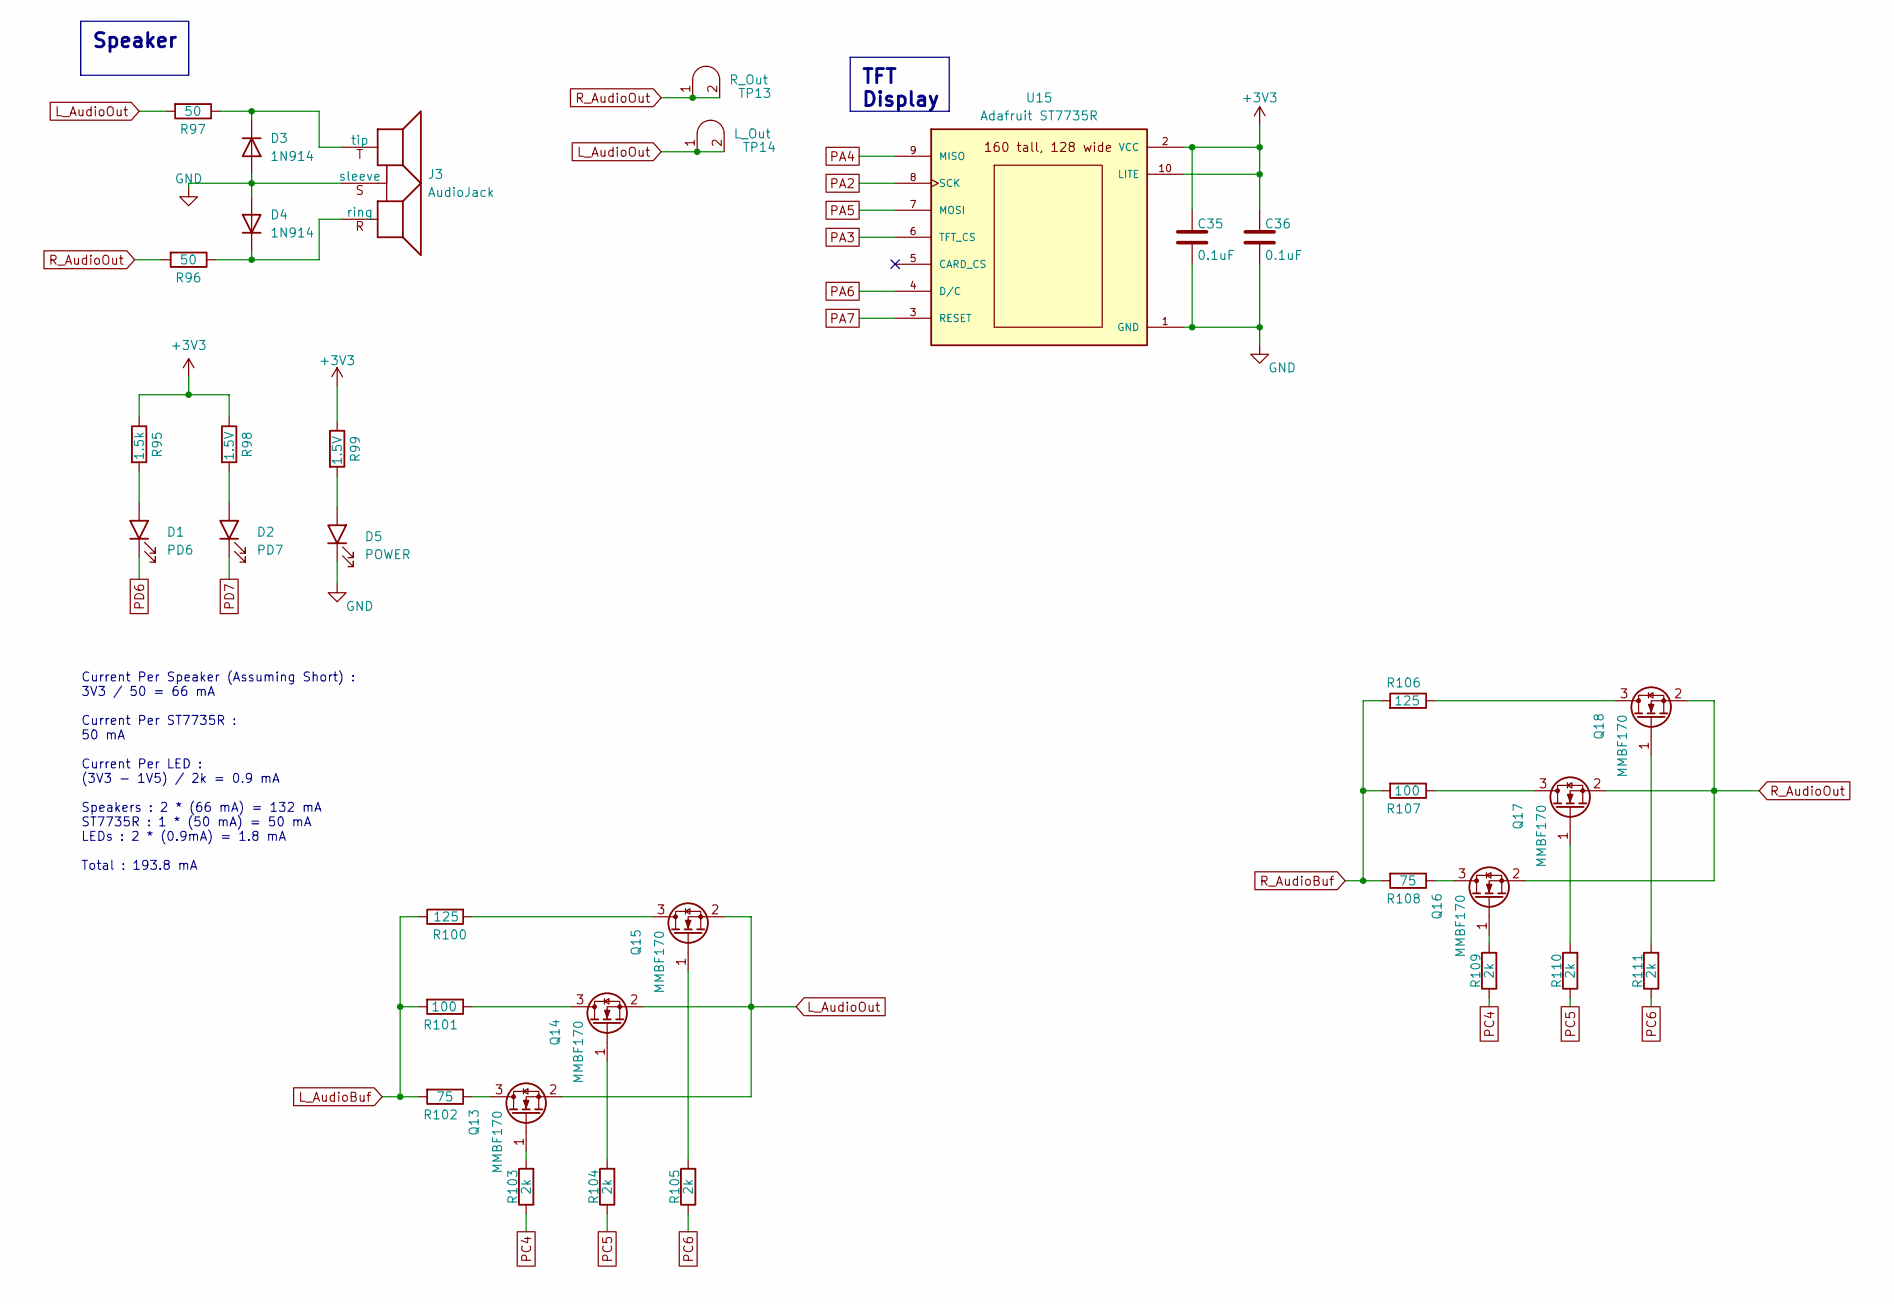
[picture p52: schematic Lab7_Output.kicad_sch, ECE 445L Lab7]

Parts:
C35, C36: 0.1uF; C_0603_1608Metric_Pad1.08x0.95mm_HandSolder
D1: PD6; LED_D5.0mm
D2: PD7; LED_D5.0mm
D3, D4: 1N914; Testpoint_1x02_P2.54mm
D5: POWER; LED_D5.0mm
J3: AudioJack; STX3000
Q13, Q14, Q15, Q16, Q17, Q18: MMBF170; SOT-23
R95: 1.5k; R_0603_1608Metric_Pad0.98x0.95mm_HandSolder
R96, R97: 50; R_0603_1608Metric_Pad0.98x0.95mm_HandSolder
R98, R99: 1.5V; R_0603_1608Metric_Pad0.98x0.95mm_HandSolder
R100, R106: 125; R_0603_1608Metric_Pad0.98x0.95mm_HandSolder
R101, R107: 100; R_0603_1608Metric_Pad0.98x0.95mm_HandSolder
R102, R108: 75; R_0603_1608Metric_Pad0.98x0.95mm_HandSolder
R103, R104, R105, R109, R110, R111: 2k; R_0603_1608Metric_Pad0.98x0.95mm_HandSolder
TP13: R_Out; Testpoint_1x02_P2.54mm
TP14: L_Out; Testpoint_1x02_P2.54mm
U15: Adafruit ST7735R; adafruit_st7735r2

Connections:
+3V3: C35.1, C36.1, R95.1, R98.1, R99.1, U15.2 (VCC), U15.10 (LITE); also elsewhere on the board
GND: C35.2, C36.2, D3.2 (A), D4.2 (A), D5.1 (K), J3.S (sleeve), U15.1 (GND); also elsewhere on the board
L_AudioBuf: R100.1, R101.2, R102.2; also elsewhere on the board
L_AudioOut: Q13.2 (S), Q14.2 (S), Q15.2 (S), R97.2, TP14.1 (A), TP14.2 (B)
unnamed: D1.2 (A), R95.2
unnamed: D2.2 (A), R98.2
unnamed: D3.1 (K), J3.T (tip), R97.1
unnamed: D4.1 (K), J3.R (ring), R96.1
unnamed: D5.2 (A), R99.2
unnamed: Q13.3 (D), R102.1
unnamed: Q13.1 (G), R103.2
unnamed: Q14.3 (D), R101.1
unnamed: Q14.1 (G), R104.2
unnamed: Q15.3 (D), R100.2
unnamed: Q15.1 (G), R105.2
unnamed: Q16.3 (D), R108.1
unnamed: Q16.1 (G), R109.2
unnamed: Q17.3 (D), R107.1
unnamed: Q17.1 (G), R110.2
unnamed: Q18.3 (D), R106.1
unnamed: Q18.1 (G), R111.2
PA2: U15.8 (SCK); also elsewhere on the board
PA3: U15.6 (TFT_CS); also elsewhere on the board
PA4: U15.9 (MISO); also elsewhere on the board
PA5: U15.7 (MOSI); also elsewhere on the board
PA6: U15.4 (D/C); also elsewhere on the board
PA7: U15.3 (RESET); also elsewhere on the board
PC4: R103.1, R109.1; also elsewhere on the board
PC5: R104.1, R110.1; also elsewhere on the board
PC6: R105.1, R111.1; also elsewhere on the board
PD6: D1.1 (K); also elsewhere on the board
PD7: D2.1 (K); also elsewhere on the board
R_AudioBuf: R106.2, R107.2, R108.2; also elsewhere on the board
R_AudioOut: Q16.2 (S), Q17.2 (S), Q18.2 (S), R96.2, TP13.1 (A), TP13.2 (B); also elsewhere on the board

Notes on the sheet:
Current Per Speaker (Assuming Short) : 3V3 / 50 = 66 mA Current Per ST7735R : 50 mA Current Per LED : (3V3 - 1V5) / 2k = 0.9 mA Speakers : 2 * (66 mA) = 132 mA ST7735R : 1 * (50 mA) = 50 mA LEDs : 2 * (0.9mA) = 1.8 mA Total : 193.8 mA
TFT Display
Speaker

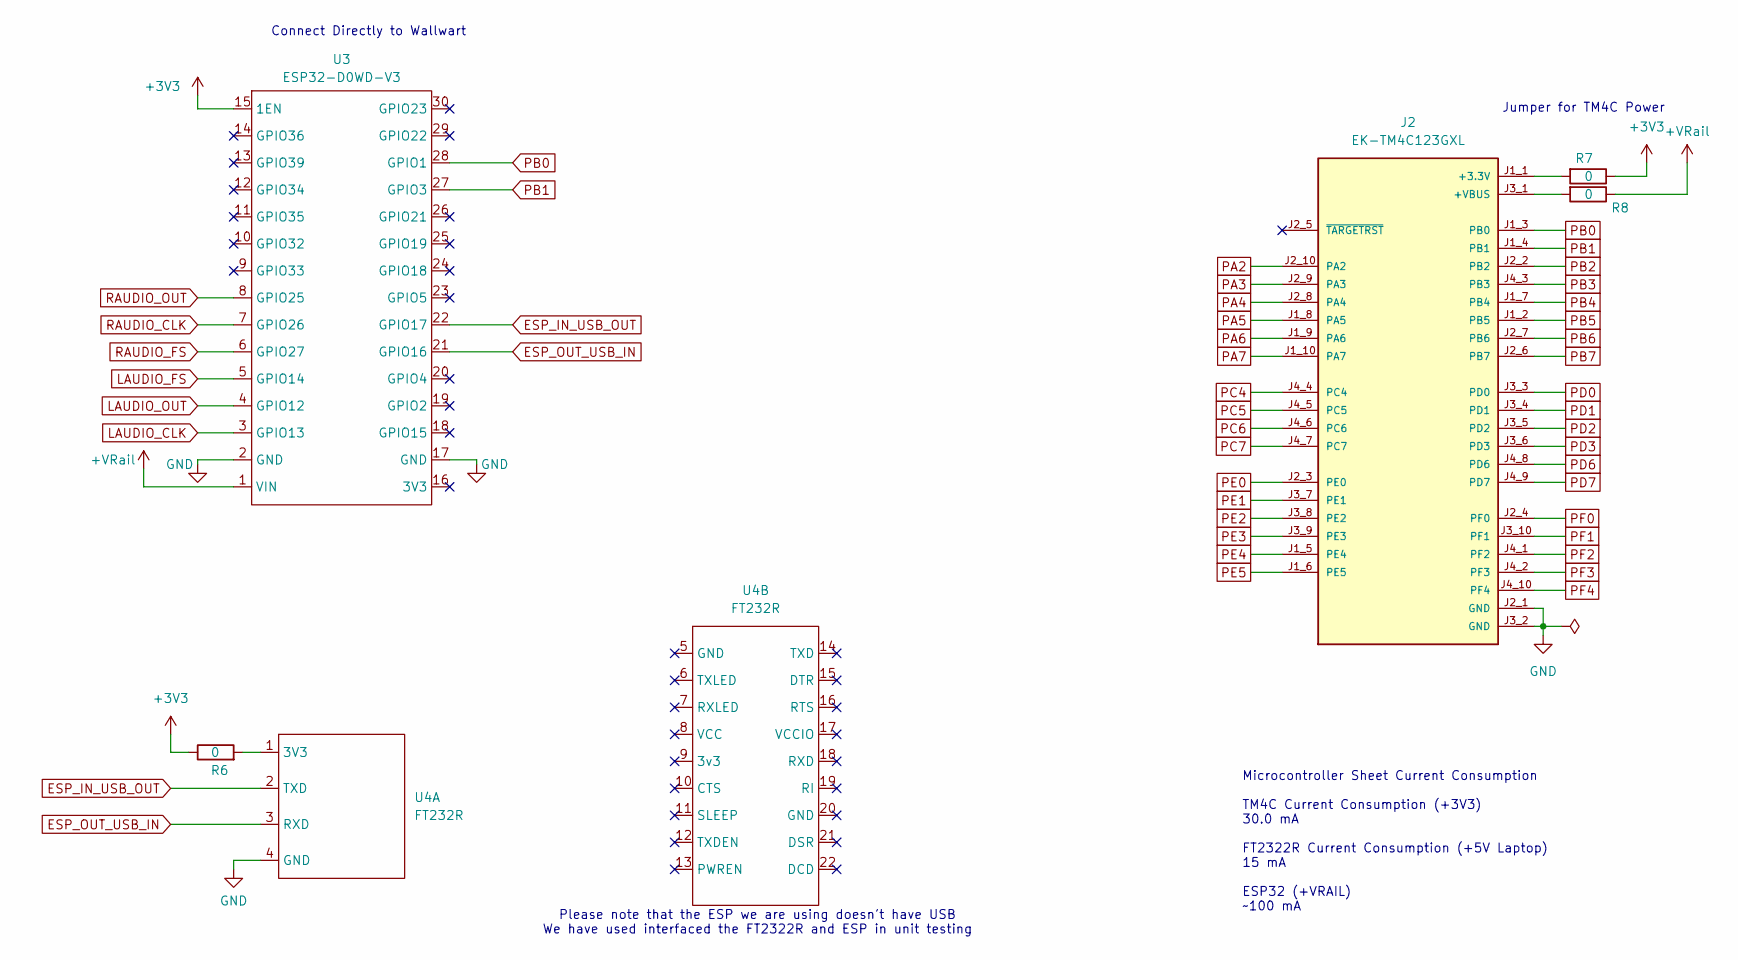
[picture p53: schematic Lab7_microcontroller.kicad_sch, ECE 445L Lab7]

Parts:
J2: EK-TM4C123GXL; ti_EKTM4C123GXL
R6, R7, R8: 0; R_0603_1608Metric_Pad0.98x0.95mm_HandSolder
U3: ESP32-D0WD-V3; ESP32_30pin
U4: FT232R; FT232R-Breakout

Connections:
+3V3: R6.1, R7.1, U3.15 (1EN); also elsewhere on the board
+VRail: R8.1, U3.1 (VIN); also elsewhere on the board
ESP_IN_USB_OUT: U3.22 (GPIO17), U4.2 (TXD)
ESP_OUT_USB_IN: U3.21 (GPIO16), U4.3 (RXD)
GND: J2.J2_1 (GND), J2.J3_2 (GND), U3.2 (GND), U3.17 (GND), U4.4 (GND); also elsewhere on the board
LAUDIO_CLK: U3.3 (GPIO13); also elsewhere on the board
LAUDIO_FS: U3.5 (GPIO14); also elsewhere on the board
LAUDIO_OUT: U3.4 (GPIO12); also elsewhere on the board
unnamed: J2.J1_1 (+3.3V), R7.2
unnamed: J2.J3_1 (+VBUS), R8.2
unnamed: R6.2, U4.1 (3V3)
PA2: J2.J2_10 (PA2); also elsewhere on the board
PA3: J2.J2_9 (PA3); also elsewhere on the board
PA4: J2.J2_8 (PA4); also elsewhere on the board
PA5: J2.J1_8 (PA5); also elsewhere on the board
PA6: J2.J1_9 (PA6); also elsewhere on the board
PA7: J2.J1_10 (PA7); also elsewhere on the board
PB0: J2.J1_3 (PB0), U3.28 (GPIO1)
PB1: J2.J1_4 (PB1), U3.27 (GPIO3)
PB2: J2.J2_2 (PB2); also elsewhere on the board
PB3: J2.J4_3 (PB3); also elsewhere on the board
PB4: J2.J1_7 (PB4); also elsewhere on the board
PB5: J2.J1_2 (PB5); also elsewhere on the board
PB6: J2.J2_7 (PB6); also elsewhere on the board
PB7: J2.J2_6 (PB7); also elsewhere on the board
PC4: J2.J4_4 (PC4); also elsewhere on the board
PC5: J2.J4_5 (PC5); also elsewhere on the board
PC6: J2.J4_6 (PC6); also elsewhere on the board
PC7: J2.J4_7 (PC7); also elsewhere on the board
PD0: J2.J3_3 (PD0); also elsewhere on the board
PD1: J2.J3_4 (PD1); also elsewhere on the board
PD2: J2.J3_5 (PD2); also elsewhere on the board
PD3: J2.J3_6 (PD3); also elsewhere on the board
PD6: J2.J4_8 (PD6); also elsewhere on the board
PD7: J2.J4_9 (PD7); also elsewhere on the board
PE0: J2.J2_3 (PE0); also elsewhere on the board
PE1: J2.J3_7 (PE1); also elsewhere on the board
PE2: J2.J3_8 (PE2); also elsewhere on the board
PE3: J2.J3_9 (PE3); also elsewhere on the board
PE4: J2.J1_5 (PE4); also elsewhere on the board
PE5: J2.J1_6 (PE5); also elsewhere on the board
PF0: J2.J2_4 (PF0); also elsewhere on the board
PF1: J2.J3_10 (PF1); also elsewhere on the board
PF2: J2.J4_1 (PF2); also elsewhere on the board
PF3: J2.J4_2 (PF3); also elsewhere on the board
PF4: J2.J4_10 (PF4); also elsewhere on the board
RAUDIO_CLK: U3.7 (GPIO26); also elsewhere on the board
RAUDIO_FS: U3.6 (GPIO27); also elsewhere on the board
RAUDIO_OUT: U3.8 (GPIO25); also elsewhere on the board

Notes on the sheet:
Microcontroller Sheet Current Consumption TM4C Current Consumption (+3V3) 30.0 mA FT2322R Current Consumption (+5V Laptop) 15 mA ESP32 (+VRAIL) ~100 mA
Please note that the ESP we are using doesn't have USB We have used interfaced the FT2322R and ESP in unit testing
Connect Directly to Wallwart
Jumper for TM4C Power

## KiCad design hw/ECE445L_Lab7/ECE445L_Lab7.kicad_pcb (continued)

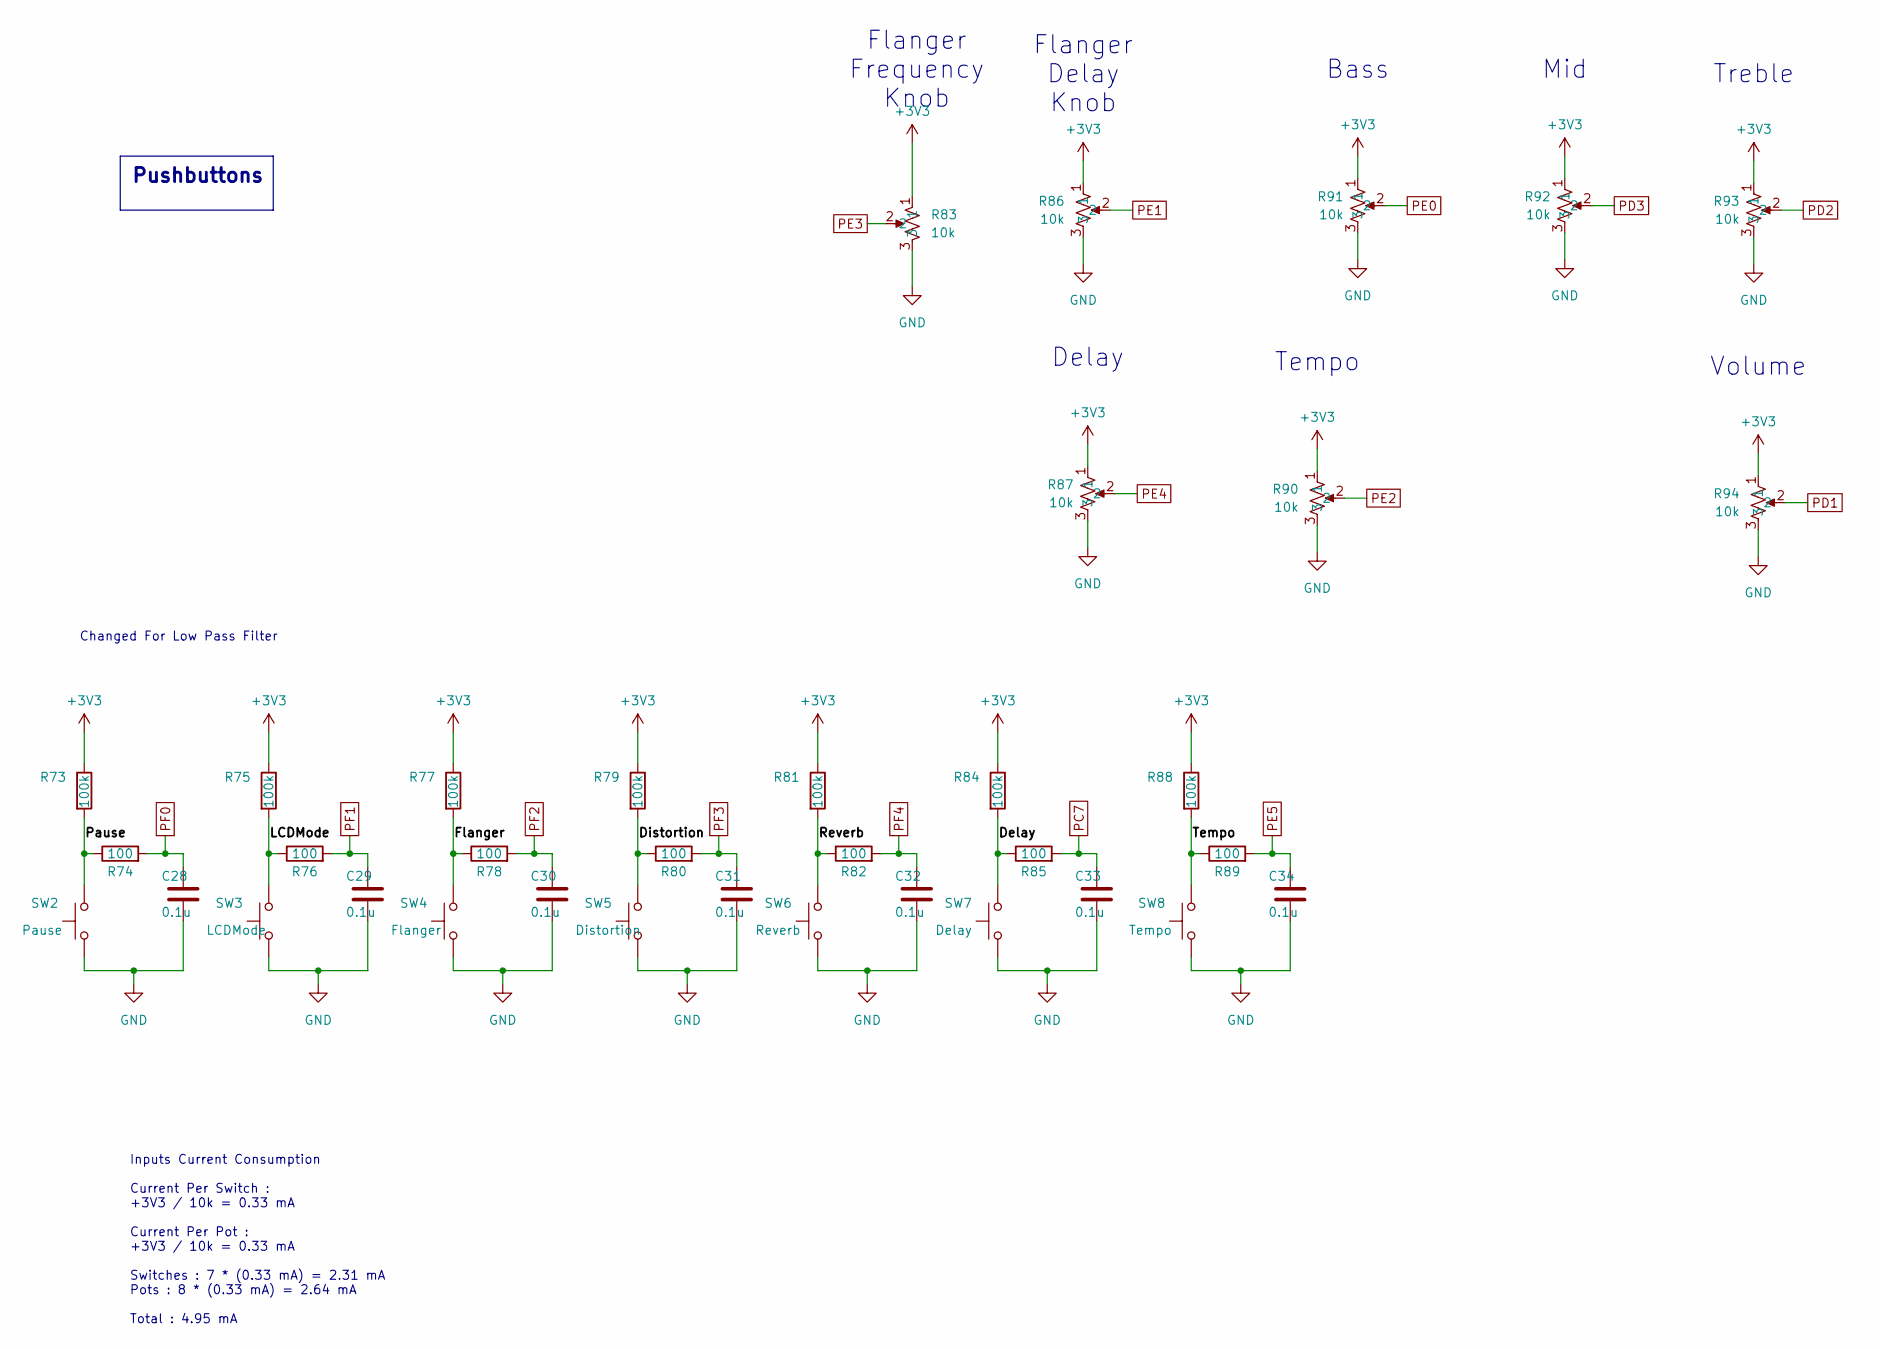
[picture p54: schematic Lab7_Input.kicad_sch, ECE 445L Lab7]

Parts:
C28, C29, C30, C31, C32, C33, C34: 0.1u; C_0603_1608Metric_Pad1.08x0.95mm_HandSolder
R73, R75, R77, R79, R81, R84, R88: 100k; R_0603_1608Metric_Pad0.98x0.95mm_HandSolder
R74, R76, R78, R80, R82, R85, R89: 100; R_0603_1608Metric_Pad0.98x0.95mm_HandSolder
R83, R86, R87, R90, R91, R92, R93, R94: 10k; P120PK-Y25BR10K
SW2: Pause; SW_PUSH_6mm
SW3: LCDMode; SW_PUSH_6mm
SW4: Flanger; SW_PUSH_6mm
SW5: Distortion; SW_PUSH_6mm
SW6: Reverb; SW_PUSH_6mm
SW7: Delay; SW_PUSH_6mm
SW8: Tempo; SW_PUSH_6mm

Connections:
+3V3: R73.1, R75.1, R77.1, R79.1, R81.1, R83.1, R84.1, R86.1, R87.1, R88.1, R90.1, R91.1, R92.1, R93.1, R94.1; also elsewhere on the board
/Lab7_Input/Delay: R84.2, R85.1, SW7.2
/Lab7_Input/Distortion: R79.2, R80.1, SW5.2
/Lab7_Input/Flanger: R77.2, R78.1, SW4.2
/Lab7_Input/LCDMode: R75.2, R76.1, SW3.2
/Lab7_Input/Pause: R73.2, R74.1, SW2.2
/Lab7_Input/Reverb: R81.2, R82.1, SW6.2
/Lab7_Input/Tempo: R88.2, R89.1, SW8.2
GND: C28.1, C29.1, C30.1, C31.1, C32.1, C33.1, C34.1, R83.3, R86.3, R87.3, R90.3, R91.3, R92.3, R93.3, R94.3, SW2.1, SW3.1, SW4.1, SW5.1, SW6.1, SW7.1, SW8.1; also elsewhere on the board
PC7: C33.2, R85.2; also elsewhere on the board
PD1: R94.2; also elsewhere on the board
PD2: R93.2; also elsewhere on the board
PD3: R92.2; also elsewhere on the board
PE0: R91.2; also elsewhere on the board
PE1: R86.2; also elsewhere on the board
PE2: R90.2; also elsewhere on the board
PE3: R83.2; also elsewhere on the board
PE4: R87.2; also elsewhere on the board
PE5: C34.2, R89.2; also elsewhere on the board
PF0: C28.2, R74.2; also elsewhere on the board
PF1: C29.2, R76.2; also elsewhere on the board
PF2: C30.2, R78.2; also elsewhere on the board
PF3: C31.2, R80.2; also elsewhere on the board
PF4: C32.2, R82.2; also elsewhere on the board

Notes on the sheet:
Inputs Current Consumption Current Per Switch : +3V3 / 10k = 0.33 mA Current Per Pot : +3V3 / 10k = 0.33 mA Switches : 7 * (0.33 mA) = 2.31 mA Pots : 8 * (0.33 mA) = 2.64 mA Total : 4.95 mA
Mid
Changed For Low Pass Filter
Flanger Delay Knob
Tempo
Volume
Treble
Flanger Frequency Knob
Delay
Bass
Pushbuttons

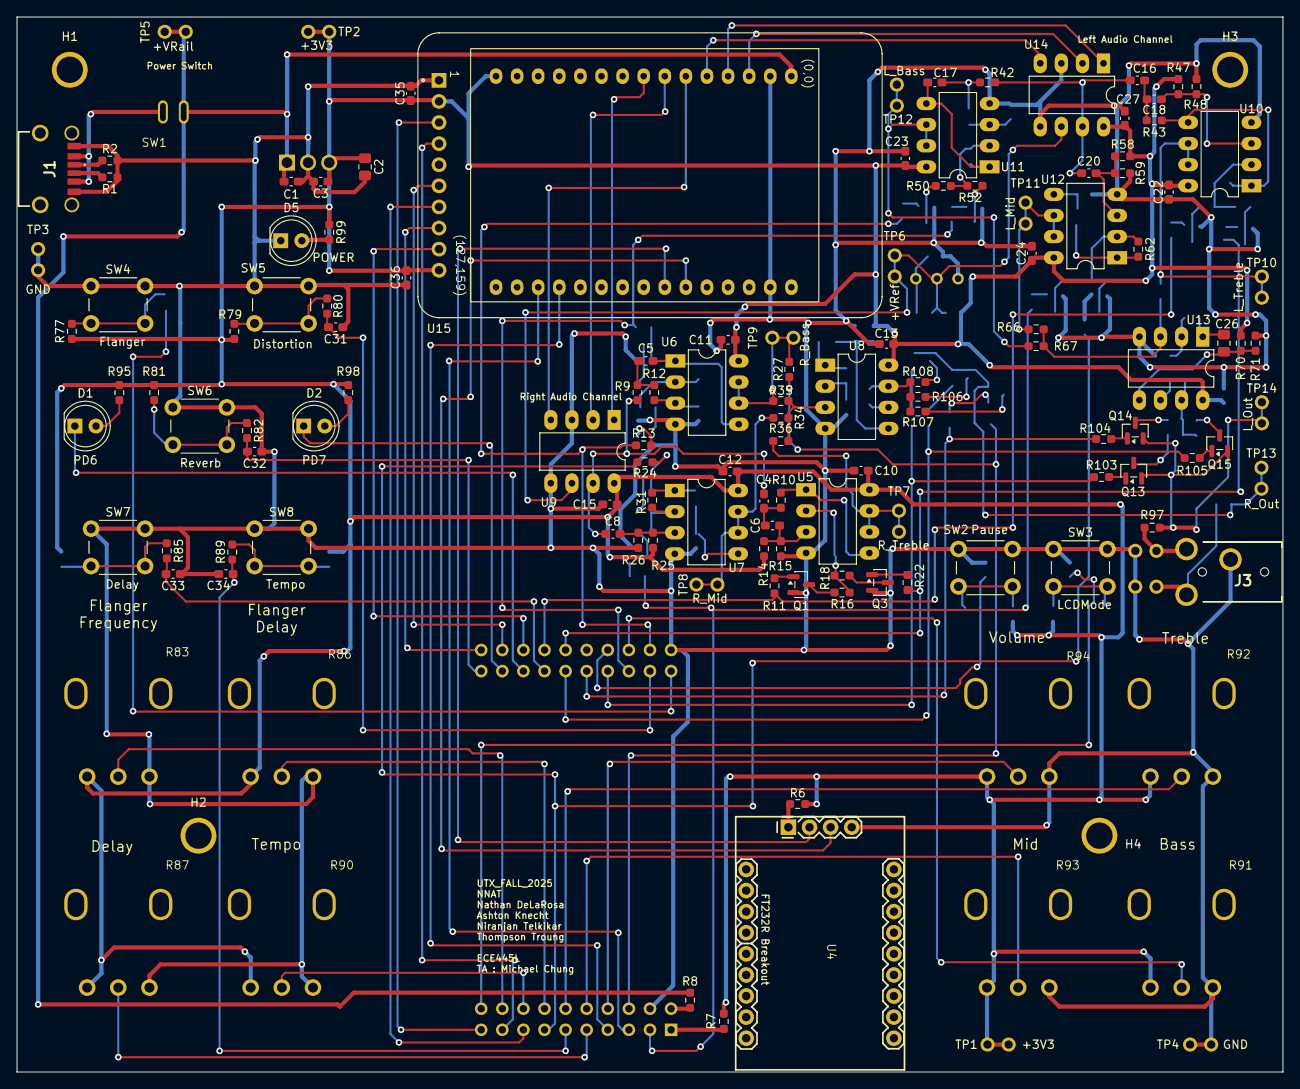
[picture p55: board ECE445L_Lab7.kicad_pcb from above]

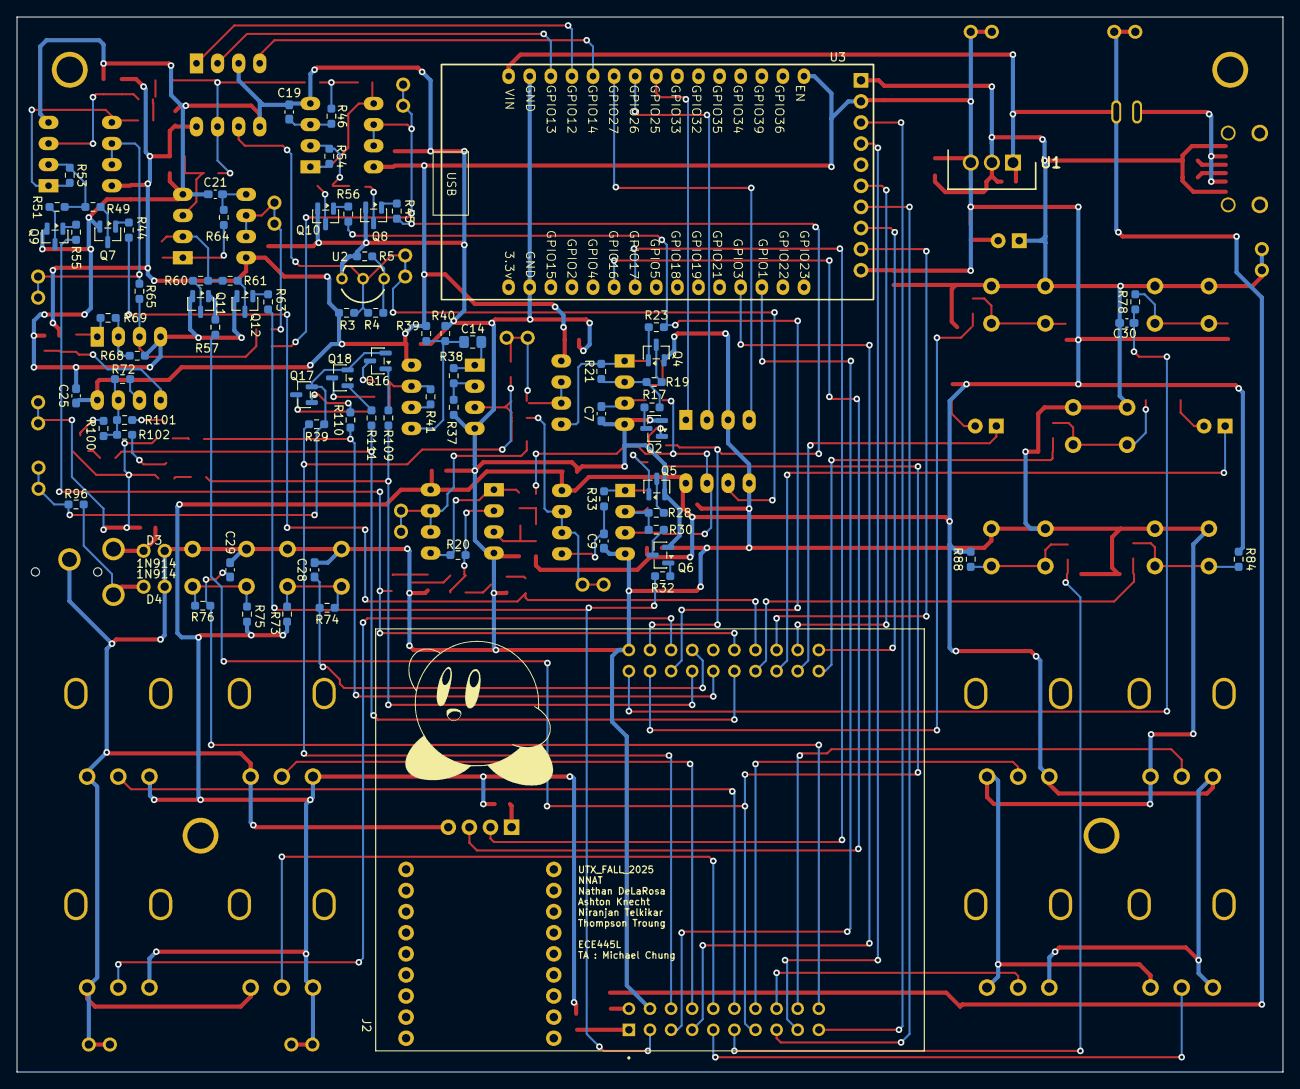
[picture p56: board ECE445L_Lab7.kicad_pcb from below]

Board: 2 copper layers, 152.4 x 127.0 mm, 215 parts (79 on the bottom side), 148 nets.

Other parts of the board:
G1: LOGO

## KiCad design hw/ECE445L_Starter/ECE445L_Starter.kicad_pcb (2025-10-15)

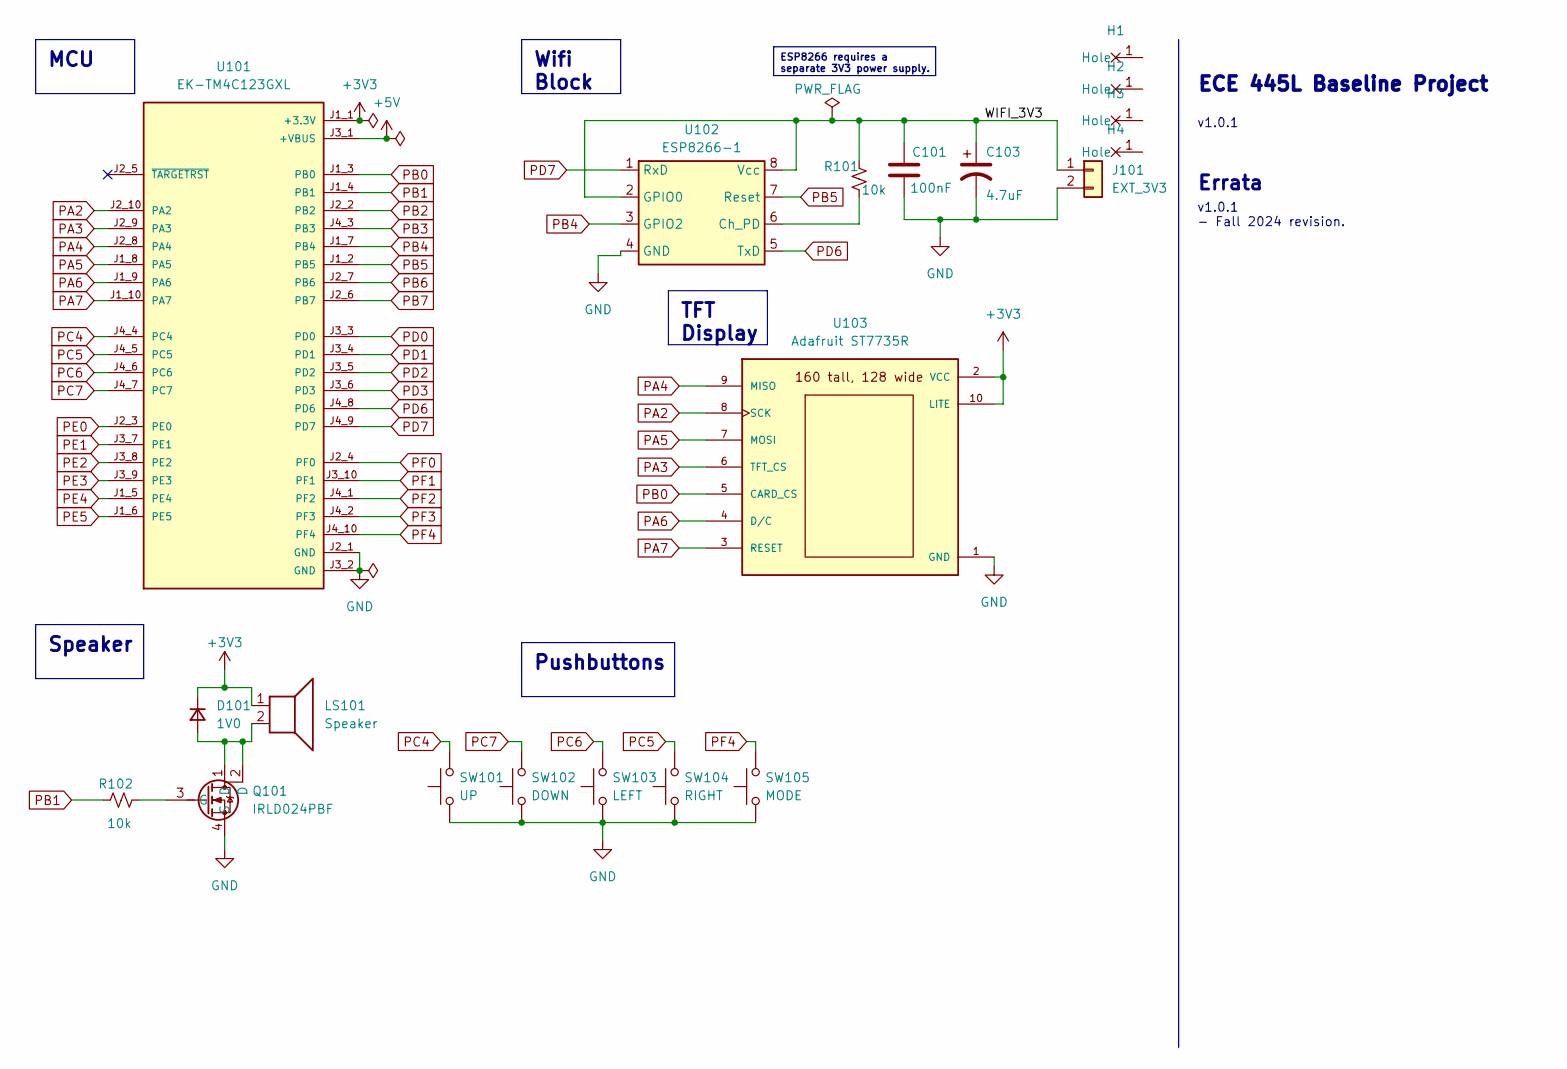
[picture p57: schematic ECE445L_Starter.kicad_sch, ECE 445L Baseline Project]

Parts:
C101: 100nF; C_Axial_200mil
C103: 4.7uF; CP_Radial_Tantal200mil
D101: 1V0; D_5W_P12.70mm_Horizontal
H1, H2, H3, H4: MountingHole_4_40
J101: EXT_3V3; Samtec_HPM-02-01-x-S_Straight_1x02_Pitch5.08mm
LS101: Speaker; PinHeader_1x02_P2.54mm_Vertical
Q101: IRLD024PBF; DIP920W60P254L490H457Q4N; Mouser Part Number 844-IRLD024PBF
R101, R102: 10k; R_Axial_DIN0204_L3.6mm_D1.6mm_P7.62mm_Horizontal
SW101: UP; SW_PUSH_6mm
SW102: DOWN; SW_PUSH_6mm
SW103: LEFT; SW_PUSH_6mm
SW104: RIGHT; SW_PUSH_6mm
SW105: MODE; SW_PUSH_6mm
U101: EK-TM4C123GXL; ti_EKTM4C123GXL
U102: ESP8266-1; PinHeader_2x04_P2.54mm_Vertical
U103: Adafruit ST7735R; adafruit_st7735r2

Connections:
+3V3: D101.1 (K), LS101.1, U101.J1_1 (+3.3V), U103.2 (VCC), U103.10 (LITE)
+5V: U101.J3_1 (+VBUS)
/WIFI_3V3: C101.1, C103.1, J101.1, R101.1, U102.2 (GPIO0), U102.8 (Vcc)
GND: C101.2, C103.2, J101.2, Q101.4 (S), SW101.1, SW102.1, SW103.1, SW104.1, SW105.1, U101.J2_1 (GND), U101.J3_2 (GND), U102.4 (GND), U103.1 (GND)
unnamed: D101.2 (A), LS101.2, Q101.1 (D), Q101.2 (D)
unnamed: Q101.3 (G), R102.2
unnamed: R101.2, U102.6 (Ch_PD)
PA2: U101.J2_10 (PA2), U103.8 (SCK)
PA3: U101.J2_9 (PA3), U103.6 (TFT_CS)
PA4: U101.J2_8 (PA4), U103.9 (MISO)
PA5: U101.J1_8 (PA5), U103.7 (MOSI)
PA6: U101.J1_9 (PA6), U103.4 (D/C)
PA7: U101.J1_10 (PA7), U103.3 (RESET)
PB0: U101.J1_3 (PB0), U103.5 (CARD_CS)
PB1: R102.1, U101.J1_4 (PB1)
PB2: U101.J2_2 (PB2)
PB3: U101.J4_3 (PB3)
PB4: U101.J1_7 (PB4), U102.3 (GPIO2)
PB5: U101.J1_2 (PB5), U102.7 (Reset)
PB6: U101.J2_7 (PB6)
PB7: U101.J2_6 (PB7)
PC4: SW101.2, U101.J4_4 (PC4)
PC5: SW104.2, U101.J4_5 (PC5)
PC6: SW103.2, U101.J4_6 (PC6)
PC7: SW102.2, U101.J4_7 (PC7)
PD0: U101.J3_3 (PD0)
PD1: U101.J3_4 (PD1)
PD2: U101.J3_5 (PD2)
PD3: U101.J3_6 (PD3)
PD6: U101.J4_8 (PD6), U102.5 (TxD)
PD7: U101.J4_9 (PD7), U102.1 (RxD)
PE0: U101.J2_3 (PE0)
PE1: U101.J3_7 (PE1)
PE2: U101.J3_8 (PE2)
PE3: U101.J3_9 (PE3)
PE4: U101.J1_5 (PE4)
PE5: U101.J1_6 (PE5)
PF0: U101.J2_4 (PF0)
PF1: U101.J3_10 (PF1)
PF2: U101.J4_1 (PF2)
PF3: U101.J4_2 (PF3)
PF4: SW105.2, U101.J4_10 (PF4)

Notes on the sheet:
MCU
ESP8266 requires a separate 3V3 power supply.
Speaker
Pushbuttons
TFT Display
Wifi Block
v1.0.1 - Fall 2024 revision.
ECE 445L Baseline Project
v1.0.1
Errata

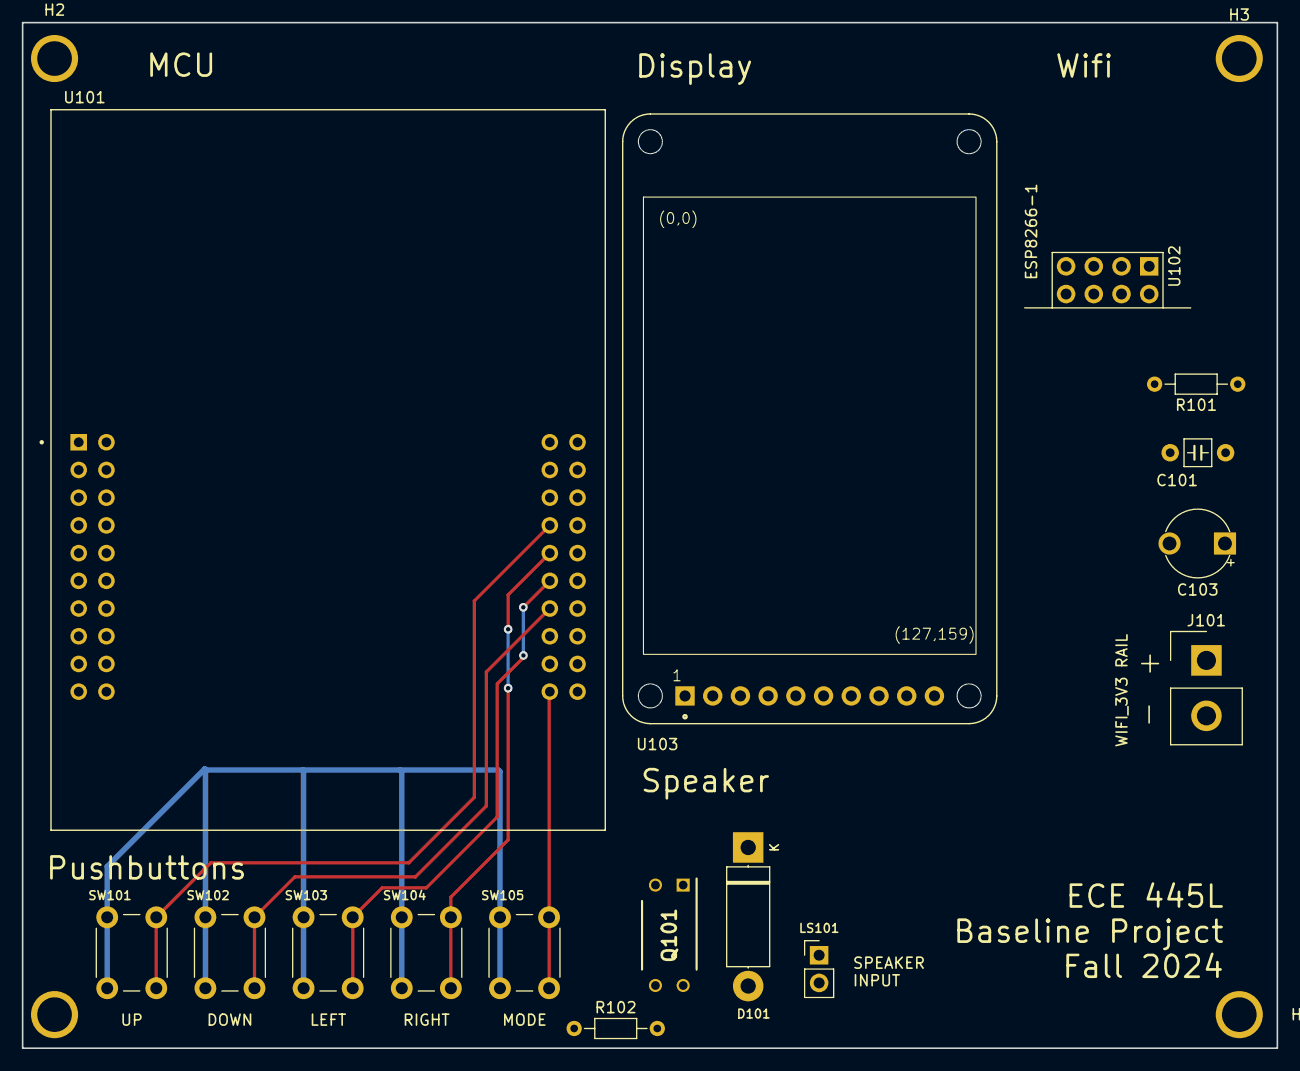
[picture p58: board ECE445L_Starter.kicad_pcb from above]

Board: 2 copper layers, 115.0 x 94.0 mm, 20 parts (0 on the bottom side), 23 nets.

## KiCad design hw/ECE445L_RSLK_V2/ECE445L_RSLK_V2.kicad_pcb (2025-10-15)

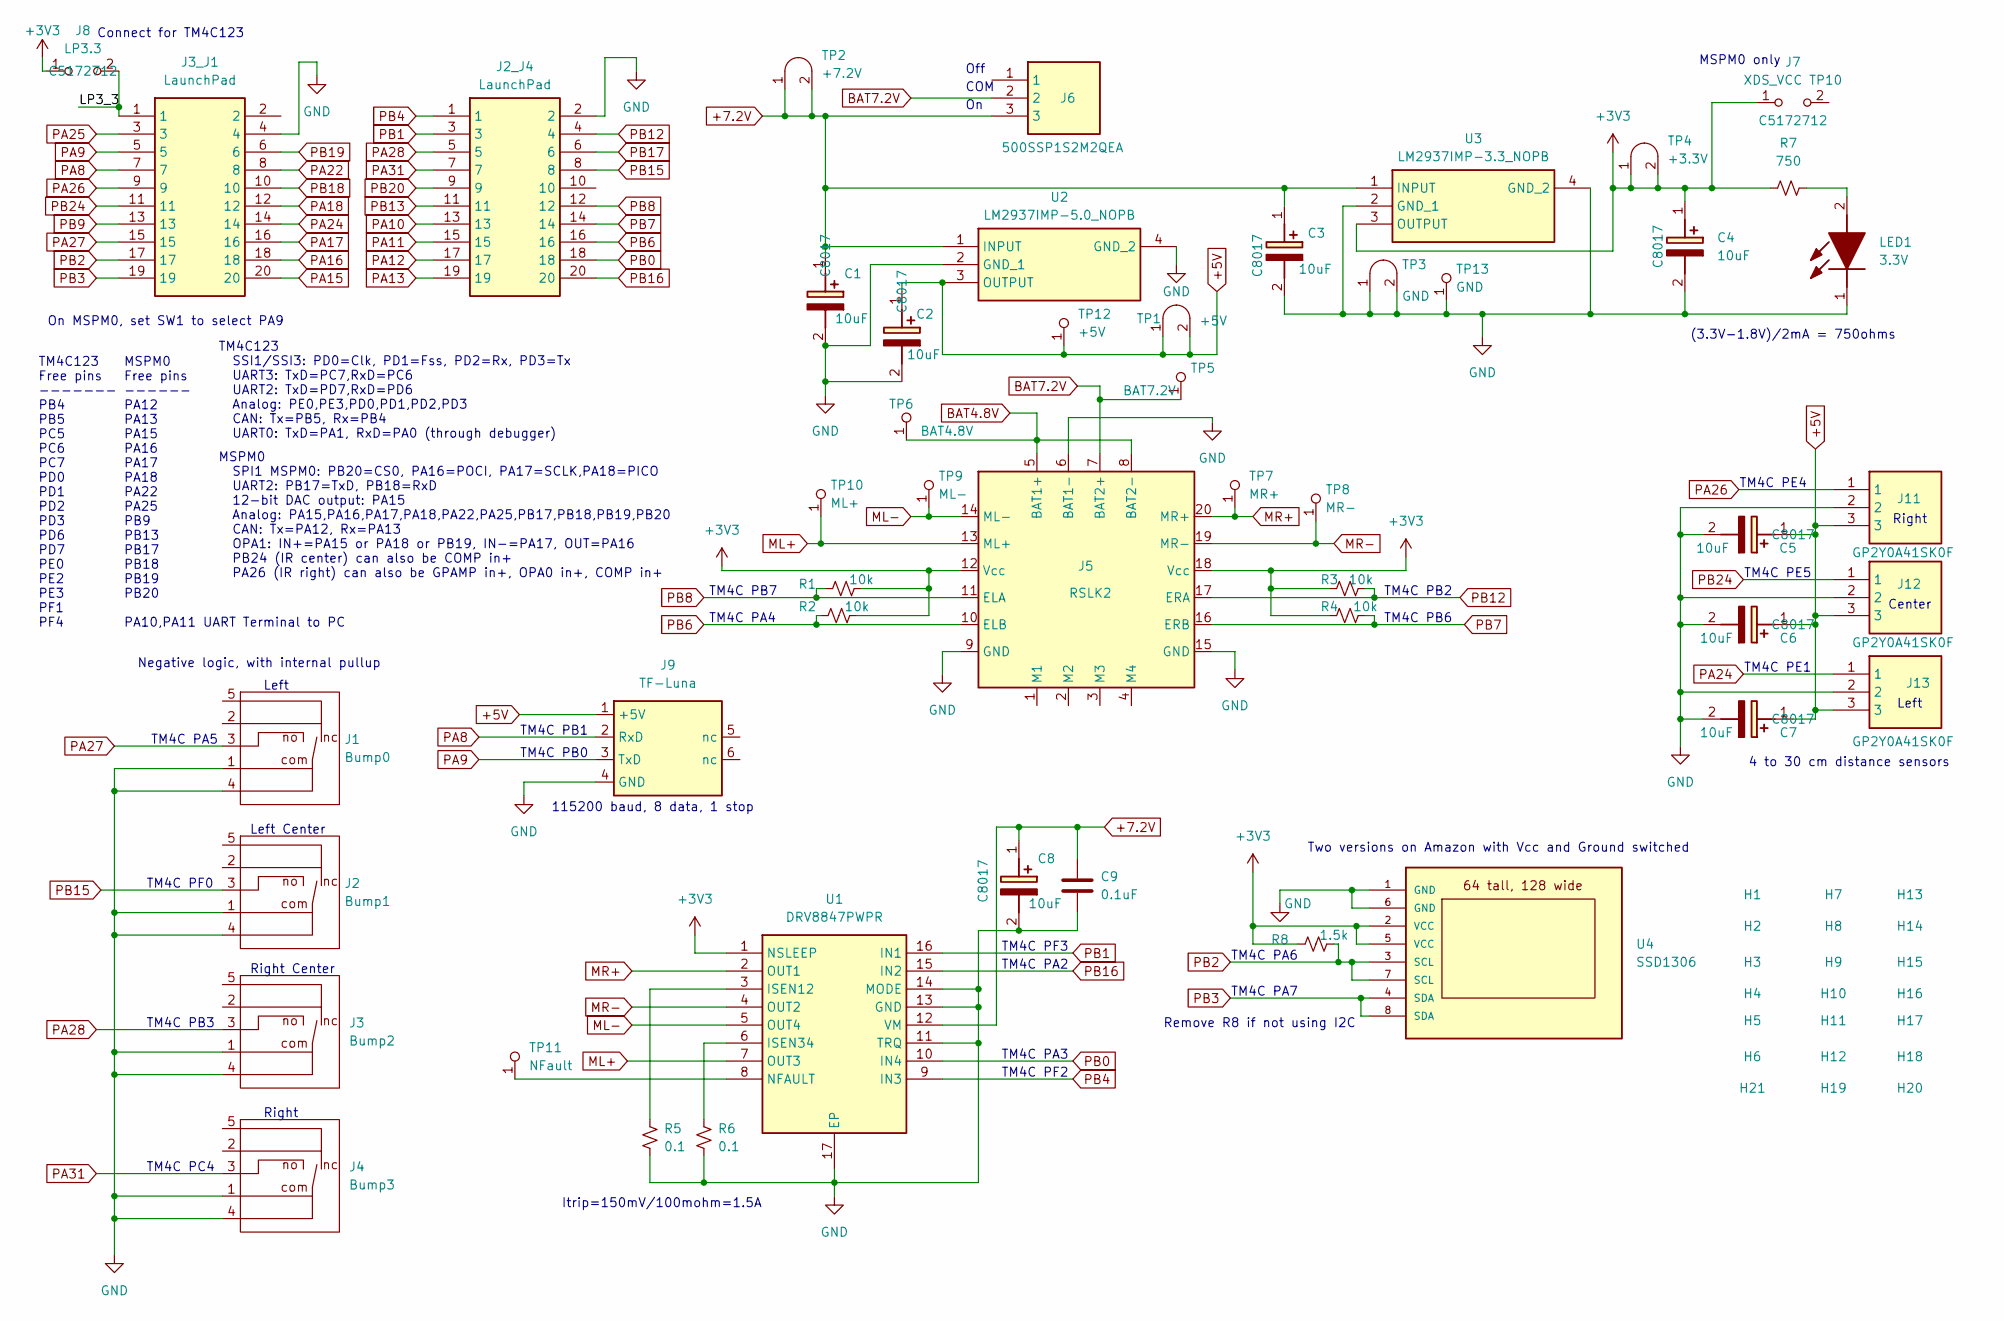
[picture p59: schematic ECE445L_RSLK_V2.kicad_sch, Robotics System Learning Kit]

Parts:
C1, C2, C3, C4, C5, C6, C7, C8: 10uF; CAPPM3528X210N; Mouser Part Number 581-TAJB106K020R
C9: 0.1uF; C_0603_1608Metric; LCSC C5186689
H1, H2, H3, H4, H5, H6, H7, H8, H9, H10, H11, H12, H13, H14, H15, H16, H17, H18, H19, H20, H21: MountingHole_4_40
J1: Bump0; D2F-01L30-D3_5pin
J2: Bump1; D2F-01L30-D3_5pin
J2_J4, J3_J1: LaunchPad; Mouser Part Number 855-M20-8761042P
J3: Bump2; D2F-01L30-D3_5pin
J4: Bump3; D2F-01L30-D3_5pin
J5: RSLK2; RSLK_Chassis
J6: 500SSP1S2M2QEA; Mouser Part Number 612-500SSP1S2M2QEA
J7: XDS_VCC TP10; PinHeader_1x02_P2.54mm_Vertical; LCSC C5172712
J8: LP3.3; PinHeader_1x02_P2.54mm_Vertical; LCSC C5172712
J9: TF-Luna; JST-GH_1x06_1.25mm
J11, J12, J13: GP2Y0A41SK0F; SHDR3W50P0X200_1X3_650X240X440P; Mouser Part Number 855-M22-7130342
LED1: 3.3V; APT1608CGCK; Mouser Part Number 604-APTD1608LSECKJ3F
R1, R2, R3, R4: 10k; R_0603_1608Metric; LCSC C340542
R5, R6: 0.1; R_1206_3216Metric; LCSC C2889036
R7: 750; R_0603_1608Metric; LCSC C365210
R8: 1.5k; R_0603_1608Metric; LCSC C216914
TP1: +5V; Testpoint_1x02_P2.54mm
TP2: +7.2V; Testpoint_1x02_P2.54mm
TP3: GND; Testpoint_1x02_P2.54mm
TP4: +3.3V; Testpoint_1x02_P2.54mm
TP5: BAT7.2V; Testpoint_1x1
TP6: BAT4.8V; Testpoint_1x1
TP7: MR+; Testpoint_1x1
TP8: MR-; Testpoint_1x1
TP9: ML-; Testpoint_1x1
TP10: ML+; Testpoint_1x1
TP11: NFault; Testpoint_1x1
TP12: +5V; Testpoint_1x1
TP13: GND; Testpoint_1x1
U1: DRV8847PWPR; SOP65P640X120-17N; Mouser Part Number 595-DRV8847PWPR
U2: LM2937IMP-5.0_NOPB; SOT230P700X180-4N; Mouser Part Number 926-LM2937IMP5.0NOPB
U3: LM2937IMP-3.3_NOPB; SOT230P700X180-4N; Mouser Part Number 926-LM2937IMP3.3NOPB
U4: SSD1306

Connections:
+3V3: C4.1 (+), J5.12 (Vcc), J5.18 (Vcc), J7.1 (A), J8.1 (A), R1.2, R2.2, R3.1, R4.1, R7.2, R8.1, TP4.1 (A), TP4.2 (B), U1.1 (NSLEEP), U3.3 (OUTPUT), U4.2 (VCC), U4.5 (VCC)
+5V: C2.1 (+), C5.1 (+), C6.1 (+), C7.1 (+), J9.1 (+5V), J11.3, J12.3, J13.3, TP1.1 (A), TP1.2 (B), TP12.1 (A), U2.3 (OUTPUT)
+7.2V: C1.1 (+), C3.1 (+), C8.1 (+), C9.1, J6.3, TP2.1 (A), TP2.2 (B), U1.12 (VM), U2.1 (INPUT), U3.1 (INPUT)
/LP3_3: J3_J1.1, J8.2 (B)
BAT4.8V: J5.5 (BAT1+), J5.8 (BAT2-), TP6.1 (A)
BAT7.2V: J5.7 (BAT2+), J6.2, TP5.1 (A)
GND: C1.2 (-), C2.2 (-), C3.2 (-), C4.2 (-), C5.2 (-), C6.2 (-), C7.2 (-), C8.2 (-), C9.2, J1.1 (com), J1.4 (com), J2.1 (com), J2.4 (com), J2_J4.2, J3.1 (com), J3.4 (com), J3_J1.4, J4.1 (com), J4.4 (com), J5.6 (BAT1-), J5.9 (GND), J5.15 (GND), J9.4 (GND), J11.2, J12.2, J13.2, LED1.1 (K), R5.2, R6.2, TP3.1 (A), TP3.2 (B), TP13.1 (A), U1.11 (TRQ), U1.13 (GND), U1.14 (MODE), U1.17 (EP), U2.2 (GND_1), U2.4 (GND_2), U3.2 (GND_1), U3.4 (GND_2), U4.1 (GND), U4.6 (GND)
ML+: J5.13 (ML+), TP10.1 (A), U1.7 (OUT3)
ML-: J5.14 (ML-), TP9.1 (A), U1.5 (OUT4)
MR+: J5.20 (MR+), TP7.1 (A), U1.2 (OUT1)
MR-: J5.19 (MR-), TP8.1 (A), U1.4 (OUT2)
unnamed: LED1.2 (A), R7.1
unnamed: TP11.1 (A), U1.8 (NFAULT)
unnamed: R5.1, U1.3 (ISEN12)
unnamed: R6.1, U1.6 (ISEN34)
PA8: J3_J1.7, J9.2 (RxD)
PA9: J3_J1.5, J9.3 (TxD)
PA10: J2_J4.13
PA11: J2_J4.15
PA12: J2_J4.17
PA13: J2_J4.19
PA15: J3_J1.20
PA16: J3_J1.18
PA17: J3_J1.16
PA18: J3_J1.12
PA22: J3_J1.8
PA24: J3_J1.14, J13.1
PA25: J3_J1.3
PA26: J3_J1.9, J11.1
PA27: J1.3 (no), J3_J1.15
PA28: J2_J4.5, J3.3 (no)
PA31: J2_J4.7, J4.3 (no)
PB0: J2_J4.18, U1.10 (IN4)
PB1: J2_J4.3, U1.16 (IN1)
PB2: J3_J1.17, R8.2, U4.3 (SCL), U4.7 (SCL)
PB3: J3_J1.19, U4.4 (SDA), U4.8 (SDA)
PB4: J2_J4.1, U1.9 (IN3)
PB6: J2_J4.16, J5.10 (ELB), R2.1
PB7: J2_J4.14, J5.16 (ERB), R4.2
PB8: J2_J4.12, J5.11 (ELA), R1.1
PB9: J3_J1.13
PB12: J2_J4.4, J5.17 (ERA), R3.2
PB13: J2_J4.11
PB15: J2.3 (no), J2_J4.8
PB16: J2_J4.20, U1.15 (IN2)
PB17: J2_J4.6
PB18: J3_J1.10
PB19: J3_J1.6
PB20: J2_J4.9
PB24: J3_J1.11, J12.1

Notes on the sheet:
TM4C PB7
TM4C PE5
Negative logic, with internal pullup
TM4C PF2
TM4C PC4
115200 baud, 8 data, 1 stop
Right
TM4C PA3
MSPM0 Free pins ------ PA12 PA13 PA15 PA16 PA17 PA18 PA22 PA25 PB9 PB13 PB17 PB18 PB19 PB20 PA10,PA11 UART Terminal to PC
TM4C PB2
TM4C123 Free pins ------- PB4 PB5 PC5 PC6 PC7 PD0 PD1 PD2 PD3 PD6 PD7 PE0 PE2 PE3 PF1 PF4
TM4C PA4
Left Center
Connect for TM4C123
Left
TM4C PF3
TM4C PA6
MSPM0 SPI1 MSPM0: PB20=CS0, PA16=POCI, PA17=SCLK,PA18=PICO UART2: PB17=TxD, PB18=RxD 12-bit DAC output: PA15 Analog: PA15,PA16,PA17,PA18,PA22,PA25,PB17,PB18,PB19,PB20 CAN: Tx=PA12, Rx=PA13 OPA1: IN+=PA15 or PA18 or PB19, IN-=PA17, OUT=PA16 PB24 (IR center) can also be COMP in+ PA26 (IR right) can a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
TM4C PB1
TM4C PF0
Two versions on Amazon with Vcc and Ground switched
Itrip=150mV/100mohm=1.5A
TM4C PA5
Off
4 to 30 cm distance sensors
TM4C PB6
On MSPM0, set SW1 to select PA9
Remove R8 if not using I2C
TM4C PB0
Right Center
Center
TM4C PE4
(3.3V-1.8V)/2mA = 750ohms
TM4C PB3
TM4C PA7
MSPM0 only
COM
TM4C PE1
TM4C PA2
TM4C123 SSI1/SSI3: PD0=Clk, PD1=Fss, PD2=Rx, PD3=Tx UART3: TxD=PC7,RxD=PC6 UART2: TxD=PD7,RxD=PD6 Analog: PE0,PE3,PD0,PD1,PD2,PD3 CAN: Tx=PB5, Rx=PB4 UART0: TxD=PA1, RxD=PA0 (through debugger)



Board: 2 copper layers, 128.3 x 129.5 mm, 70 parts (2 on the bottom side), 34 nets.

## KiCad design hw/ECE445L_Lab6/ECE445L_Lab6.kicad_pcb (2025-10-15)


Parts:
C1, C2: 10pF C0G; C_Axial_200mil
C3, C9: 1uF; C_Axial_200mil
C4, C6, C7, C8: 0.1uF; C_Axial_200mil
C5, C11: 0.01uF; C_Axial_200mil
C10: 2.2uF; CP_Radial_Tantal200mil
C12, C13: 4.7uF; CP_Radial_Tantal200mil
D1: LED; LED_D5.0mm
H1, H2, H3, H4: MountingHole_4_40
J1: JTAG; PinHeader_1x05_P2.54mm_Vertical
J2: Battery; PinHeader_1x02_P2.54mm_Vertical
R1: 1M; R_Axial_DIN0204_L3.6mm_D1.6mm_P7.62mm_Horizontal
R2, R3: 10k; R_Axial_DIN0204_L3.6mm_D1.6mm_P7.62mm_Horizontal
SW1: Reset; SW_PUSH_6mm
SW2: Input; SW_PUSH_6mm
TP1: +3.7V; Testpoint_1x02_P2.54mm
TP2: GND; Testpoint_1x02_P2.54mm
TP3: +3.3V; Testpoint_1x02_P2.54mm
U1: TM4C123GH6PMIR; QFP50P1200X1200X160-64N; Mouser Part Number 595-TM4C123GH6PMIR
U2: Adafruit ST7735R; adafruit_st7735r2
U3: LP2950-33LPRE3; TL431CLPM; Mouser Part Number 595-LP2950-33LPRE3
Y1: ABM3-16.000MHZ-B2-T; ABM3; Mouser Part Number 815-ABM3-16-B2-T

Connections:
+3V3: C3.1, C5.1, C6.1, C7.1, C11.1, C13.1, R1.1, R2.1, TP3.1 (A), TP3.2 (B), U1.2 (VDDA), U1.11 (VDD_1), U1.26 (VDD_2), U1.37 (VBAT), U1.42 (VDD_3), U1.54 (VDD_4), U3.1 (OUTPUT)
/+3_7V: C12.1, J2.2 (B), TP1.1 (A), TP1.2 (B), U3.3 (INPUT)
/LDO: C4.1, C8.1, C9.1, C10.1, U1.25 (VDDC_1), U1.56 (VDDC_2)
/OSC1: C1.1, U1.41 (OSC1), Y1.2
/OSC2: C2.1, U1.40 (OSC0), Y1.1
/Reset: R2.2, SW1.2, U1.38 (~RST)
/TCK: J1.2 (B), U1.52 (PC0/TCK/SWCLK)
/TDI: J1.4 (C), U1.50 (PC2/TDI)
/TDO: J1.5 (C), U1.49 (PC3/TDO/SWO)
/TMS: J1.3 (C), U1.51 (PC1/TMS/SWDIO)
GND: C1.2, C2.2, C3.2, C4.2, C5.2, C6.2, C7.2, C8.2, C9.2, C10.2, C11.2, C12.2, C13.2, J1.1 (A), J2.1 (A), SW1.1, TP2.1 (A), TP2.2 (B), U1.3 (GNDA), U1.12 (GND_1), U1.27 (GND_2), U1.34 (XOSC0), U1.35 (GNDX), U1.39 (GND_3), U1.55 (GND_4), U3.2 (GND)
unnamed: R1.2, U1.32 (~WAKE)
PA0: U1.17 (PA0/U0RX)
PA1: U1.18 (PA1/U0TX)
PA2: U1.19 (PA2/SSI0C1K)
PA3: U1.20 (PA3/SSI0FSS)
PA4: U1.21 (PA4/SSI0RX)
PA5: U1.22 (PA5/SSI0TX)
PA6: U1.23 (PA6)
PA7: U1.24 (PA7)
PB0: U1.45 (PB0/USB0ID)
PB1: U1.46 (PB1/USB0VBUS)
PB2: U1.47 (PB2/I2C0SCL)
PB3: U1.48 (PB3/I2C0SDA)
PB4: U1.58 (PB4)
PB5: U1.57 (PB5)
PB6: U1.1 (PB6)
PB7: U1.4 (PB7)
PC4: U1.16 (PC4)
PC5: U1.15 (PC5)
PC6: U1.14 (PC6)
PC7: U1.13 (PC7)
PD0: U1.61 (PD0)
PD1: U1.62 (PD1)
PD2: U1.63 (PD2)
PD3: U1.64 (PD3)
PD4: U1.43 (PD4)
PD5: U1.44 (PD5)
PD6: U1.53 (PD6)
PD7: U1.10 (PD7)
PE0: U1.9 (PE0)
PE1: U1.8 (PE1)
PE2: U1.7 (PE2)
PE3: U1.6 (PE3)
PE4: U1.59 (PE4)
PE5: U1.60 (PE5)
PF0: U1.28 (PF0)
PF1: U1.29 (PF1)
PF2: U1.30 (PF2)
PF3: U1.31 (PF3)
PF4: U1.5 (PF4)

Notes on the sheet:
Your name, your EID


Board: 2 copper layers, 114.4 x 88.9 mm, 32 parts (0 on the bottom side), 12 nets.

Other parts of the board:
D2: LED; LED_D5.0mm

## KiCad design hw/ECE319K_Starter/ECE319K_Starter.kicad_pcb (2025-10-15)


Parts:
C1: 1uF; CP_Radial_Tantal200mil
C2: 4.7uF; CP_Radial_Tantal200mil
C3: 0.1uF; C_Axial_200mil
D1, D2, D3: LED; LED_D5.0mm
H1, H2, H3, H4: MountingHole_4_40
J1: AudioJack; Jack_3.5mm_CUI_SJ1-3523N_Horizontal
J2: Speaker; PinHeader_1x02_P2.54mm_Vertical
J3: UART1; PinHeader_1x03_P2.54mm_Vertical
J4: Pot; Testpoint_1x02_P2.54mm
J6: GND; Testpoint_1x02_P2.54mm
J7: DACOUT; Testpoint_1x02_P2.54mm
JP1: TExaS; PinHeader_1x03_P2.54mm_Vertical
R1, R2, R3: 470; R_Axial_DIN0204_L3.6mm_D1.6mm_P7.62mm_Horizontal
R4, R5, R6, R7, R8: 1.5k; R_Axial_DIN0204_L3.6mm_D1.6mm_P7.62mm_Horizontal
R9, R10, R11: 12k; R_Axial_DIN0204_L3.6mm_D1.6mm_P7.62mm_Horizontal
R12, R13, R14, R15, R17: 10k; R_Axial_DIN0204_L3.6mm_D1.6mm_P7.62mm_Horizontal
R16: 20k; R_Axial_DIN0204_L3.6mm_D1.6mm_P7.62mm_Horizontal
RV1: PTA2043; PTA2043pot
SW1: UP; SW_PUSH_6mm
SW2: LEFT; SW_PUSH_6mm
SW3: DOWN; SW_PUSH_6mm
SW4: RGHT; SW_PUSH_6mm
TP1: 3.3V; Testpoint_1x02_P2.54mm
U1: Adafruit ST7735R; adafruit_st7735r2
U2: LP-MSPM0G3507; ti_LP_MSPM0G3507
U3: MCP34119P; DIP-8_W7.62mm_LongPads
U4: HiLetGo_ST7735R; hiletgo_st7735r

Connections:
+3V3: TP1.1 (A), TP1.2 (B), U1.2 (VCC), U1.10 (LITE), U2.J1_1 (+3.3V), U4.2 (VCC), U4.15 (LED+)
+5V: U2.J3_1 (+VBUS)
GND: J3.1 (A), J6.1 (A), J6.2 (B), U1.1 (GND), U2.J2_1 (GND), U2.J3_2 (GND), U4.1 (GND), U4.16 (LED-)
PA8: J3.2 (B), U2.J1_4 (PA8)
PA10: U2.J4_7 (PA10)
PA11: U2.J4_8 (PA11)
PA12: U1.5 (CARD_CS), U2.J4_9 (PA12), U4.14 (SDC_CS)
PA13: U1.4 (D/C), U2.J4_10 (PA13), U4.7 (TFTDC)
PA15: U2.J3_10 (PA15)
PA16: U2.J3_9 (PA16)
PA17: U2.J3_8 (PA17)
PA18: U2.J3_6 (PA18)
PA22: J3.3 (C), U2.J3_4 (PA22)
PA24: U2.J3_7 (PA24)
PA25: U2.J1_2 (PA25)
PA26: U2.J1_5 (PA26)
PA27: U2.J1_8 (PA27)
PA28: U2.J4_3 (PA28)
PA31: U2.J4_4 (PA31)
PB0: U2.J2_9 (PB0)
PB1: U2.J4_2 (PB1)
PB2: U2.J1_9 (PB2)
PB3: U2.J1_10 (PB3)
PB4: U2.J4_1 (PB4)
PB6: U1.6 (TFT_CS), U2.J2_8 (PB6), U4.10 (TFT_CS)
PB7: U1.9 (MISO), U2.J2_7 (PB7), U4.12 (SDC_MISO)
PB8: U1.7 (MOSI), U2.J2_6 (PB8), U4.8 (TFTMOSI), U4.13 (SDC_MOSI)
PB9: U1.8 (SCK), U2.J1_7 (PB9), U4.9 (TFTSCK), U4.11 (SDCSCK)
PB12: U2.J2_2 (PB12)
PB13: U2.J4_6 (PB13)
PB15: U1.3 (RESET), U2.J2_4 (PB15), U4.6 (RESET)
PB16: U2.J2_10 (PB16)
PB17: U2.J2_3 (PB17)
PB18: U2.J3_5 (PB18)
PB19: U2.J3_3 (PB19)
PB20: JP1.2 (C), U2.J4_5 (PB20)
PB23: U2.J1_3 (PA9/PB23)
PB24: U2.J1_6 (PB24)

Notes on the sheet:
U2_Rx
U1_Tx

Board: 2 copper layers, 44 parts (1 on the bottom side), 12 nets, no tracks yet.

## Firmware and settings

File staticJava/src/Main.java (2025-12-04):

import javax.sound.sampled.*;
import java.io.*;

public class Main {
    public static void main(String[] args) throws IOException, UnsupportedAudioFileException, InterruptedException {
    new Audio("C:/Users/niran/Desktop/ECE445L/LabStarterFilesCCS/lab-7-and-10-project-nnat/staticJava/WAVfiles/need2.wav");
       // new Audio("C:/Users/ashto/Dev/ECE445L/lab-7-and-10-project-nnat/staticJava/WAVfiles/need2.wav");
    }
}

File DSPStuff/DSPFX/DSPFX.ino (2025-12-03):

uint16_t inputdata[10];
bool flangerFlag;
bool pauseFlag;
bool distortionFlag;
bool reverbFlag;
bool delayFlag;
bool tempoFlag;

#define INPUT_SCALE_FACTOR 0.0003125
#define OUTPUT_SCALE_FACTOR 3200.0

void setup() {
  // put your setup code here, to run once:
  ESPUARTsetup();
  for (int i = 0; i < 10; i++) {
    inputdata[i] = 0;
  }
  flangerFlag = false;
  pauseFlag = false;
  distortionFlag = false;
  reverbFlag = false;
  delayFlag = false;
  tempoFlag = false;
}
void loop() { // assuming left and right samples sent

  if (UARTReceive(&inputdata[0])) {
    if (inputdata[9] & 0x1) { // Pause Button
      pauseFlag = !pauseFlag;
    }
    if (inputdata[9] & 0x4) { // Flanger Button
      flangerFlag = !flangerFlag;
    }
    if (inputdata[9] & 0x8) { // Distortion Button
      distortionFlag = !distortionFlag;
    }
    if (inputdata[9] & 0x10) { // Reverb Button
      reverbFlag = !reverbFlag;
    }
    if (inputdata[9] & 0x20) { // Tempo Button
      tempoFlag = !tempoFlag;
    }
    if (inputdata[9] & 0x80) { // Delay Button
      delayFlag = !delayFlag;
    }
  }


  if (flangerFlag) {
    //outputsampledata = flanger_process_left_sample(outputsampledata);
  }
  if (tempoFlag) {

  }
  if (pauseFlag) {

  }
  if (delayFlag) {
    //outputsampledata = delay_process_left_sample(outputsampledata);
  }
  if (reverbFlag) {
    
  }
  if (distortionFlag) {
    //outputsampledata = distortion_process_left_sample(outputsampledata); // if we have stereo, have a left and right
  }
  //return outputsampledata;
}

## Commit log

2025-10-20 Created spice models for analog circuits, started kicad schematic -> right audio channel, screen, basic power
    [ECE445L_Lab7.kicad_sch, Lab7_Input.kicad_sch, Lab7_Output.kicad_sch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]
2025-10-20 Small filter changes :P
2025-10-22 Updated hardware schematic
    [ECE445L_Lab7.kicad_sch, Lab7_Input.kicad_sch, Lab7_LeftAudio.kicad_sch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]
2025-10-22 updated BOM
    [Lab7BOM.xlsx]
2025-10-22 Updated Schematic
2025-10-22 More Updates to hardware
    [Lab7BOM.xlsx, Lab7_Input.kicad_sch, Lab7_LeftAudio.kicad_sch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]
2025-10-23 added initial draft for sending sample rate through the port
2025-10-24 sending init data after sample rate
2025-10-26 Simple UART Read Test from USB-UART Adapter
2025-10-27 tm4c starter code
    [Instruments.xls, Waveforms.xlsx, dac_flute.xls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]
2025-10-27 Lab7A Schematic and BOM - Ashton
    [ECE445L_Lab7.kicad_sch, Lab7BOM.xlsx, Lab7_Input.kicad_sch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]
2025-10-27 switches and pots inits
2025-10-29 Made changers to the schematic, updated bom, and created priliminary layout for the PCB. Ready for 7B Prep!
    [2479774-1.stp, ECE445L_Lab7.kicad_pcb, Lab7BOM.xlsx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]
2025-10-29 Pushing layout for merge
    [ECE445L_Lab7.kicad_pcb]
2025-10-31 Parts layout part 2
    [ECE445L_Lab7.kicad_pcb]
2025-10-31 Rough draft layout - need to remove tm4c chip
    [2479774-1.stp, ECE445L_Lab7.kicad_pcb, ECE445L_Lab7.kicad_sch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]
2025-11-01 Added current consumption to schematic
    [Lab7BOM.xlsx, Lab7_Input.kicad_sch, Lab7_LeftAudio.kicad_sch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]
2025-11-01 Updated lab7a report
    [Lab7_Input.kicad_sch, Lab7_LeftAudio.kicad_sch, Lab7_RightAudio.kicad_sch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]
2025-11-01 Updated bom, ready for lab7a report
    [Lab7BOM.xlsx]
2025-11-03 PCB Layout
    [ECE445L_Lab7.kicad_pcb, FT232R-Breakout_v37.sch, Lab7_Input.kicad_sch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]
2025-11-03 Hardware layout - fixed voltage reference
    [ECE445L_Lab7.kicad_pcb, Lab7_power.kicad_sch]
2025-11-04 Pushing so i can work on my desktop
    [ECE445L_Lab7.kicad_pcb, Lab7_Input.kicad_sch, Lab7_LeftAudio.kicad_sch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]
2025-11-04 Final PCB commit
    [ECE445L_Lab7.kicad_pcb, ECE445L_Lab7.kicad_sch, Lab7_Input.kicad_sch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]
2025-11-05 fixed java reading wav
    [Main.java]
2025-11-08 Updated bom for lab 7B
    [Lab7BOM.xlsx, Lab7_Output.kicad_sch]
2025-11-14 added webapp directory and put current frontend in it
2025-11-18 Fixed ADC Init Error Redefined
    [Visualizer.c]
2025-11-20 Finished inputs and uart v1 (NOT TESTED)
2025-11-29 arduino ide was not saved
2025-11-29 fixed uart0 to uart1
    [AudioCommands.c]
2025-11-29 fixing ADC code
2025-11-30 added arduino code
2025-12-03 Fixed analog volume control - 1 and 2 are still switched
    [Lab7.c, Volume.c]
2025-12-03 Update Switch.c (uint16_t)
2025-12-03 Update Switch.h (uint16_t)
2025-12-04 initilized adc for testing
2025-12-04 Tested and did bug fixes to knobs, changed visualizer to use PD0 like required on the PCB - Bass, Mid, Treble and Volume/Analog Distortion all work - sound works with Need 2
    [AudioCommands.c, Lab7.c, Pot.c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]
2025-12-04 Mini fix for treble
    [Volume.c]
2025-12-04 WIP before switching branches

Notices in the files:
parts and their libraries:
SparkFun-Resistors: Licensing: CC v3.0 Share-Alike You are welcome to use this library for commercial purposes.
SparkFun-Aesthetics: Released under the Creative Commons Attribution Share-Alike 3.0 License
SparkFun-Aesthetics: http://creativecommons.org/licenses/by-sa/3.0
